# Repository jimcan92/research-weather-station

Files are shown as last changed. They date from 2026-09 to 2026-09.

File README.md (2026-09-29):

# Weather Station Sensor Network

ESP32 field sensors → LoRa 915 MHz → Raspberry Pi gateway → Ryzen 5 server (PostgreSQL + Grafana)

## Architecture

```
ESP32 Nodes (solar + battery)
  │  Sensors: BME280, DS18B20, rain gauge, anemometer, wind vane, soil moisture
  │  Radio:   E22-900T22D UART LoRa @ 915 MHz band
  │  Firmware: PlatformIO / Arduino framework
  │
  ▼ LoRa packets (JSON)
Raspberry Pi Gateway (near server)
  │  HAT:      LoRa concentrator or single-channel SX1276
  │  Software: Python MQTT bridge (lora_gateway.py)
  │
  ▼ MQTT (mosquitto)
Ryzen 5 Server (Ubuntu)
  │  Ingestor: Node.js/TypeScript → PostgreSQL
  │  Dashboard: Grafana (future: SvelteKit)
  └── PostgreSQL: raw readings + daily aggregates
```

## Repository Structure

```
weather-station/
├── firmware/weather-node/   # ESP32 PlatformIO project
│   └── src/
│       ├── main.cpp         # Entry point, deep sleep loop
│       ├── config.h         # Per-node config (pins, ID, calibration)
│       ├── sensors.cpp      # Sensor reading (BME280, DS18B20, etc.)
│       ├── lora.cpp         # E22 transparent-UART driver (M0/M1/AUX)
│       └── packet.cpp       # Packet serialization (JSON/binary)
├── gateway/                 # RPi LoRa → MQTT bridge
│   ├── lora_gateway.py      # Main gateway script
│   ├── config.yaml          # MQTT + LoRa config
│   └── requirements.txt
├── server/                  # MQTT → PostgreSQL ingestor
│   └── src/
│       ├── index.ts         # MQTT subscriber entry point
│       ├── db.ts            # PostgreSQL connection + auto-migrate
│       ├── ingest.ts        # Packet parsing + insert
│       └── config.ts        # Environment config
├── database/
│   ├── migrations/          # SQL migration files
│   └── seeds/               # Sample data
├── docker-compose.yml       # Local dev: Postgres + Mosquitto + Grafana
├── mosquitto.conf           # MQTT broker config
├── grafana/                 # Grafana provisioning
├── docs/                    # Architecture, wiring, deployment guides
└── weather-station.code-workspace  # VS Code multi-root workspace
```

## Quick Start (Development)

### 1. Start infrastructure

```bash
docker compose up -d
```

This starts: PostgreSQL (5432), Mosquitto MQTT (1883), Grafana (3000).

### 2. Install server dependencies

```bash
cd server
cp .env.example .env
npm install
npm run dev
```

### 3. Test the MQTT pipeline

```bash
# Publish a test packet
mosquitto_pub -t "weather/raw" -m '{"n":1,"t":29.4,"h":78,"p":1013,"b":3.8,"r":2,"ws":1.5,"wd":180,"sm":42}'

# Check PostgreSQL
psql -h localhost -U weather_ingestor -d weather_station \
  -c "SELECT * FROM sensor_readings ORDER BY received_at DESC LIMIT 5;"
```

### 4. Gateway setup (on Raspberry Pi)

```bash
cd gateway
sudo apt install python3-pip
pip3 install -r requirements.txt
# Edit config.yaml: set mqtt.broker to your server IP
sudo python3 lora_gateway.py
```

### 5. ESP32 node setup

```bash
# Install PlatformIO: https://platformio.org/install
cd firmware/weather-node
# Edit src/config.h: set NODE_ID, verify pin assignments
pio run -t upload -t monitor
```

## VS Code Remote Development

Open `weather-station.code-workspace` via VS Code Remote SSH.
The workspace groups all sub-projects into separate root folders.

## Production Notes

- Change PostgreSQL + Mosquitto passwords (use `.env`, never commit `.env`)
- Enable Mosquitto authentication: `mosquitto_passwd` + set `allow_anonymous false`
- Set `SLEEP_INTERVAL_S` to 120-300 for production nodes (5s for testing only)
- Use a LoRa concentrator HAT (SX1302) on the RPi for >10 nodes
- Set up systemd services for the ingestor and gateway for auto-start

## License

MIT — Jimboy Cantila, 2025

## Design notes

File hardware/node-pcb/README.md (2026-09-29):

# Weather node schematic

`weather-node-complete.kicad_sch` is the current complete schematic (v2.1, 2026-09-29).
`gen_node_complete.py` is its generator; `DIYMORE-RS485.kicad_sym` defines the new U4 module.

`rs485-module-wiring.svg` shows the revised RS485 wiring. **UART signal directions remain provisional**; see `../../docs/sensor-wiring.md` before wiring.

The existing `weather-node-complete.pdf`, `weather-node-complete.svg/`, and PNG previews are older MAX485 exports and must be regenerated with KiCad before use. The older `weather-node.kicad_sch` is not the canonical complete design.

KiCad ERC and generator execution were unavailable in this environment. Native syntax and affected pin/net connections were checked with a local S-expression reader.

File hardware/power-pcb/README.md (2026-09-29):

# Weather Station — Power Supply PCB v3.0

> **Archived LM2596 alternative:** This board is not the selected final weather-node power design. Use `hardware/node-pcb/weather-node-complete.kicad_sch` (Mini560 12V→5V + AMS1117-3.3).

## Architecture: LM2596-5.0 + AMS1117-3.3

```
12-24V DC → PTC 5A → SS34 → 100µF/35V → LM2596-5.0 → +5V rail
                                         │               └→ AMS1117-3.3 → +3.3V rail
                                         │
                                         └→ IRF9540N + 2N7000 MOSFET switch → 12V_SW (wind sensors)
                                         └→ 330k + 100k voltage divider → BAT_ADC
```

## Board Specs
- KiCad 9.0 format (`version 20250114`)
- A4 schematic — 24 components, net labels as wiring reference
- No wires in schematic — Jim routes connections in KiCad GUI on Windows

## BOM (24 components)

| Ref | Value | Qty | Package | Purpose |
|-----|---|-----|---|---|
| J1 | DC_IN_12-24V | 1 | Barrel Jack | DC power input |
| F1 | PTC_5A | 1 | THT | Overcurrent protection |
| D1 | SS34 | 1 | DO-214AB | Reverse polarity protection |
| C1 | 100µF/35V | 1 | THT electrolytic | Input bulk capacitor |
| C2 | 100nF | 1 | THT ceramic | Input decoupling |
| **U1** | **LM2596-5.0** | 1 | TO-220-5 | 12-24V→5V buck (3A) |
| D2 | SS34 | 1 | DO-214AB | Catch diode |
| L1 | 68µH | 1 | THT | Buck inductor |
| C3 | 220µF/16V | 1 | THT electrolytic | 5V output bulk |
| C4 | 10µF | 1 | THT ceramic | 5V decoupling |
| **U2** | **AMS1117-3.3** | 1 | SOT-223 | 5V→3.3V LDO (1A) |
| C5 | 100nF | 1 | THT ceramic | 3.3V input |
| C6 | 10µF | 1 | THT ceramic | 3.3V output |
| Q1 | IRF9540N | 1 | TO-220 | P-ch MOSFET (12V switch) |
| Q2 | 2N7000 | 1 | TO-92 | N-ch level shifter |
| R1 | 10k | 1 | THT | Gate pull-up |
| R2 | 1k | 1 | THT | GPIO15 gate resistor |
| R3 | 330k | 1 | THT | Battery divider top |
| R4 | 100k | 1 | THT | Battery divider bottom |
| J2 | 12V_SW_OUT | 1 | Screw terminal 2P | Switched 12V (wind sensors) |
| J3 | 5V_OUT | 1 | Screw terminal 2P | 5V output (MAX485) |
| J4 | 3.3V_OUT | 1 | Screw terminal 2P | 3.3V output (ESP32 + sensors) |
| J5 | GPIO15 | 1 | Pin header 2P | MOSFET gate control |
| J6 | BAT_ADC | 1 | Pin header 2P | Battery voltage monitor |

## Voltage Rails

| Rail | Voltage | Max Current | Loads |
|---|---|---|---|
| 12V_SW | 12V (direct from input) | 150mA | RS485 Anemometer + Wind Vane |
| +5V | 5.0V (LM2596) | 3A (module limit) | MAX485 transceiver (~20mA) |
| +3.3V | 3.3V (AMS1117) | 1A (LDO limit) | ESP32-S3, SX1262 LoRa, BME280, LTR390, DS18B20, Soil Moisture, RGB LED |
| BAT_ADC | 0-3.3V (divider 4.30:1) | — | ESP32 ADC pin |

## Total Current Budget @ 12V input (peak)

| Rail | Load Current | Equivalent @ 12V |
|---|---|---|
| 3.3V | ~430mA (ESP32 + LoRa TX + sensors) | ~139mA |
| 5V | ~20mA (MAX485 TX) | ~10mA |
| 12V_SW | ~150mA (wind sensors) | ~150mA |
| **Total** | | **~300mA** |

5A PTC fuse provides ~16× headroom for surge/short protection.

## Ordering

Schematic: `weather-power-v3.kicad_sch` — open in KiCad 9.0+
PCB: Jim routes manually in KiCad on Windows after SCP transfer:
```
scp jimcan@100.110.102.18:/home/jimcan/dev/projects/weather-station/hardware/power-pcb/weather-power-v3.kicad_sch ./
```

## Compare: v2.0 (Mini560) vs v3.0 (LM2596)

| Aspect | v2.0 (Mini560) | v3.0 (LM2596) |
|---|---|---|
| 5V buck | Mini560 module (17×11mm) | LM2596-5.0 (TO-220-5) |
| 3.3V | Mini560 module (separate) | AMS1117-3.3 cascaded from 5V |
| Availability | AliExpress | Shopee/Lazada (same as vending machine) |
| Assembly | SMD modules | THT (Jim solders) |
| Quiescent | ~200µA | ~10mA |
| Same as vending machine? | ❌ | ✅ |

---
Generated by Hermes Agent — June 29, 2026

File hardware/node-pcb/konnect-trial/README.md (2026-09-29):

# Konnect trial — 2026-09-29

Open `weather-node-complete.kicad_sch` in this folder to inspect the trial. The canonical schematic in the parent folder remains unchanged.

Konnect v0.12.1 (official Linux standalone release) reset 172 Reference/Value field positions to their embedded-library anchors. Three power symbols were moved out of component bodies, and their wire stubs were explicitly replaced using Konnect's wire tools.

Final Konnect checks: zero symbol-geometry overlaps, zero shorted nets, zero orphan items. All pin-to-net mappings across 38 non-power circuit components match the original schematic. Reports are included here. Overlap checks exclude free text, so these results do not prove complete visual cleanliness.

KiCad CLI is not installed in this environment: full visual rendering and ERC remain unverified. This is a limited layout cleanup trial, not the proposed multi-sheet redesign. RS485 UART direction remains provisional as noted on the schematic.

The release's `move_connected` is not implemented; `move_region` also leaves wires in place. Do not rely on either to preserve connections automatically. The binary was run from `/tmp/konnect-trial/konnect`; no persistent MCP registration or skill installation was made.

Source: https://github.com/mixelpixx/Konnect/releases/tag/v0.12.1

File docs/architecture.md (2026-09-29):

# Architecture Overview

## System Data Flow

```mermaid
graph LR
    A[ESP32 Node 1] -->|LoRa 915 MHz| G[RPi Gateway]
    B[ESP32 Node 2] -->|LoRa| G
    C[ESP32 Node N] -->|LoRa| G
    G -->|MQTT| S[Ryzen 5 Server]
    S -->|INSERT| P[(PostgreSQL)]
    P -->|Query| GF[Grafana Dashboard]
    P -->|API| SK[SvelteKit Web App]
```

## Component Details

### ESP32 Sensor Nodes

- **MCU:** ESP32-WROOM-32 or C3
- **Framework:** Arduino via PlatformIO
- **Power:** Solar panel + Li-Ion battery + charge controller
- **Sleep:** ESP32 deep sleep (10 µA), wakes on timer, reads sensors, transmits, sleeps
- **Radio:** E22-900T22D UART LoRa module, 915 MHz band, transparent mode at 9600 baud
- **Sensors:** BME280 (T/H/P), DS18B20 (T), rain gauge, anemometer, wind vane, soil moisture

### Raspberry Pi Gateway

- **Role:** Receives LoRa packets from all field nodes, forwards to MQTT
- **Hardware:** RPi 3B+/4/5 + LoRa HAT (single SX1276 or multi-channel SX1302 concentrator)
- **Software:** Python `lora_gateway.py` (polling-based RX → MQTT publish)
- **Location:** Near the Ryzen 5 server (no field deployment needed)

### Central Server (Ryzen 5 / Ubuntu)

- **MQTT Broker:** Mosquitto — receives raw sensor payloads
- **Ingestor:** Node.js/TypeScript service — subscribes to MQTT, inserts into PostgreSQL
- **Database:** PostgreSQL 16 — raw readings + daily aggregates + node registry
- **Visualization:** Grafana — dashboards from PostgreSQL queries
- **Future:** SvelteKit web dashboard with shadcn-svelte UI

## Radio Configuration

The E22 stores channel, air data rate and TX power in its own nonvolatile registers.
Configure both field-node and gateway radios identically before deployment. The ESP32
firmware transports payloads over UART and does not change these air settings at runtime.

| Parameter | Value | Notes |
|---|---|---|
| ESP32↔E22 UART | 9600 baud, 8N1 | Transparent serial transport |
| Normal mode | M0=LOW, M1=LOW | Send/receive weather payloads |
| Sleep mode | M0=HIGH, M1=HIGH | Entered before ESP32 deep sleep |
| AUX | HIGH = ready | Firmware waits up to 3 seconds |
| RF channel | Configure in E22 NVS | Must be in the 915 MHz band and match gateway |
| Air data rate / TX power | Configure in E22 NVS | Must match the receiving E22 module |

## Packet Format

JSON (default, for debugging):
```json
{"n":1,"t":29.4,"h":78.2,"p":1013.2,"b":3.72,"r":5,"ws":2.1,"wd":180,"sm":42}
```

Binary (compact, ~20 bytes): See `packet.h` for structure.

## Scaling

- **1-5 nodes:** Single-channel SX1276 gateway is fine
- **5-20 nodes:** Multi-channel SX1302 concentrator HAT recommended
- **20+ nodes:** ChirpStack Gateway OS + Network Server for LoRaWAN-class management

## Security

- MQTT: In production, add TLS + username/password auth
- PostgreSQL: Use strong passwords, restrict to localhost or VPN
- ESP32: No sensitive data — weather readings only, but consider LoRa encryption for integrity

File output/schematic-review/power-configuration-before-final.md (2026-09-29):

# Weather Node — Power Supply Configuration

**Board:** ESP32-S3 N16R8 (HW678 v0.0.0)  
**Project:** Weather Station Research  
**Date:** June 29, 2026  
**Revision:** v3.0 — LM2596 + AMS1117 architecture (same as vending machine)  
**Related:** `docs/pin-configuration-guide.md`, `hardware/power-pcb/weather-power-v3.kicad_sch`

---

## Architecture: LM2596-5.0 + AMS1117-3.3 (Same as vending machine)

Single LM2596-5.0 buck converter (12-24V→5V) + AMS1117-3.3 LDO (5V→3.3V) cascaded.
Proven design from vending machine v3.0/v4.0 — parts available on Shopee/Lazada.

```
                         ┌──────────────────────┐
                         │    12-24V DC INPUT      │
                         │  (barrel jack or        │
                         │   screw terminal)       │
                         └──────────┬───────────┘
                                    │
               Phase 1             │           Phase 2
          ┌────────────────────────┼──────────────────────┐
          │                        │                      │
          ▼                        ▼                      ▼
   ┌────────────┐          ┌──────────────┐       ┌──────────────┐
   │ 12V 2A     │          │ Solar 30-50W │       │ Solar + Batt │
   │ Adapter    │          │  + CN3791    │       │  (hybrid)    │
   │ (bench)    │          │  + 3S Li-Ion │       │              │
   └────────────┘          └──────────────┘       └──────────────┘
          │                        │                      │
          └────────────────────────┼──────────────────────┘
                                   │
                        ┌──────────┴──────────┐
                        │    INPUT PROTECTION   │
                        │  PTC 5A + SS34 +      │
                        │  100µF/35V + 100nF    │
                        └──────────┬──────────┘
                                   │
           ┌───────────────────────┼───────────────────────┐
           │                       │                       │
           ▼                       ▼                       ▼
   ┌───────────────┐     ┌───────────────┐      ┌──────────────────┐
   │ LM2596-5.0    │     │ AMS1117-3.3   │      │ MOSFET Switch    │
   │ 12V → 5V      │     │ 5V → 3.3V     │      │ (GPIO15 → Gate)  │
   │ + SS34 + 68µH │     │ + 100nF+10µF │      │ 12V → 12V_SW     │
   │ + 220µF+10µF│     │               │      │                  │
   └───────┬───────┘     └───────┬───────┘      └────────┬─────────┘
           │                     │                        │
           ▼                     ▼                        ▼
   ┌───────────────┐     ┌───────────────┐      ┌──────────────────┐
   │ 5V BUS         │     │ 3.3V BUS       │      │ 12V_SWITCHED     │
   │                │     │                │      │                  │
   │ MAX485         │     │ ESP32-S3       │      │ RS485 Anemometer │
   │                │     │ LoRa SX1262    │      │ RS485 Wind Vane  │
   └────────────────┘     │ BME280         │      └──────────────────┘
                          │ LTR390         │
                          │ DS18B20        │
                          │ Rain (passive) │
                          │ Soil Moisture  │
                          │ RGB LED(WS2812)│
                          └───────────────┘

           ┌───────────────┐
           │ BATTERY MON.   │
           │ 330k + 100k    │
           │ divider (4.30) │
           │ → BAT_ADC      │
           └───────────────┘
```

> **Why LM2596 + AMS1117 instead of dual Mini560?** Same parts as vending machine — Jim already knows the design, parts are on Shopee/Lazada, no tuning needed (fixed-voltage versions). LM2596 is TO-220 through-hole, easy to solder. Quiescent current (~10mA) is negligible with a 30W solar panel.

---

## Architecture: Two Parallel Mini560 Bucks from 12V Rail

Two independent Mini560 buck converters run in parallel from the 12V rail. No cascading — each buck converts 12V directly to its target voltage.

```
                         ┌──────────────────────┐
                         │    12V DC INPUT        │
                         │  (barrel jack or        │
                         │   screw terminal)       │
                         └──────────┬───────────┘
                                    │
               Phase 1             │           Phase 2
          ┌────────────────────────┼──────────────────────┐
          │                        │                      │
          ▼                        ▼                      ▼
   ┌────────────┐          ┌──────────────┐       ┌──────────────┐
   │ 12V 2A     │          │ Solar 30-50W │       │ Solar + Batt │
   │ Adapter    │          │  + CN3791    │       │  (hybrid)    │
   │ (bench)    │          │  + 3S Li-Ion │       │              │
   └────────────┘          └──────────────┘       └──────────────┘
          │                        │                      │
          └────────────────────────┼──────────────────────┘
                                   │
                        ┌──────────┴──────────┐
                        │    12V COMMON RAIL   │
                        │  (reverse-polarity   │
                        │   Schottky + 100µF)  │
                        └──────────┬──────────┘
                                   │
           ┌───────────────────────┼───────────────────────┐
           │                       │                       │
           ▼                       ▼                       ▼
   ┌───────────────┐     ┌───────────────┐      ┌──────────────────┐
   │ Buck #1       │     │ Buck #2       │      │ MOSFET Switch    │
   │ 12V → 5V      │     │ 12V → 3.3V    │      │ (GPIO15 → Gate)  │
   │ Mini560 (5V)  │     │ Mini560 (3.3V)│      │ 12V → 12V_SW     │
   └───────┬───────┘     └───────┬───────┘      └────────┬─────────┘
           │                     │                        │
           ▼                     ▼                        ▼
   ┌───────────────┐     ┌───────────────┐      ┌──────────────────┐
   │ 5V BUS         │     │ 3.3V BUS       │      │ 12V_SWITCHED     │
   │                │     │                │      │ (sensor bus)     │
   │ MAX485         │     │ ESP32-S3       │      │                  │
   │                │     │ LoRa SX1262    │      │ RS485 Anemometer │
   └────────────────┘     │ BME280         │      │ RS485 Wind Vane  │
                          │ LTR390         │      └──────────────────┘
                          │ DS18B20        │
                          │ Rain (passive) │
                          │ Soil Moisture  │
                          │ RGB LED(WS2812)│
                          └───────────────┘
```

> **Why parallel bucks instead of buck→LDO?** Two Mini560 modules are simpler to source (no separate LDO IC + caps to solder), each is jumper-set to a fixed voltage, and the quiescent current of ~200µA total (2 × 100µA) is trivial on a solar-charged 12V battery. The 12V→3.3V direct conversion also runs cooler at ESP32 loads (~30mA) than cascading through 5V first.

---

## Buck Converter #1: 12V → 5V (Mini560, fixed 5V output)

### Module Settings

| Parameter | Value |
|---|---|
| Module | Mini560 DC-DC Buck (MP1584-based) |
| Input | 7–28V DC |
| Output | **5.0V fixed** (solder jumper selected) |
| Max current | 3A continuous |
| Efficiency | ~88–92% at 50–200mA |
| Quiescent (Iq) | ~100µA |
| Size | ~17×11mm |

### Jumper Configuration

The Mini560 has solder pads on the back. Bridge the **5V** pads to set the output. No potentiometer — no tuning needed.

```
Mini560 back side:
┌──────────────┐
│ ○  ○  ○  ○  │  3.3V  5V  9V  12V  pads
│              │
│  ══          │  Bridge the 5V pads with solder blob
│              │
└──────────────┘
```

### Capacitors (Add for Stability)

```
12V IN ──┬── 100µF/25V electrolytic ── GND
         │
         └── Mini560 Vin+
               Mini560 Vin- ── GND
               Mini560 Vout+ ──┬── 100µF/16V electrolytic ── GND
                              │
                              └── 5V BUS → MAX485 VCC
```

---

## Buck Converter #2: 12V → 3.3V (Mini560, fixed 3.3V output)

### Module Settings

| Parameter | Value |
|---|---|
| Module | Mini560 DC-DC Buck (MP1584-based) |
| Input | 7–28V DC |
| Output | **3.3V fixed** (solder jumper selected) |
| Max current | 3A continuous |
| Efficiency | ~85–90% at 30–100mA |
| Quiescent (Iq) | ~100µA |
| Size | ~17×11mm |

### Jumper Configuration

Bridge the **3.3V** pads:

```
Mini560 back side:
┌──────────────┐
│ ○  ○  ○  ○  │  3.3V  5V  9V  12V  pads
│              │
│ ══           │  Bridge the 3.3V pads with solder blob
│              │
└──────────────┘
```

### Capacitors

```
12V IN ──┬── 100µF/25V electrolytic ── GND
         │
         └── Mini560 Vin+
               Mini560 Vin- ── GND
               Mini560 Vout+ ──┬── 100µF/16V electrolytic ── GND
                              │
                              └── 3.3V BUS → ESP32 + LoRa + BME280 + LTR390 + DS18B20 + Soil
```

> ⚠️ Double-check the 3.3V jumper before power-up. A misconfigured module set to 12V will kill the ESP32 instantly. Measure Vout with multimeter before connecting anything.

---

## MOSFET Switch: GPIO15 → 12V Sensor Bus

*(Unchanged from v1.0)*

The ESP32 GPIO15 outputs 3.3V, but we need to switch a 12V rail. A two-transistor level shifter does this:

```
12V ────────┬─────────────── IRF9540 Source (P-channel MOSFET)
            │
            └──[10kΩ]──┬── IRF9540 Gate
                       │
                       ├── 2N7000 Drain (N-channel MOSFET)
                       │
                       │   2N7000 Source ── GND
                       │
GPIO15 ────[1kΩ]───────┼── 2N7000 Gate
                       │
                      GND

IRF9540 Drain ──► 12V_SWITCHED (wind sensors)
```

### How It Works

| GPIO15 | 2N7000 | IRF9540 Gate | IRF9540 | 12V_SW |
|---|---|---|---|---|
| LOW (0V) | OFF | Pulled to 12V via 10kΩ | OFF | 0V |
| HIGH (3.3V) | ON | ~0V (pulled to GND) | ON | 12V |

### Parts

| Part | Package | Price |
|---|---|---|
| IRF9540 | TO-220 | ₱30 |
| 2N7000 | TO-92 | ₱10 |
| 10kΩ resistor | 1/4W | ₱1 |
| 1kΩ resistor | 1/4W | ₱1 |

---

## Perf Board Layout (7×9 cm)

```
┌──────────────────────────────────────────────────────────┐
│                  POWER PERF BOARD                         │
│                   (7×9 cm, top view)                      │
│                                                           │
│  ┌─────────────┐                                          │
│  │ 12V INPUT    │    ┌────────────────┐  ┌────────────┐  │
│  │ Barrel Jack  │    │ Mini560 #1     │  │ Mini560 #2 │  │
│  │              │    │ 12V → 5V       │  │ 12V→3.3V   │  │
│  │ (+) ────────┬────│─ Vin+          │  │            │  │
│  │ (-) ────┐   │    │  Vin- ───┐     │  │            │  │
│  └─────────│───│────│─ Vout+    │     │  │            │  │
│            │   │    │  Vout- ───│──┐  │  │            │  │
│            │   │    └───────────│──│──│──│─ Vin+      │  │
│            │   │               │  │  │  │  Vin- ───┐ │  │
│  12V BUS   ▼   ▼               │  │  │  │  Vout+   │ │  │
│  ───────────────────           │  │  │  │  Vout- ──│─│──│── 3.3V OUT
│  │  +  │  │  -  │              │  │  │  └──────────│─│──│── GND
│  │     │  │     │              │  │  │             │ │  │
│  │ 12V │  │ GND │              │  │  │             │ │  │
│  │ BUS │  │ BUS │              │  │  │             │ │  │
│  └──┬──┘  └──┬──┘              │  │  │             │ │  │
│     │        │                 │  │  │             │ │  │
│     │        └────── GND ──────┴──┴──┴─────────────┘ │  │
│     │                                                  │  │
│     ├──► Wind Sensors (12V) via MOSFET SW              │  │
│     ├──► Mini560 #1 Vin+                                │  │
│     └──► Mini560 #2 Vin+                                │  │
│                                                         │  │
│  ┌───────────────────────────────────────────────┐     │  │
│  │            OUTPUT TERMINALS                     │     │  │
│  │                                                │     │  │
│  │  [12V_SW] [GND]  [5V] [GND]  [3.3V] [GND]    │     │  │
│  │                           [GPIO15] [BAT_ADC]  │     │  │
│  └───────────────────────────────────────────────┘     │  │
│                                                         │  │
│  ┌────────────────────────┐                             │  │
│  │ MOSFET SW              │                             │  │
│  │ IRF9540 + 2N7000       │                             │  │
│  │ 10kΩ + 1kΩ             │                             │  │
│  └────────────────────────┘                             │  │
└──────────────────────────────────────────────────────────┘
```

### Perf Board Wiring Checklist

- [ ] Barrel jack soldered at edge (12V IN)
- [ ] Schottky diode (1N5819) in series with 12V+ for reverse-polarity protection
- [ ] 100µF/25V electrolytic across 12V input (polarity: stripe = negative)
- [ ] Thick power bus traces for 12V and GND (use solder bridges or solid wire)
- [ ] Mini560 #1 (5V) mounted — **verify jumper is on 5V pads**
- [ ] 100µF/16V electrolytic across Mini560 #1 output
- [ ] Mini560 #2 (3.3V) mounted — **verify jumper is on 3.3V pads**
- [ ] 100µF/16V electrolytic across Mini560 #2 output
- [ ] MOSFET level-shifter circuit in one corner
- [ ] Screw terminal block for each output: 12V_SW, 5V, 3.3V
- [ ] GPIO15 header pin for MOSFET gate signal
- [ ] BAT_ADC header pin for battery voltage divider tap
- [ ] All GNDs tied to common ground bus
- [ ] Heat shrink tubing on exposed 12V connections

### Wire Gauge Guide

| Connection | Recommended Wire |
|---|---|
| 12V input / bus | 22–20 AWG solid core |
| 3.3V / 5V signal | 24–26 AWG |
| Sensor power runs | 24 AWG |
| High-current paths (>500mA) | 20 AWG |

---

## Voltage Divider: 12V Battery Monitoring

The divider is sized for a 12V battery (3S Li-Ion: 9.0V–12.6V, or 12V SLA: 10.5V–13.8V).

```
Battery (+) 12.6V max
    │
  [330kΩ]     ← R1 (top resistor)
    │
    ├──── GPIO14 (ADC2)   ← Max = 12.6 × 100/(100+330) = 2.93V (safe)
    │
  [100kΩ]     ← R2 (bottom resistor)
    │
   GND
```

| Parameter | Value |
|---|---|
| R1 (top) | 330kΩ |
| R2 (bottom) | 100kΩ |
| Divider ratio | 0.2326 |
| Max ADC voltage | 2.93V (at 12.6V battery) |
| Min ADC voltage | 2.09V (at 9.0V battery) |

**Formula:** `V_battery = V_adc × (330 + 100) / 100 = V_adc × 4.30`

### Firmware Config

In `config.h`:

```c
#define BAT_R1  330.0   // kΩ (top resistor)
#define BAT_R2  100.0   // kΩ (bottom resistor)
```

---

## RS485 Wind Sensor Power

### Wind Sensor Supply (12V Direct)

The RS485 anemometer and wind vane need 12-24V DC. They connect to the **12V_SWITCHED** output (controlled by GPIO15 via MOSFET).

```
12V_SW ──┬── Anemometer V+ (red/brown)
         │
         └── Wind Vane V+ (red/brown)

GND ─────┬── Anemometer GND (black)
         │
         └── Wind Vane GND (black)
```

### MAX485 Transceiver Supply (5V)

The MAX485 chip runs on 5V (from Mini560 #1):

```
MAX485 Pin              Connect To
─────────               ──────────
VCC                    5V BUS
GND                    GND
RO (RX)                GPIO18 (UART1 RX)
DI (TX)                GPIO17 (UART1 TX)
RE + DE (tied)         GPIO16
A                      RS485 A line → both sensors
B                      RS485 B line → both sensors
```

> **Note:** The MAX485 IC requires 5V. Do NOT connect it to 3.3V — it won't work reliably on long RS485 runs.

---

## Sensor Power Table

| Sensor | Supply Voltage | Rail | Switched? | Notes |
|---|---|---|---|---|
| ESP32-S3 | 3.3V | 3.3V BUS | No | Always powered or deep sleep |
| E22-900T22D | 5V | 5V BUS | No | Mode 3 sleep via M0=HIGH, M1=HIGH |
| BME280 | 3.3V | 3.3V BUS | No | ~0.5mA active, 0.1µA sleep |
| LTR390 | 3.3V | 3.3V BUS | No | ~0.3mA active |
| DS18B20 | 3.3V | 3.3V BUS | No | ~1mA active |
| Rain Gauge | — | — | No | Passive reed switch |
| Soil Moisture | 3.3V | 3.3V BUS | No | Read via ADC |
| RGB LED (WS2812) | 3.3V | 3.3V BUS | No | Built into dev board |
| MAX485 | 5.0V | 5V BUS | No | Always powered (~1mA) |
| RS485 Anemometer | 12V | 12V_SW | **Yes (GPIO15)** | ~20-50mA active |
| RS485 Wind Vane | 12V | 12V_SW | **Yes (GPIO15)** | ~20-50mA active |

> Low-voltage sensors (3.3V bus) stay always-on and manage their own sleep states. The MOSFET switch controls only the 12V wind sensor rail.

---

## Current Budget (12V System)

### Sleep State

| Component | Current @ 12V | Notes |
|---|---|---|
| Mini560 #1 (5V) quiescent | ~100µA | Always-on |
| Mini560 #2 (3.3V) quiescent | ~100µA | Always-on |
| ESP32 deep sleep | ~10µA @ 3.3V ≈ 3µA @ 12V | After buck |
| E22 mode 3 | Verify with ammeter | Module/batch dependent; M0=M1=HIGH |
| BME280 sleep | ~0.1µA @ 3.3V | |
| MAX485 idle | ~1mA @ 5V ≈ 0.4mA @ 12V | After buck |
| Wind sensors | 0mA | MOSFET OFF (GPIO15 LOW) |
| **Total Sleep** | **~0.6mA @ 12V** | |

### Active State (~2 seconds per cycle)

| Component | Current @ 12V |
|---|---|
| ESP32 (80MHz, WiFi off) | ~27mA |
| LoRa TX burst (17dBm) | ~40mA |
| Sensors (BME280+LTR390+DS18B20+Soil) | ~5mA |
| MAX485 active | ~0.5mA |
| Wind sensors (12V direct) | 50mA |
| Buck conversion losses (~10%) | ~12mA |
| **Total Active** | **~135mA @ 12V** |

### Daily Energy (5-min sleep interval, 288 cycles/day)

| Phase | Calculation | Energy |
|---|---|---|
| Sleep: 0.6mA × 23.92h | | 14.4 mAh |
| Active: 135mA × (288 × 2s / 3600) | = 135mA × 0.16h | 21.6 mAh |
| **Daily Total** | | **36.0 mAh @ 12V** |
| **Daily Wh** | 36.0mAh × 12V | **0.43 Wh** |

### Battery Runtime

| Battery | Capacity @ 12V | Runtime (no solar) |
|---|---|---|
| 3S 18650 3000mAh | 3000mAh | ~83 days |
| 3S 18650 3500mAh | 3500mAh | ~97 days |
| 12V 7Ah SLA | 3500mAh usable (50% DoD) | ~97 days |
| 12V 9Ah SLA | 4500mAh usable | ~125 days |

> With a 30W solar panel in Philippines sun (~4.5 peak sun hours = 135Wh/day), the system is net-positive by a huge margin. The 0.43Wh/day draw is less than 0.5% of daily solar harvest.

---

## Complete Bill of Materials (BOM)

### Phase 1 — Bench Testing (paliton karon)

| # | Item | Spec | Qty | Unit Price | Total |
|---|---|---|-----|---|---|
| 1 | 12V DC Adapter | 12V 2A, 5.5×2.1mm barrel plug | 1 | ₱200 | ₱200 |
| 2 | DC Barrel Jack | 5.5×2.1mm female, panel mount, screw terminals | 1 | ₱40 | ₱40 |
| 3 | Schottky Diode | 1N5819, 1A 40V (reverse-polarity protection) | 1 | ₱5 | ₱5 |
| 4 | **Mini560 Buck Module** | 5V fixed output (jumper-selectable) | 1 | ₱85 | ₱85 |
| 5 | **Mini560 Buck Module** | 3.3V fixed output (jumper-selectable) | 1 | ₱85 | ₱85 |
| 6 | IRF9540 | P-channel MOSFET, TO-220 | 1 | ₱30 | ₱30 |
| 7 | 2N7000 | N-channel MOSFET, TO-92 | 1 | ₱12 | ₱12 |
| 8 | Resistor 10kΩ | 1/4W carbon film | 2 | ₱1 | ₱2 |
| 9 | Resistor 1kΩ | 1/4W carbon film | 1 | ₱1 | ₱1 |
| 10 | Resistor 330kΩ | 1/4W carbon film (battery divider R1) | 1 | ₱1 | ₱1 |
| 11 | Resistor 100kΩ | 1/4W carbon film (battery divider R2) | 1 | ₱1 | ₱1 |
| 12 | Resistor 4.7kΩ | 1/4W carbon film (DS18B20 pull-up) | 1 | ₱1 | ₱1 |
| 13 | Capacitor 100µF/25V | Electrolytic (input bulk) | 1 | ₱10 | ₱10 |
| 14 | Capacitor 100µF/16V | Electrolytic (output bulk, one per buck) | 2 | ₱8 | ₱16 |
| 15 | **Perf Board** | 7×9 cm, single-sided, 2.54mm pitch | 1 | ₱55 | ₱55 |
| 16 | Screw Terminal Block | 2-pin, 5mm pitch | 4 | ₱15 | ₱60 |
| 17 | Pin Headers | Male 1×40, 2.54mm | 1 strip | ₱20 | ₱20 |
| 18 | Jumper Wires | Male-to-male, 20cm, 40pcs | 1 set | ₱60 | ₱60 |
| 19 | Solid Core Wire | 22 AWG, red+black, 2m each | 1 set | ₱50 | ₱50 |
| 20 | Heat Shrink Tubing | Assorted, 2mm–6mm | 1 set | ₱40 | ₱40 |
| 21 | Dupont Connectors | Male + female crimp pins + housings | 1 set | ₱50 | ₱50 |
| | | | | **Phase 1 Total** | **₱825** |

### Phase 2 — Solar + Battery (paliton unya)

| # | Item | Spec | Qty | Unit Price | Total |
|---|---|---|-----|---|---|
| 22 | Solar Panel | 30–50W, 18Vmp, monocrystalline | 1 | ₱1,200 | ₱1,200 |
| 23 | Li-Ion Cells | 18650, 3500mAh, protected (Samsung/Panasonic) | 3 | ₱250 | ₱750 |
| 24 | 3S BMS Board | 12.6V, 25A, balance charging | 1 | ₱180 | ₱180 |
| 25 | CN3791 Module | Solar charge controller, 1S–4S configurable | 1 | ₱350 | ₱350 |
| 26 | IP65 Enclosure | ABS waterproof box, 200×150×100mm | 1 | ₱450 | ₱450 |
| 27 | Cable Glands | PG7 or PG9, waterproof | 4 | ₱25 | ₱100 |
| 28 | Mounting Bracket | L-bracket + U-bolts for solar panel | 1 set | ₱200 | ₱200 |
| 29 | XT60 Connectors | Male+female pair (battery disconnect) | 2 pairs | ₱40 | ₱80 |
| 30 | Fuse Holder + Fuse | 2A, inline blade type | 1 | ₱60 | ₱60 |
| | | | | **Phase 2 Total** | **₱3,370** |

### Grand Total

| Phase | Total |
|---|---|
| Phase 1 — Bench Testing | ₱825 |
| Phase 2 — Solar + Battery | ₱3,370 |
| **GRAND TOTAL (complete single-node power)** | **₱4,195** |

> **Note:** Prices are estimated from Shopee/Lazada Philippines as of June 2026. ±20% depending on seller and shipping. The BOM is ₱55 more than v1.0 (₱85 extra Mini560 replaces ₱15 HT7333 + 2×₱5 electrolytics — simpler, fewer parts to solder).

---

## Shopee/Lazada Search Terms

| Item | Search Term |
|---|---|
| Mini560 5V | "mini560 buck 5v module fixed" |
| Mini560 3.3V | "mini560 buck 3.3v module fixed" |
| 1N5819 | "1n5819 schottky diode" |
| IRF9540 | "irf9540 p channel mosfet" |
| 2N7000 | "2n7000 mosfet to-92" |
| Perf board | "perf board 7x9 single sided" |
| Barrel jack | "dc barrel jack panel mount 5.5 2.1 screw terminal" |
| Solar panel | "solar panel 30w 18v monocrystalline" |
| 18650 cells | "18650 3500mah protected samsung panasonic genuine" |
| 3S BMS | "3s bms 12.6v 25a balance" |
| CN3791 | "cn3791 solar charge controller module" |
| IP65 enclosure | "ip65 abs junction box waterproof 200x150x100" |
| Cable gland | "pg7 cable gland waterproof" |
| XT60 | "xt60 connector pair" |

---

## Assembly Order

1. **Solder barrel jack** to perf board edge (2 pins: + and -)
2. **Solder 1N5819 Schottky diode** in series with 12V+ (cathode/stripe toward the circuit). This protects against accidental reverse polarity.
3. **Solder 100µF/25V cap** across 12V input (mind polarity — stripe = negative)
4. **Configure Mini560 #1 for 5V** — bridge the 5V pads with solder
5. **Configure Mini560 #2 for 3.3V** — bridge the 3.3V pads with solder
6. **Mount both Mini560 modules** on perf board — DO NOT connect output to anything yet
7. **Power up with 12V adapter**
8. **Measure Mini560 #1 output** — should read 5.0V ±0.1V. If it's way off, the jumper pads may not be bridged properly.
9. **Measure Mini560 #2 output** — should read 3.3V ±0.05V. ⚠️ If it reads >5V, the jumper is wrong — do NOT connect ESP32.
10. **Solder 100µF/16V cap** across each output (one on 5V, one on 3.3V)
11. **Build MOSFET level-shifter** (IRF9540 + 2N7000 + resistors) in one corner
12. **Verify MOSFET switching**: connect GPIO15 to 3.3V → 12V_SW should read ~12V; connect to GND → 12V_SW should be 0V
13. **Solder output terminal blocks** for each voltage rail
14. **Wire sensors** one at a time, testing each before adding the next
15. **Last step**: connect ESP32-S3 to 3.3V and GND

> ⚠️ **Golden Rule:** Always verify Mini560 output voltages with a multimeter BEFORE connecting the ESP32 or any sensor. A misconfigured jumper (wrong voltage) will destroy downstream electronics instantly. Measure twice, connect once.

---

## Quick Reference: Power Pin Assignments

| Function | GPIO | Voltage | Notes |
|---|---|---|---|
| Sensor PWR MOSFET gate | GPIO15 | 3.3V signal | Switches 12V rail via IRF9540 |
| Battery ADC | GPIO14 | 0–2.93V | 330k/100k divider (12V system) |
| 12V_SW | — | 12V (switched) | Wind sensors V+ |
| 5V BUS | — | 5V | MAX485 VCC |
| 3.3V BUS | — | 3.3V | ESP32, LoRa, BME280, LTR390, DS18B20, Soil |

---

## One-Shot Verification

After assembly, run these checks:

```bash
# 1. Measure all rails (disconnected from ESP32 first)
#    12V in:  ~12.0V (adapter) or 9.0–12.6V (battery)
#    5V out:   5.00V ± 0.1V
#    3.3V out: 3.30V ± 0.05V

# 2. Test MOSFET with a 12V LED or multimeter
#    GPIO15 HIGH → 12V_SW = 12V
#    GPIO15 LOW  → 12V_SW = 0V

# 3. Connect ESP32, flash firmware, open serial monitor
cd ~/dev/projects/weather-station/firmware/weather-node
sg dialout -c "pio run -e s3 -t upload -t monitor"

# 4. In serial output, verify battery reading matches multimeter:
#    Battery: 12.XX V (raw=XXXX)   ← should match adapter/battery voltage
```

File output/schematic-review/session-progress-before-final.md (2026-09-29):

# Weather Station — Session Progress Log

## 2026-06-29 to 2026-07-08: Power Supply Design & Shopping

### ✅ Completed

1. **Power Supply Architecture v3.0 — LM2596 + AMS1117**
   - Same design as vending machine for parts availability
   - Schematic generated at `hardware/power-pcb/weather-power-v3.kicad_sch`
   - 24 components, KiCad 9.0 format, net labels as wiring reference
   - See `docs/power-configuration.md` for full architecture

2. **Prototype Decision**
   - Phase 1 (now): Mini560 ×2 on perf board for prototyping
   - Phase 2 (final): Custom PCB with LM2596-5.0 + AMS1117-3.3

3. **Solar + Battery Design**
   - 50W 18V Solar Panel with 10A PWM Controller
   - 4S LiFePO4 32650 cells (6500mAh ×8 for dual pack)
   - 2× 4S 15A BMS + 2× Active Balancer
   - See `docs/power-bom-solar-lifepo4.md` for complete BOM

4. **LiFePO4 Voltage Divider Updated**
   - R3 changed from 330k → **390k** (for 14.6V full charge)
   - Ratio: 4.90 (390k + 100k divider)
   - Firmware: `#define BAT_DIVIDER 4.90`

5. **MOSFET Switch — P-channel parts resolved**
   - IRF4905PBF (replacement for rare IRF9540N) — ₱150
   - 2N7000 N-ch MOSFET for level shifting — ₱120
   - Circuit: GPIO15 HIGH → 2N7000 ON → IRF4905 gate LOW → 12V flows to wind sensors

6. **Complete Shopping Cart — ₱9,860**
   - Battery: 8× 32650, 2× BMS, 2× balancer, hardware
   - Solar: 50W panel + 10A controller, PV cable
   - Power: Mini560 5V+3.3V, MOSFETs, 1N5822, PTC 5A, 1000µF/35V cap
   - Connectors: Terminal blocks, XT60, M12+M16 glands, waterproof 5P
   - Sensors: DS18B20 ×5, OLED 1.3", SD module
   - Enclosure: M3 inserts, screws, 5-core 20AWG cable

7. **Existing Parts (already owned)**
   - BME280, LTR390, ESP32-S3 HW678
   - LoRa module + antenna (SX1278/SX1262)
   - RS485 Wind Sensors (anemometer + wind vane)
   - MAX485 module, soil moisture, rain gauge
   - Resistors (all values)

### 📐 Architecture Decisions

- **2-Box Split Design**: Power box (battery, buck converters) separate from Stevenson screen (ESP32, sensors). Prevents Mini560/ESP32 heat from affecting BME280 temperature accuracy.
- **3D Printed Enclosure**: Jim + partner will design and print.
- **Inter-box cable**: 12V + 5V + GND (3 wires) via waterproof 5P connector.
- **LoRa antenna**: OK to stay inside PLA Stevenson screen (no metal blocking).

### ⚠️ Pending / Not Yet Purchased

- SMA bulkhead pigtail (₱50-100) — only needed if metal enclosure for ESP box
- Waterproof enclosure (3D print instead)
- Cable glands for ground sensors

### 📂 Key Files

| File | Description |
|---|---|
| `hardware/power-pcb/weather-power-v3.kicad_sch` | Power schematic v3.0 (LM2596) |
| `hardware/power-pcb/weather-power-pcb.kicad_sch` | Old power schematic v2.0 (Mini560) |
| `hardware/power-pcb/weather-power-pcb.kicad_pcb` | Old PCB layout v2.0 |
| `hardware/power-pcb/README.md` | Updated for v3.0 |
| `docs/power-configuration.md` | Updated to v3.0 LM2596 architecture |
| `docs/power-bom-solar-lifepo4.md` | Solar + LiFePO4 BOM |
| `docs/power-bom-shopee-complete.md` | Complete Shopee BOM with search keywords |

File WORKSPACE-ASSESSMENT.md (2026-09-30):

# Workspace Assessment — research-weather-station

**Date:** 2026-09-29
**Scope:** Full repository — firmware, gateway, server, database, dashboard, hardware, docs, infra
**Method:** Static read-only analysis + git/toolchain inspection. Nothing was modified.
**Verdict:** A well-organized **research prototype**, not an operating station and not fabrication-ready.
The architecture is sound and honestly documented, but the end-to-end chain has **never been run**,
and three defects break it outright.

---

## 1. Snapshot

| Metric | Value |
|---|---|
| Tracked files | 129 |
| Tracked size | 3.39 MB |
| On-disk size | 415 MB (`.pio` 333 MB, `webui/node_modules` 78 MB — both correctly gitignored) |
| Commits / branch | 3 on `main`, last 0.8 days ago |
| Remote | `github.com/jimcan92/research-weather-station` |
| Uncommitted | 752 insertions across 7 firmware files; untracked `webui/`, `data/`, `partitions_16mb.csv`, `.gitignore`, `.vscode/` |
| CI / tests / lint | **None** anywhere |
| Toolchain present | node, npm, pnpm, docker, git |
| Toolchain missing | `pio` (PlatformIO) — **firmware cannot be built here** |
| Deps installed | `webui/node_modules` only. `server/` and `dashboard/` have **no** `node_modules` → never installed |

**Hygiene — genuinely clean.** No secrets committed (`.env` absent and ignored per `.gitignore:13-15`),
zero BOMs, zero mixed line endings, dependency and build output correctly excluded, 20 of 21 doc path
references resolve. This is better hygiene than most projects at this stage.

**Two frontends exist**, which the README does not make obvious:
`dashboard/` (SvelteKit + Drizzle ops dashboard) and `firmware/weather-node/webui/`
(ESP32 config portal, built into `data/` as a LittleFS image).

---

## 2. Critical findings

### C1. The battery divider has FOUR mutually incompatible values — and the firmware disagrees with all its docs

| Value | Where |
|---|---|
| **5.70** (47k/10k) | `firmware/weather-node/src/config.h:79-84`, printed at `sensors.cpp:249` — **what the code actually does** |
| **4.90** (390k/100k) | `docs/session-progress.md:26-28`, `docs/power-bom-solar-lifepo4.md:85-96`, `hardware/node-pcb/weather-node-complete.kicad_sch:5350` |
| **4.30** (330k/100k) | `docs/pin-configuration-guide.md:218-227`, `docs/power-configuration.md:360`, `docs/sensor-wiring.md:161`, `hardware/power-pcb/README.md:56` |
| **1.45** (100k/220k) | `docs/pin-configuration-guide.md:309` — stale value inside the same file that says 4.30 at line 227 |

`docs/session-progress.md:28` asserts `Firmware: #define BAT_DIVIDER 4.90`. **That is false** —
`config.h` computes 5.70.

**Impact.** A 390k board under a 5.70 constant over-reports pack voltage by ~16%; a 330k board by ~33%.
A healthy 12.8 V LiFePO4 pack reads as ~14.9 V ⇒ the node always believes it is at full charge and
**can over-discharge the pack**, which permanently damages LiFePO4 cells. Separately, the 4.30 design
puts 14.6 V × 100/430 = **3.40 V on GPIO14, above the 3.3 V ADC maximum** — and the doc's own safety
check at `power-configuration.md:360` only computes it at 12.6 V, hiding the overvoltage.

**This is the single highest-priority item.** It cannot be resolved from the repo — the physical board
must be measured, then one value propagated to code, docs, and schematic.

### C2. `battery_v NUMERIC(3,2)` cannot store a pack voltage — silently discards every real reading

`NUMERIC(3,2)` has a maximum of **9.99**. The system reports 4S LiFePO4 pack voltage (12.8 V nominal,
14.6 V full — `docs/power-bom-solar-lifepo4.md:5`), computed in whole volts at `packet.cpp:18`.

The overflow raises an error that `server/src/ingest.ts:94-96` catches and reduces to a log line,
returning `null`. **Every packet from real hardware is dropped.**

Present identically in **both** schema definitions:
- `database/migrations/001_initial_schema.sql:30`
- `server/src/db.ts:46`

It has never been caught because the only test packet in the repo uses `"b":3.8` (`README.md:79`) —
which fits. The bug appears only with real hardware.

Same class of over-precision bug: `humidity` and `soil_moisture` are `NUMERIC(4,1)`, so a legitimate
reading of exactly `100.0` is 5 digits and also overflows.

### C3. Grafana datasource reference mismatch — all ~24 panels are dead

`grafana/datasources/postgres.yml:7-8` provisions `name: WeatherStation` with `type: postgres` and
**no `uid`**. Grafana generates a random UID when `uid` is omitted.

Every panel target references `"uid": "WeatherStation"` with
`"type": "grafana-postgresql-datasource"` (e.g. `weather-station.json:48-49,101-102,159-160` — 88 matches).

Combined with the unpinned `grafana/grafana:latest` image (`docker-compose.yml:44`) against a
`schemaVersion: 39` dashboard, the datasource reference and plugin type must be verified against
whatever version actually pulls. Fix: add `uid: WeatherStation` to `postgres.yml` and align `type`.

---

## 2b. CONFIRMED ON HARDWARE (2026-09-29): GPIO14 over-voltage from a wrong resistor

This section supersedes the theory in C1 and is the highest-priority item in the report. It is a
confirmed physical defect, not a code review finding.

### What was measured

Bench test with the tester board connected to a 12 V battery, divider intended as 47k/10k:

| Measurement | Value |
|---|---|
| GPIO14 → GND | **4.26 V** |
| ESP32-S3 ADC maximum | 3.3 V |
| Absolute maximum (GPIO) | ~3.6 V |
| Battery-side report on `weather.local` | **28.48 V** |

### Root cause

The **top resistor is 4.7 kΩ, not 47 kΩ** — a 10× error. Colour bands differ by one stripe:
`4.7k = yellow·violet·RED` vs `47k = yellow·violet·ORANGE`.

```
Intended ratio:  (47 + 10) / 10 = 5.70
Actual ratio:    (4.7 + 10) / 10 = 1.47
```

| Input | Pin voltage at 1.47 ratio | Correct at 5.70 |
|---|---|---|
| 12.0 V | **8.16 V** | 2.11 V |
| 14.6 V (4S full) | **9.93 V** | 2.56 V |

### Why 4.26 V was measured instead of 8.16 V

The ESP32's input protection diode **clamped** the pin — 4.26 V is the clamp voltage, not the divider
output. This proves current has been **injected into the GPIO**:

```
I_R1 = (12.0 − 4.26) / 4.7k  = 1.65 mA
I_R2 = 4.26 / 10k            = 0.43 mA
I_diode into the 3.3 V rail  = 1.22 mA     (≈1.8 mA at 14.6 V)
```

That is outside the datasheet specification. The clamp is the only reason the pin did not see 8–10 V —
the ESD diode absorbed the fault. The clamped, over-range pin also explains the impossible 28.48 V
report: the ADC saturated above its ~3.1 V range and the calibration curve extrapolated.

### Impact on finding C1

**The firmware is correct and the docs are wrong.** `config.h:84` computes
`(BAT_R1 + BAT_R2) / BAT_R2 = (47 + 10) / 10 = 5.70`, which is the right and safe ratio for a 4S
LiFePO4 pack. The 4.30 (330k/100k) value still present in `pin-configuration-guide.md:227`,
`power-configuration.md:360` and `sensor-wiring.md:161` would put **3.40 V** on GPIO14 at 14.6 V —
also an over-voltage. The 4.90 (390k/100k) in `session-progress.md:26-28` and the canonical schematic
is safe but does not match the code. **Only 5.70 (47k/10k) is both safe and consistent with the
firmware.**

### Fix

1. **Replace the top resistor 4.7 kΩ → 47 kΩ.** No code change required — `BAT_DIVIDER` already
   evaluates to 5.70.
2. Verify the bottom resistor is genuinely 10 kΩ (if the top was misread, the bottom may be too).
3. Confirm GPIO14 ≈ **2.11 V** at 12 V in, and ≈ 2.56 V at 14.6 V.
4. **Verify the pin survived.** Sweep a known input (6/9/12/14 V) and confirm the serial readings are
   linear. Non-linear, offset, or stuck readings mean the pin is damaged and battery sensing must move
   to an **ADC1** pin (GPIO1–GPIO10; GPIO9 appears free). Moving to ADC1 also removes the ADC2/WiFi
   conflict described in H-notes below.
5. **Add protection, now clearly warranted:** a 1 kΩ series resistor between the divider midpoint and
   GPIO14 to bound future diode current, plus a 100 nF cap from GPIO14 to GND for ADC sampling
   (schematic `C6`).

### Follow-up: sense tap moved, and the reading now needs filtering (all applied and verified)

Two further problems showed up once the divider was correct, and both are fixed and flashed.

**1. The tap sat after the Schottky, so the pack read ~0.33 V low.**

`gen_node_complete.py:156-158` puts the sense tap on the **cathode** of D1 (`12V_BUS`) — i.e. after
the PTC fuse *and* after the 1N5822. Measured on the bench: **12.94 V at the battery, 12.61 V at the
tap.** On LiFePO4's flat curve that 0.33 V is worth roughly **20 percentage points** of state of charge
(12.61 V ⇒ 15 %, 12.94 V ⇒ 35 %).

The tap was moved to the anode side — **after the fuse, before the diode** — keeping the sense line
fused while dropping the error from 330 mV to **~13 mV** (the residual is the PTC fuse drop at
~150 mA), plus the recommended 1 kΩ series resistor.

**2. A single ADC sample made the gauge flicker.**

`readBatteryVoltage()` took **one** `analogReadMilliVolts()` reading, and `main.cpp` converted the ADC
**three times** per cycle, so `battery_v` and `battery_raw_mv` came from unrelated samples. Measured
spread was **28 mV** at the pack — and because 12 mV is already 1 % of SoC on this chemistry, the gauge
visibly flickered.

Implemented in `sensors.cpp` / `config.h`:

- **Oversample** `BAT_ADC_SAMPLES` (32) times, discard the extreme samples, average.
- **Cache** the averaged sample for `BAT_ADC_CACHE_MS` (500 ms) so every caller in one cycle — the
  LoRa payload, the telemetry cache, and the raw-mV readout — reports the *same* conversion.
- **EMA** across cycles (`BAT_ADC_EMA_ALPHA` 0.25) for the residual variation, which is real load sag
  from WiFi bursts rather than ADC noise. A step larger than `BAT_ADC_EMA_SNAP_V` (0.5 V) snaps
  instead of slewing, so reconnecting a battery is not lagged.
- `battery_raw_mv` deliberately stays **unsmoothed** for debugging.

Measured after flashing, 14 cycles:

| Metric | Before | After |
|---|---|---|
| Pack voltage spread | 28 mV | **10 mV** |
| Raw ADC spread | 5 mV | **2 mV** |
| Sequence | 12.92 ↔ 12.93 flicker | **monotonic drift** 12.920 → 12.930 |
| Accuracy vs 12.94 V battery | −330 mV | **−13 mV** |

### NEW: the MOSFET switch never turns on if R2 is missing — and the UI cannot tell

The node reports `12V_SW MOSFET: ON` while the multimeter reads **0 V** at J2. The UI flag is not a
measurement: `getMosfetState()` returns the `mosfetActive` software flag set by `digitalWrite()`
(`sensors.cpp:62-64`), so it reads ON regardless of what the hardware is doing. There is no feedback path.

The reported cause was the **1 kΩ gate resistor (R2) not yet connected** between GPIO15 and the 2N7000
gate (`gen_node_complete.py:182-184`). With the gate floating, Q2 never conducts, R1 (10 kΩ) holds the
IRF4905 gate at 12 V, Vgs = 0, and the P-FET stays off.

Also found: **`gen_node_complete.py:118` documents the wrong IRF4905 pin map** — it says
`1=D 2=G 3=S`, but the real TO-220 IRF4905 is **1=Gate, 2=Drain, 3=Source**. The wiring code on lines
179-186 correctly assumes the real pinout, so the comment is what is wrong — but hand-wiring to it
would swap Gate and Drain and the switch would never work.

**Two additions recommended:**

1. Connect **R2 (1 kΩ): GPIO15 → 2N7000 gate (pin 2)**.
2. Add a **10 kΩ pulldown from the 2N7000 gate to GND**. In deep sleep GPIO15 goes high-impedance, so
   without it the Q2 gate floats and the sensor rail state is undefined — it can partially turn on Q1
   (heat, wasted current) or fail to release the rail, draining the battery. A pulldown guarantees the
   rail is off during boot, reset, and sleep.

Verification order: GPIO15 3.3 V → 2N7000 gate 3.3 V → **IRF4905 gate 12 V falling to ~0 V** → 12 V at J2.

---

## 2c. CONFIRMED ON HARDWARE (2026-09-29): I2C never detected — RESOLVED

**Status: RESOLVED and verified on hardware.** After tying `CS` → 3.3 V, `SDO` → GND, and applying
the firmware fix below, the node reports live values: **29.3 °C / 37.5 % RH / 1009.3 hPa**, drifting
normally between samples. Battery simultaneously reads **12.62 V from 2219 mV ADC** — i.e.
`2219 × 5.70 / 1000 = 12.65 V`, a 0.2 % error, confirming the 2b divider fix as well.

Attribution is shared and cannot be separated: the `CS` → 3.3 V change (which takes the chip out of
SPI mode) is almost certainly what made the device ACK, while the firmware fix removed a latent defect
that would have re-broken the bus on every web-triggered scan and every 3 s retry.

Bench symptom (before the fix): **BME280 never appears on the I2C bus**; reversing SDA and SCL did not help.

### Root cause: the wiring doc is wrong, and it is wrong in the one way that matters

| Source | Assignment |
|---|---|
| **`config.h:44-45` — what the firmware compiles with** | `PIN_I2C_SDA = 1`, `PIN_I2C_SCL = 2` |
| `docs/sensor-wiring.md:37-38` | `SCL → GPIO1`, `SDA → GPIO2` — **swapped** |
| `docs/pin-configuration-guide.md:17-18,298-299` | `SDA = GPIO1`, `SCL = GPIO2` — agrees with the code |

Wiring to the documentation therefore **inverts the bus**, and no device will ACK. The firmware is
correct; `sensor-wiring.md:37-38` must be fixed.

**Correct wiring: SDA → GPIO1, SCL → GPIO2.**

### Second suspect: the switched 3.3 V sensor rail

The BME280 is not on permanent 3.3 V — `VIN` sits on the MOSFET-switched rail (`config.h:69`,
`sensors.cpp:4-5`). `sensorsInit()` does power it on (`sensors.cpp:188`), but:

- pressing **`m`** in the serial console toggles the rail **off** (`main.cpp:149-157`), killing the sensor;
- if the MOSFET stage is not yet built (this was an incremental bench build), the sensor may have no
  supply at all.

### Built-in diagnostics the firmware already provides

| Message | Location | Meaning |
|---|---|---|
| `[I2C] Bus lines are held LOW! (Check 3.3V power). Skipping BME280.` | `sensors.cpp:195` | SDA/SCL held LOW — rail dead or line shorted to GND |
| `-> No I2C devices found!` | `sensors.cpp:116` | Bus idles HIGH but nothing ACKs — swapped lines, wrong address, or dead sensor |
| `-> Found I2C device at 0x76 (BME280 / BMP280)` | `sensors.cpp:92-94` | Device detected |

### SPI-labelled module used in I2C mode (added 2026-09-29)

The bench module exposes **SPI labels** — `3Vo, SCK, SDO, SDI, CS`. The BME280 supports I2C, but
**only when `CSB` is tied HIGH**; otherwise the chip stays in SPI mode and never ACKs an I2C scan.

Correct I2C mapping for this module:

| Module pin | I2C role | Connect to |
|---|---|---|
| `3Vo` | supply | 3.3 V |
| `GND` | ground | GND |
| `SCK` | **SCL** | GPIO2 (`PIN_I2C_SCL`) |
| `SDI` | **SDA** | GPIO1 (`PIN_I2C_SDA`) |
| `CS` | interface select | **3.3 V — required for I2C** |
| `SDO` | address select | GND → `0x76`, 3Vo → `0x77` |

Two common mistakes with this exact board:

1. **`CS` left floating or grounded** → chip remains in SPI mode → no I2C device ever appears.
2. **`SDO` wired to SDA instead of `SDI`** — the "Data Out" label is misleading; in I2C mode the data
   line is `SDI` and `SDO` only selects the address.

Also expect: these SPI-style boards are frequently **BMP280, not BME280** (no humidity). The firmware
handles this and prints `[BMP280] Connected at 0x76 (No Humidity)` (`sensors.cpp:212-219`). Many of
these boards also have **no onboard I2C pull-ups** — add 4.7 kΩ from SDA→3.3 V and SCL→3.3 V if
SDA→3Vo / SCL→3Vo measures open.

### Fix / verification steps

1. Rewire **SDA → GPIO1, SCL → GPIO2** (trust the code, not `sensor-wiring.md`).
2. **Tie `CS` → 3.3 V** and wire the module's **`SDI` → GPIO1, `SCK` → GPIO2, `SDO` → GND**.
3. Power the BME280 **directly from 3.3 V** while bench-testing, bypassing the MOSFET rail.
4. Measure VCC at the module (expect 3.3 V) and the pull-ups SDA→VCC and SCL→VCC (expect 4.7–10 kΩ).
5. Press **`s`** for a manual rescan (`main.cpp:142-145`) and read which of the three messages appears.
6. Fix `docs/sensor-wiring.md:37-38` and add this module's SPI→I2C mapping so the next person does not
   repeat this.

### Code defect found in the I2C path: `sensorsScanI2C()` clobbers its own bus

This is a genuine firmware bug and it can plausibly explain *persistent* detection failure.

```cpp
sensorsInit():
  197:  Wire.begin(PIN_I2C_SDA, PIN_I2C_SCL);   // peripheral now owns GPIO1/GPIO2
  199:  sensorsScanI2C();                        // ...which then does:

sensorsScanI2C():
   75:  pinMode(PIN_I2C_SDA, INPUT_PULLUP);      // demotes the pins to plain GPIO
   76:  pinMode(PIN_I2C_SCL, INPUT_PULLUP);
   84:  Wire.begin(PIN_I2C_SDA, PIN_I2C_SCL);    // re-begin on an already-begun bus
```

`sensorsScanI2C()` reconfigures the I2C pins as plain GPIO **after** the caller has already attached
them to the I2C peripheral, then calls `Wire.begin()` a second time. On Arduino-ESP32 a `begin()` on an
already-initialised `Wire` does not reliably re-establish the pin routing, so the peripheral can be left
talking to pins it no longer drives — nothing ACKs.

Worse, this function is re-entered **every 3 s** from the retry loop (`main.cpp:168-174`) and on **every
"Scan I2C Bus" click** (`config_server.cpp:143`), so a bus that gets clobbered this way never recovers
on its own.

**Recommended fix:** let one place own the I2C pins.

```cpp
static bool i2cStarted = false;

void sensorsScanI2C() {
  Serial.println("[I2C] Scanning bus (SDA=GPIO1, SCL=GPIO2)...");

  if (!i2cStarted) {                       // probe the lines only BEFORE the peripheral owns them
    pinMode(PIN_I2C_SDA, INPUT_PULLUP);
    pinMode(PIN_I2C_SCL, INPUT_PULLUP);
    delay(10);
    if (digitalRead(PIN_I2C_SDA) == LOW || digitalRead(PIN_I2C_SCL) == LOW) {
      Serial.println("  -> WARNING: I2C bus is stuck LOW!");
      return;
    }
    Wire.begin(PIN_I2C_SDA, PIN_I2C_SCL);
    Wire.setTimeOut(50);
    i2cStarted = true;
  }
  /* ...scan loop unchanged... */
}
```

Then delete the duplicate `pinMode` (lines 191-192) and `Wire.begin`/`setTimeOut` (lines 197-198) from
`sensorsInit()`. Never call `pinMode()` on an I2C pin after `Wire.begin()`.

### Related: no I2C mutex between the two cores

The web server task runs on Core 0 (`config_server.cpp:310-318`) and the read loop on Core 1
(`main.cpp:180`); both use `Wire` with no shared lock. A "Scan I2C" click during a BME read corrupts
both transactions. Guard every `Wire` operation with a shared `SemaphoreHandle_t`.

### New observations after the fix (not blockers)

- **Soil moisture saturates at 100 %** and its ADC wanders: raw readings of 943 / 749 / 965 / 720 mV
  across consecutive samples. `sensors.cpp:134` maps anything `<= 1200 mV` to 100 %, so a disconnected
  or floating probe reads a permanent 100 %.
- **The ADC2-under-WiFi hypothesis was NOT confirmed.** The battery on GPIO14 (also ADC2, with WiFi
  active in TEST_MODE) is rock-steady at 2218–2221 mV. The soil swing is therefore more likely a probe
  or input-impedance issue than an ADC2 artefact. The earlier "both analog inputs are on ADC2" concern
  stands as a design smell, not a proven defect.
- **Wind sensors return 0.0 m/s and 0° but report success** (not timeout), so the Modbus slaves answer;
  the zero values need verifying against a known input.

### FIXED: battery state-of-charge was computed for the wrong chemistry

The node UI showed **100 %** on a **4S LiFePO4** pack reading 12.64 V. The gauge was hard-coded for
3S Li-Ion (`webui/src/routes/+page.svelte`: `if (v >= 12.6) return 100`), so a pack at ~3.16 V/cell —
roughly 15 % full — displayed as fully charged. LiFePO4 has a very flat discharge curve, so no linear
map is correct.

Replaced with a per-cell rest-voltage lookup table interpolated across 13 points
(`10.00 V → 0 %` … `13.80 V → 100 %`). 12.64 V now yields **15 %**. The card also shows **V/cell**,
which makes cell imbalance visible. Rebuilt with `pnpm build` and flashed via `pio run -t uploadfs`.

### NEW: `ds18b20_temp` is a duplicate of `bme_temp`, not a second sensor

Confirmed from live telemetry — both fields return the identical value:

```json
{"bme_temp":29.37, ..., "ds18b20_temp":29.37, ...}
```

They are the same number by construction, not by coincidence:

1. `sensorsRead()` overwrites the BME280 temperature with the DS18B20 reading when one is present
   (`sensors.cpp:289`: `data.temperature = dsTemp;`).
2. `updateTelemetryCache()` then assigns `cachedTelem.ds18b20_temp = data.temperature;`
   (`config_server.cpp:47`) — the **already-overwritten** field.
3. The JSON emits both `bme_temp` and `ds18b20_temp` from that one value
   (`config_server.cpp:111,114`).

So the UI's "DS18B20 Probe" readout is meaningless, and the "BME280 / BMP280" label under the main
temperature card is wrong whenever a DS18B20 is connected. The separate accessors
`readBmeTemp()` / `readDS18B20Temp()` (`sensors.cpp:327-359`) exist but are never used by the telemetry
cache. Fix: read both sensors into distinct `SensorData` fields.

---

## 3. High-severity findings

| # | Finding | Evidence | Impact |
|---|---|---|---|
| H1 | **Shipped state is test mode.** `TEST_MODE true`, `SLEEP_INTERVAL_S 5` | `config.h:24,26` | Node never deep-sleeps, never calls `loraInit()`/`loraSend()`. Production path is unreachable and untested by this build. |
| H2 | **The manual rain reset silently does nothing** | `getRainTips()` (`sensors.cpp:319-325`) is a pure getter, yet `sensors.h:45-46` documents it as "(resets counter)"; `main.cpp:147` prints "reset to 0" and the web handler returns `{"success":true}` | The **automatic** reset in `sensorsRead()` (`sensors.cpp:298-299`) does work, so normal cycles are fine — but the `r` serial command and the UI "Reset Rain" button report success while changing nothing. |
| H2b | **`sensorsScanI2C()` clobbers its own I2C bus** | `sensors.cpp:75-76,84` re-run `pinMode(INPUT_PULLUP)` and `Wire.begin()` *after* the caller already attached the peripheral (`:197`) | Pins can be left demoted to plain GPIO with the peripheral still driving nothing ⇒ `No I2C devices found` that **never recovers**, because the same clobber re-runs every 3 s (`main.cpp:168-174`) and on every web scan (`config_server.cpp:143`). Fix in 2c. |
| H3 | **Dashboard weather data is mock by default** | `dashboard/src/lib/server/db.ts:16` defaults to password literally `***`, while compose uses `changeme` (`docker-compose.yml:19`) | Auth fails, `markDBFailed()` latches permanently (`db.ts:29-36`), every page renders `Math.random()` sinusoids (`mock-data.ts:12-30`) **with no "demo data" badge**. A stakeholder demo can present invented data as live. |
| H4 | **Unauthenticated host recon + shell-out** | `api/system/+server.ts:22-54`, `api/docker/+server.ts:16-19` | Any client reaching the dashboard gets hostname, distro, CPU, RAM, disk, and container inventory. `execSync` is a command-execution sink, blocks the event loop up to 5 s, spawns a process per request, and is Linux-only. No injection exists today (no user input interpolated) but it is one string-concat away. |
| H5 | **Unauthenticated MQTT on all interfaces** | `mosquitto.conf:5` `allow_anonymous true`; ports 5432/1883/3000/8081 published on 0.0.0.0 (`docker-compose.yml:21,37,48,63`) | Any LAN host can read/write all telemetry or forge packets. Postgres password `changeme`, Grafana `admin` — shipped defaults. |
| H6 | **Two competing schema definitions** | `server/src/db.ts:21-68` vs `database/migrations/001_initial_schema.sql` | `node_id` is `NOT NULL` only in the SQL; `sensor_daily` exists **only** in the SQL. Whichever runs first wins via `IF NOT EXISTS`. Guaranteed drift. |
| H7 | **`server/src/migrate.ts` does not exist** but `package.json:10` advertises `npm run db:migrate` | — | Documented command fails immediately. README `:43` points at the wrong entry point. |
| H8 | **`sensor_daily` is never populated** | Defined at `001_initial_schema.sql:49-66`; no writer exists anywhere | The "fast Grafana dashboards" table is dead weight. |
| H9 | **RSSI/SNR are computed then discarded** | `lora_gateway.py:133` computes `rssi`; `:136` publishes only the payload | `ingest.ts:44` accepts them but `index.ts:36` never passes them ⇒ columns always NULL, LoRa signal panels permanently empty. |
| H10 | **OTA partitions provisioned, no OTA code** | `partitions_16mb.csv:3-5` (otadata + app0/app1, 3 MB each) | 3 MB reserved and unused; updates require USB. |
| H11 | **Sensor faults are indistinguishable from real zeros** | `sensors.cpp:267` zero-init, no validity flags; `:304,:309` collapse errors to 0 | NaN serializes to JSON `null`, and the UI calls `.toFixed()` unconditionally (`+page.svelte:247,265,280,317,343`) ⇒ render-time TypeError when a sensor drops out. Error branches at `main.cpp:198-206` are dead code. |
| H12 | **No I2C or MOSFET-rail locking** | Core-0 web task `config_server.cpp:310-318` → `sensorsScanI2C` → `Wire.begin()`; Core-1 reads BME280 at `main.cpp:180` | Concurrent bus access; GPIO15 written from two cores with no mutex. |
| H13 | **Default PlatformIO env cannot compile** | `platformio.ini:6-16` `[env:wroom32]` omits ArduinoJson, FastLED, NeoPixel, ModbusMaster — all `#include`d by `src/` | Only `[env:s3]` is viable. |
| H14 | **`pin-configuration-guide.md` contradicts itself** | E22 UART on GPIO4-8 (`:48-57`) vs SX1276 SPI NSS/SCK/MOSI/MISO/RST/DIO0 on GPIO4-9 (`:301-306`) | Stale SPI section never removed. |
| H15 | **Mixed radio families, unverified interop** | Gateway: SX1276/SX1278 SPI via `SX127x` lib (`lora_gateway.py:25`). Firmware: Ebyte E22-900T22D UART transparent mode. | Air parameters (frequency, SF9, BW125, sync word, preamble) exist **only in the E22 module's flash** and are absent from the repo. A replaced module or new node silently fails to link. |
| H16 | **Canonical schematic has never passed ERC** | `konnect-trial/verification.json:4` → `"kicad_erc": "unavailable"` | The only full-board ERC on record is the **archived v2** board, and it **fails: 62 errors, 139 warnings** (`weather-power-pcb-erc.rpt:618`). The 0/0 reports (`minimal_sch-erc.rpt`, `test_direct-erc.rpt`) are for throwaway test schematics whose inputs are not in the repo — they prove nothing about any real board. |
| H17 | **"Zero overlaps" claim is contradicted by its own committed report** | `konnect-trial/README.md:7` vs `overlaps-after.json` → `overlap_count: 3` (U1/#PWR33, U1/#PWR44, U3/#PWR40) | The verification narrative overstates what was proven. |
| H18 | **Canonical node sheet has no battery front end** | `gen_node_complete.py:55-58` — input is barrel jack + PTC + 1N5822 + 100 µF | No BMS, charge controller, UVLO, or low-temperature cutoff on the schematic. BMS/UVLO exist only in prose. |
| H19 | **Hardware is unreproducible here** | `gen_node_complete.py:12,17` require `kicad-sch-api` + Linux paths; absent (`installation.json:33-36`) | Generated artifacts are committed beside their generators, so drift is *visible* in git but not *detectable*. No node `.kicad_pcb` exists at all; only 4 of 22 components have footprints. |

---

## 4. Medium and low findings

- **`wroom32`↔schema drift in the node detail page:** `api/nodes/[id]/+server.ts:23-26` returns Drizzle camelCase keys while the UI reads snake_case (`nodes/[id]/+page.svelte:22-24`) ⇒ "SF" and "Sleep" render blank in real mode.
- **Any malformed id permanently disables the DB:** only `NaN` is rejected (`nodes/[id]/+server.ts:9-12`), so `/api/nodes/1.5` throws → `markDBFailed()` latches mock forever.
- **Mock pagination is broken:** `readings/+server.ts:15-17` hardcodes `limit: 5, total: 500`, so `/readings` shows 5 rows while claiming "1–20 of 500".
- **`idx_daily_node_date` collision:** Drizzle declares it `uniqueIndex` (`dashboard/.../schema.ts:53`) but the SQL creates it **non-unique** with the same name (`001:65-66`); real uniqueness is an unnamed `UNIQUE(node_id, date)`.
- **No graceful shutdown:** `index.ts:45-49` never awaits `client.end()`, never closes the pool, `process.exit(0)` kills in-flight inserts; the async MQTT handler (`:32-38`) has no `.catch`.
- **No retry if Postgres is down at start** (`index.ts:12,54-57`). FK on `node_id` silently drops unseeded nodes; seeds create ids 1–2 (`sample_nodes.sql:3-5`) while dashboards query node 3.
- **`drizzle-orm`/`drizzle-kit` declared in `server/package.json:16-17` but never imported** — contradicting the commit message "SvelteKit dashboard with sidebar layout + Drizzle ORM".
- **No `drizzle.config.ts`** anywhere, so `drizzle-kit` cannot run and the Drizzle schema is decorative.
- **`config.ts:6` fallback DSN omits the password**; `LOG_LEVEL` is read (`:12`) and never used.
- **`adapter-auto` with no adapter-node** (`dashboard/svelte.config.js`) leaves the production build target undefined; `pg`/`drizzle-orm` are runtime imports in `devDependencies` (`package.json:20-24`), breaking `npm ci --omit=dev`.
- **Schema design:** `wind_dir_avg NUMERIC(4,1)` (`001:60`) is a linear mean of a **circular** quantity (350° and 10° average to 180°); no CHECK constraints; no `ON DELETE` on the FK; no TimescaleDB, partitioning, or **retention policy**; `measured_at` exists but is never written; `sample_nodes.sql:6` `ON CONFLICT DO NOTHING` has no conflict target so reruns duplicate rows.
- **Lockfile/tooling split:** `dashboard/` uses npm (`package-lock.json`), `webui/` uses pnpm.
- **Dead links:** `/settings` (`Sidebar.svelte:42`) and four `/charts/*` pages (`charts/+page.svelte:36-55`) 404; `/charts` is not in the sidebar; `favicon.png` referenced (`app.html:6`) but `static/` holds only `robots.txt`.
- **`dashboard/README.md` is untouched `sv create` boilerplate.**
- **`docs/troubleshooting.md` referenced from `docs/deployment.md:214` but does not exist** (the only dead doc reference in the repo).
- **BOM totals do not reconcile:** ₱9,860 (`session-progress.md:35`, no line items) vs ₱4,195 (`power-configuration.md:533`) vs ₱3,380–6,200 (`power-bom-solar-lifepo4.md:150`) vs ₱2,312–3,581 (`power-bom-shopee-complete.md:90`). Arithmetic errors: Phase 1 sums to ₱824 but states ₱825 (`:487-510`); shopee section sums to ₱2,020/₱3,030 but states ₱1,480/₱2,280 (`:85-86`). No BOM exists for the canonical Mini560 + AMS1117 design.
- **`sensor-wiring.md` has SDA/SCL swapped relative to the firmware** — promoted from Low to **High** after it was confirmed as a bench blocker (see 2c). The docs disagree with each other as well as with the code.
- **Doc/banner incoherence:** the 2026-09-29 pass added "canonical" banners without deleting contradicting bodies, so `power-configuration.md` and `sensor-wiring.md` now contradict themselves (banner says Mini560/AMS1117, body still bills 2× Mini560 and headlines LM2596).

- **Repo clutter:** `output/schematic-review/` holds committed "before-final" snapshots (1.4 MB); `hardware/node-pcb/weather-node-complete.svg/` is a directory whose name ends in `.svg`; `hardware/power-supply/power-supply.kicad_sch` is a third, unreferenced variant; `weather-power-v3.kicad_sch` has 24 placements, **0 wires**, and 23 labels — it is a parts list, not a circuit.
- **`firmware/weather-node/data/`** ships 47 `.gz`/`.br` precompressed files that the ESP32 `WebServer` never negotiates — wasted LittleFS space.

---

## 5. What is genuinely good

- **Excellent git hygiene:** 129 files / 3.39 MB tracked, dependencies and build output ignored, no secrets, no BOMs, no mixed line endings.
- **The happy path is genuinely wired:** firmware JSON keys (`packet.cpp:14-22`) → gateway publishes verbatim → ingestor expects the identical key set (`ingest.ts:21-33`) → parameterized INSERT. **No field-name mismatch anywhere**, and the README example matches.
- **No SQL injection:** `ingest.ts:64-86` uses `$1..$13` placeholders; the only concatenated SQL is a hardcoded constant array (`db.ts:59-62`).
- **Correct timezone types:** `TIMESTAMPTZ` for both timestamps (`001:25-26`); `secureJsonData` used for the Grafana password.
- **TypeScript config is sound:** `strict` on, correct NodeNext `.js` import specifiers.
- **Firmware source is complete and honestly commented:** no TODO/FIXME/stub markers in `src/`, every declared function implemented, and `lora.h:27` openly acknowledges transparent mode has no ACK.
- **The konnect trial left real evidence** rather than prose: 0 shorts before and after, 0 orphans, 96/96 bounds resolved.
- **Doc links are 20/21 valid** — unusually disciplined.

---

## 6. Recommended remediation order

**Bench blockers — confirmed on hardware, do these first (2b, 2c):**

0a. **Replace the battery divider's top resistor 4.7 kΩ → 47 kΩ (2b).** GPIO14 has been running at 4.26 V against a 3.3 V limit, with ~1.2 mA injected through the ESD diode. Verify the pin still reads linearly before trusting it.
0b. **Rewire I2C as SDA → GPIO1, SCL → GPIO2 (2c)** — trust the firmware, not `sensor-wiring.md:37-38` — and power the BME280 from a permanent 3.3 V rail while bench-testing. Then fix the doc.

Nothing else can be validated until the sensor bus and the battery sense both work.

1. **Resolve the divider across the repo (C1).** After the hardware fix, set `config.h`, every doc, and the schematic to the single value 5.70 (47k/10k). Nothing about battery health is trustworthy until this is done.
2. **Widen `battery_v` to `NUMERIC(4,2)` (C2)** in `001_initial_schema.sql` and `db.ts`, then make the SQL migration the single source of truth and delete the duplicated DDL. Add 0–100 CHECKs on humidity/soil.
3. **Fix the Grafana datasource (C3):** add `uid: WeatherStation`, pin the Grafana image, align `type`. Confirm by loading the dashboard once.
4. **Turn off test mode and fix the rain reset (H1, H2)** — one-line changes with immediate correctness impact.
5. **Set a real `DATABASE_URL` for the dashboard (H3)** and badge the UI when serving mock data, so a demo can never silently show fabricated readings again.
6. **Add auth (H4, H5)** or at minimum bind the dashboard, MQTT, and Postgres to localhost and remove the shell-out endpoint.
7. **Then** the verification work: build the firmware (`pio` is not installed here), get the canonical schematic through a real ERC, and add a single end-to-end smoke test.

---

## 7. Honest summary

The design thinking is good and the intent is legible: a documented, well-commented, cleanly-versioned
solar weather station. The battery-monitoring path is nonetheless wrong in three independent ways at once
(wrong constant, wrong column type, contradicted by its own docs), the dashboard can present invented
data as real, and the canonical schematic has never been electrically checked while the one ERC report
that does exist fails with 62 errors.

The best single sentence: **this is a prototype whose documentation is better than its verification.**
Fix the divider and the numeric types first — those two changes alone turn a pipeline that discards
every real reading into one that stores them.

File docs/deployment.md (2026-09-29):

# Deployment Guide

## Hardware Checklist

### Per ESP32 Node
- [ ] ESP32-S3 N16R8 dev board
- [ ] E22-900T22D UART LoRa module + 900/915 MHz antenna (SMA)
- [ ] 470µF/10V + 100nF capacitors at E22 VCC/GND
- [ ] BME280 sensor module
- [ ] DS18B20 waterproof probe (optional, secondary temp)
- [ ] Rain gauge (tipping bucket)
- [ ] Anemometer (cup type)
- [ ] Wind vane (potentiometer type)
- [ ] Capacitive soil moisture sensor v1.2
- [ ] Solar panel (5-10W, 18V)
- [ ] 18650 Li-Ion battery (3.7V, 2500-3500mAh)
- [ ] CN3791 solar charge controller
- [ ] HT7333-A 3.3V LDO regulator
- [ ] P-channel MOSFET (for sensor power bus)
- [ ] Resistors: 100kΩ, 220kΩ, 4.7kΩ
- [ ] IP65 weatherproof enclosure
- [ ] Mounting hardware (pole, brackets, cable glands)

### Raspberry Pi Gateway
- [ ] Raspberry Pi (3B+, 4, or 5)
- [ ] MicroSD card (32GB+)
- [ ] LoRa HAT (single SX1276 or SX1302 concentrator)
- [ ] 915 MHz antenna (outdoor, high-gain)
- [ ] Power supply (5V 3A)
- [ ] Ethernet cable (connect to same network as server)

### Server
- [ ] Ryzen 5 + Ubuntu Server
- [ ] Static IP on local network
- [ ] Docker + Docker Compose installed

## Server Setup

### 1. Install Docker

```bash
sudo apt update
sudo apt install -y docker.io docker-compose-v2
sudo usermod -aG docker $USER
# Log out and back in
```

### 2. Clone and Start Services

```bash
cd /home/jimcan/dev/projects
git clone <repo-url> weather-station
cd weather-station

# Start PostgreSQL + Mosquitto + Grafana
docker compose up -d

# Verify
docker compose ps
```

### 3. Install Server Ingestor

```bash
cd server
cp .env.example .env
# Edit .env with real passwords
npm install
npm run build
npm start
```

### 4. Systemd Service (for auto-start)

Create `/etc/systemd/system/weather-ingestor.service`:

```ini
[Unit]
Description=Weather Station Ingestor
After=network.target docker.service
Requires=docker.service

[Service]
Type=simple
User=jimcan
WorkingDirectory=/home/jimcan/dev/projects/weather-station/server
ExecStart=/usr/bin/npm start
Restart=always
RestartSec=10

[Install]
WantedBy=multi-user.target
```

```bash
sudo systemctl daemon-reload
sudo systemctl enable --now weather-ingestor
```

## Raspberry Pi Gateway Setup

### 1. Flash OS

Use Raspberry Pi Imager: Raspberry Pi OS Lite (64-bit).

### 2. Enable SPI

```bash
sudo raspi-config
# Interface Options → SPI → Enable
# Reboot
```

### 3. Deploy Gateway Code

```bash
# From your workstation
rsync -avz gateway/ pi@<rpi-ip>:/home/pi/weather-gateway/

# On RPi
cd /home/pi/weather-gateway
sudo apt install -y python3-pip python3-venv
python3 -m venv venv
source venv/bin/activate
pip install -r requirements.txt
# Edit config.yaml: mqtt.broker to server IP
sudo venv/bin/python lora_gateway.py
```

### 4. Auto-start Gateway

Create `/etc/systemd/system/lora-gateway.service`:

```ini
[Unit]
Description=LoRa MQTT Gateway
After=network.target

[Service]
Type=simple
User=pi
WorkingDirectory=/home/pi/weather-gateway
ExecStart=/home/pi/weather-gateway/venv/bin/python lora_gateway.py
Restart=always
RestartSec=10

[Install]
WantedBy=multi-user.target
```

## ESP32 Node Deployment

### 1. Flash Firmware

```bash
cd firmware/weather-node

# Edit src/config.h:
#   - Set NODE_ID unique per node
#   - Configure sleep interval
#   - Adjust pin assignments if different

# Flash (USB connection)
pio run -t upload

# Monitor serial output
pio run -t monitor
```

### 2. Field Deployment

1. Mount enclosure on pole (2m+ height for wind sensors)
2. Connect antenna, ensure vertical orientation
3. Place solar panel facing south (northern hemisphere)
4. Connect battery last (prevents spark)
5. Verify: check serial monitor for sensor readings + TX confirmations
6. Verify: check PostgreSQL for incoming data

### 3. Add Node to Database

```sql
INSERT INTO sensor_nodes (name, location, latitude, longitude, node_type)
VALUES ('Node 2 — Garden', 'Back garden weather hut', 14.6001, 120.9835, 'C3');
```

## Testing the Pipeline End-to-End

### 1. MQTT Test

```bash
# On server, subscribe to topic
mosquitto_sub -t "weather/raw" -v

# Publish a test packet
mosquitto_pub -t "weather/raw" -m '{"n":1,"t":29.4,"h":78,"p":1013,"b":3.8,"r":2,"ws":1.5,"wd":180,"sm":42}'
```

### 2. Database Check

```bash
psql -h localhost -U weather_ingestor -d weather_station \
  -c "SELECT node_id, temperature, humidity, received_at FROM sensor_readings ORDER BY received_at DESC LIMIT 5;"
```

### 3. Grafana

- Open http://<server-ip>:3000
- Login: admin / admin
- Data source "WeatherStation" should already be configured
- Create a new dashboard → Add panel → Query sensor_readings

## Troubleshooting

See `docs/troubleshooting.md` for common issues.

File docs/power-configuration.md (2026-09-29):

# Weather Node — Power Supply Configuration

> **Archived alternative:** This document records earlier LM2596 and dual-Mini560 studies. The canonical final design is `hardware/node-pcb/weather-node-complete.kicad_sch`: Mini560 12V→5V followed by AMS1117-3.3.

**Board:** ESP32-S3 N16R8 (HW678 v0.0.0)  
**Project:** Weather Station Research  
**Date:** June 29, 2026  
**Revision:** v3.0 — LM2596 + AMS1117 architecture (same as vending machine)  
**Related:** `docs/pin-configuration-guide.md`, `hardware/power-pcb/weather-power-v3.kicad_sch`

---

## Architecture: LM2596-5.0 + AMS1117-3.3 (Same as vending machine)

Single LM2596-5.0 buck converter (12-24V→5V) + AMS1117-3.3 LDO (5V→3.3V) cascaded.
Proven design from vending machine v3.0/v4.0 — parts available on Shopee/Lazada.

```
                         ┌──────────────────────┐
                         │    12-24V DC INPUT      │
                         │  (barrel jack or        │
                         │   screw terminal)       │
                         └──────────┬───────────┘
                                    │
               Phase 1             │           Phase 2
          ┌────────────────────────┼──────────────────────┐
          │                        │                      │
          ▼                        ▼                      ▼
   ┌────────────┐          ┌──────────────┐       ┌──────────────┐
   │ 12V 2A     │          │ Solar 30-50W │       │ Solar + Batt │
   │ Adapter    │          │  + CN3791    │       │  (hybrid)    │
   │ (bench)    │          │  + 3S Li-Ion │       │              │
   └────────────┘          └──────────────┘       └──────────────┘
          │                        │                      │
          └────────────────────────┼──────────────────────┘
                                   │
                        ┌──────────┴──────────┐
                        │    INPUT PROTECTION   │
                        │  PTC 5A + SS34 +      │
                        │  100µF/35V + 100nF    │
                        └──────────┬──────────┘
                                   │
           ┌───────────────────────┼───────────────────────┐
           │                       │                       │
           ▼                       ▼                       ▼
   ┌───────────────┐     ┌───────────────┐      ┌──────────────────┐
   │ LM2596-5.0    │     │ AMS1117-3.3   │      │ MOSFET Switch    │
   │ 12V → 5V      │     │ 5V → 3.3V     │      │ (GPIO15 → Gate)  │
   │ + SS34 + 68µH │     │ + 100nF+10µF │      │ 12V → 12V_SW     │
   │ + 220µF+10µF│     │               │      │                  │
   └───────┬───────┘     └───────┬───────┘      └────────┬─────────┘
           │                     │                        │
           ▼                     ▼                        ▼
   ┌───────────────┐     ┌───────────────┐      ┌──────────────────┐
   │ 5V BUS         │     │ 3.3V BUS       │      │ 12V_SWITCHED     │
   │                │     │                │      │                  │
   │ MAX485         │     │ ESP32-S3       │      │ RS485 Anemometer │
   │                │     │ LoRa SX1262    │      │ RS485 Wind Vane  │
   └────────────────┘     │ BME280         │      └──────────────────┘
                          │ LTR390         │
                          │ DS18B20        │
                          │ Rain (passive) │
                          │ Soil Moisture  │
                          │ RGB LED(WS2812)│
                          └───────────────┘

           ┌───────────────┐
           │ BATTERY MON.   │
           │ 330k + 100k    │
           │ divider (4.30) │
           │ → BAT_ADC      │
           └───────────────┘
```

> **Why LM2596 + AMS1117 instead of dual Mini560?** Same parts as vending machine — Jim already knows the design, parts are on Shopee/Lazada, no tuning needed (fixed-voltage versions). LM2596 is TO-220 through-hole, easy to solder. Quiescent current (~10mA) is negligible with a 30W solar panel.

---

## Architecture: Two Parallel Mini560 Bucks from 12V Rail

Two independent Mini560 buck converters run in parallel from the 12V rail. No cascading — each buck converts 12V directly to its target voltage.

```
                         ┌──────────────────────┐
                         │    12V DC INPUT        │
                         │  (barrel jack or        │
                         │   screw terminal)       │
                         └──────────┬───────────┘
                                    │
               Phase 1             │           Phase 2
          ┌────────────────────────┼──────────────────────┐
          │                        │                      │
          ▼                        ▼                      ▼
   ┌────────────┐          ┌──────────────┐       ┌──────────────┐
   │ 12V 2A     │          │ Solar 30-50W │       │ Solar + Batt │
   │ Adapter    │          │  + CN3791    │       │  (hybrid)    │
   │ (bench)    │          │  + 3S Li-Ion │       │              │
   └────────────┘          └──────────────┘       └──────────────┘
          │                        │                      │
          └────────────────────────┼──────────────────────┘
                                   │
                        ┌──────────┴──────────┐
                        │    12V COMMON RAIL   │
                        │  (reverse-polarity   │
                        │   Schottky + 100µF)  │
                        └──────────┬──────────┘
                                   │
           ┌───────────────────────┼───────────────────────┐
           │                       │                       │
           ▼                       ▼                       ▼
   ┌───────────────┐     ┌───────────────┐      ┌──────────────────┐
   │ Buck #1       │     │ Buck #2       │      │ MOSFET Switch    │
   │ 12V → 5V      │     │ 12V → 3.3V    │      │ (GPIO15 → Gate)  │
   │ Mini560 (5V)  │     │ Mini560 (3.3V)│      │ 12V → 12V_SW     │
   └───────┬───────┘     └───────┬───────┘      └────────┬─────────┘
           │                     │                        │
           ▼                     ▼                        ▼
   ┌───────────────┐     ┌───────────────┐      ┌──────────────────┐
   │ 5V BUS         │     │ 3.3V BUS       │      │ 12V_SWITCHED     │
   │                │     │                │      │ (sensor bus)     │
   │ MAX485         │     │ ESP32-S3       │      │                  │
   │                │     │ LoRa SX1262    │      │ RS485 Anemometer │
   └────────────────┘     │ BME280         │      │ RS485 Wind Vane  │
                          │ LTR390         │      └──────────────────┘
                          │ DS18B20        │
                          │ Rain (passive) │
                          │ Soil Moisture  │
                          │ RGB LED(WS2812)│
                          └───────────────┘
```

> **Why parallel bucks instead of buck→LDO?** Two Mini560 modules are simpler to source (no separate LDO IC + caps to solder), each is jumper-set to a fixed voltage, and the quiescent current of ~200µA total (2 × 100µA) is trivial on a solar-charged 12V battery. The 12V→3.3V direct conversion also runs cooler at ESP32 loads (~30mA) than cascading through 5V first.

---

## Buck Converter #1: 12V → 5V (Mini560, fixed 5V output)

### Module Settings

| Parameter | Value |
|---|---|
| Module | Mini560 DC-DC Buck (MP1584-based) |
| Input | 7–28V DC |
| Output | **5.0V fixed** (solder jumper selected) |
| Max current | 3A continuous |
| Efficiency | ~88–92% at 50–200mA |
| Quiescent (Iq) | ~100µA |
| Size | ~17×11mm |

### Jumper Configuration

The Mini560 has solder pads on the back. Bridge the **5V** pads to set the output. No potentiometer — no tuning needed.

```
Mini560 back side:
┌──────────────┐
│ ○  ○  ○  ○  │  3.3V  5V  9V  12V  pads
│              │
│  ══          │  Bridge the 5V pads with solder blob
│              │
└──────────────┘
```

### Capacitors (Add for Stability)

```
12V IN ──┬── 100µF/25V electrolytic ── GND
         │
         └── Mini560 Vin+
               Mini560 Vin- ── GND
               Mini560 Vout+ ──┬── 100µF/16V electrolytic ── GND
                              │
                              └── 3.3V BUS → DIYMORE RS485 VCC
```

---

## Buck Converter #2: 12V → 3.3V (Mini560, fixed 3.3V output)

### Module Settings

| Parameter | Value |
|---|---|
| Module | Mini560 DC-DC Buck (MP1584-based) |
| Input | 7–28V DC |
| Output | **3.3V fixed** (solder jumper selected) |
| Max current | 3A continuous |
| Efficiency | ~85–90% at 30–100mA |
| Quiescent (Iq) | ~100µA |
| Size | ~17×11mm |

### Jumper Configuration

Bridge the **3.3V** pads:

```
Mini560 back side:
┌──────────────┐
│ ○  ○  ○  ○  │  3.3V  5V  9V  12V  pads
│              │
│ ══           │  Bridge the 3.3V pads with solder blob
│              │
└──────────────┘
```

### Capacitors

```
12V IN ──┬── 100µF/25V electrolytic ── GND
         │
         └── Mini560 Vin+
               Mini560 Vin- ── GND
               Mini560 Vout+ ──┬── 100µF/16V electrolytic ── GND
                              │
                              └── 3.3V BUS → ESP32 + LoRa + BME280 + LTR390 + DS18B20 + Soil
```

> ⚠️ Double-check the 3.3V jumper before power-up. A misconfigured module set to 12V will kill the ESP32 instantly. Measure Vout with multimeter before connecting anything.

---

## MOSFET Switch: GPIO15 → 12V Sensor Bus

*(Unchanged from v1.0)*

The ESP32 GPIO15 outputs 3.3V, but we need to switch a 12V rail. A two-transistor level shifter does this:

```
12V ────────┬─────────────── IRF9540 Source (P-channel MOSFET)
            │
            └──[10kΩ]──┬── IRF9540 Gate
                       │
                       ├── 2N7000 Drain (N-channel MOSFET)
                       │
                       │   2N7000 Source ── GND
                       │
GPIO15 ────[1kΩ]───────┼── 2N7000 Gate
                       │
                      GND

IRF9540 Drain ──► 12V_SWITCHED (wind sensors)
```

### How It Works

| GPIO15 | 2N7000 | IRF9540 Gate | IRF9540 | 12V_SW |
|---|---|---|---|---|
| LOW (0V) | OFF | Pulled to 12V via 10kΩ | OFF | 0V |
| HIGH (3.3V) | ON | ~0V (pulled to GND) | ON | 12V |

### Parts

| Part | Package | Price |
|---|---|---|
| IRF9540 | TO-220 | ₱30 |
| 2N7000 | TO-92 | ₱10 |
| 10kΩ resistor | 1/4W | ₱1 |
| 1kΩ resistor | 1/4W | ₱1 |

---

## Perf Board Layout (7×9 cm)

```
┌──────────────────────────────────────────────────────────┐
│                  POWER PERF BOARD                         │
│                   (7×9 cm, top view)                      │
│                                                           │
│  ┌─────────────┐                                          │
│  │ 12V INPUT    │    ┌────────────────┐  ┌────────────┐  │
│  │ Barrel Jack  │    │ Mini560 #1     │  │ Mini560 #2 │  │
│  │              │    │ 12V → 5V       │  │ 12V→3.3V   │  │
│  │ (+) ────────┬────│─ Vin+          │  │            │  │
│  │ (-) ────┐   │    │  Vin- ───┐     │  │            │  │
│  └─────────│───│────│─ Vout+    │     │  │            │  │
│            │   │    │  Vout- ───│──┐  │  │            │  │
│            │   │    └───────────│──│──│──│─ Vin+      │  │
│            │   │               │  │  │  │  Vin- ───┐ │  │
│  12V BUS   ▼   ▼               │  │  │  │  Vout+   │ │  │
│  ───────────────────           │  │  │  │  Vout- ──│─│──│── 3.3V OUT
│  │  +  │  │  -  │              │  │  │  └──────────│─│──│── GND
│  │     │  │     │              │  │  │             │ │  │
│  │ 12V │  │ GND │              │  │  │             │ │  │
│  │ BUS │  │ BUS │              │  │  │             │ │  │
│  └──┬──┘  └──┬──┘              │  │  │             │ │  │
│     │        │                 │  │  │             │ │  │
│     │        └────── GND ──────┴──┴──┴─────────────┘ │  │
│     │                                                  │  │
│     ├──► Wind Sensors (12V) via MOSFET SW              │  │
│     ├──► Mini560 #1 Vin+                                │  │
│     └──► Mini560 #2 Vin+                                │  │
│                                                         │  │
│  ┌───────────────────────────────────────────────┐     │  │
│  │            OUTPUT TERMINALS                     │     │  │
│  │                                                │     │  │
│  │  [12V_SW] [GND]  [5V] [GND]  [3.3V] [GND]    │     │  │
│  │                           [GPIO15] [BAT_ADC]  │     │  │
│  └───────────────────────────────────────────────┘     │  │
│                                                         │  │
│  ┌────────────────────────┐                             │  │
│  │ MOSFET SW              │                             │  │
│  │ IRF9540 + 2N7000       │                             │  │
│  │ 10kΩ + 1kΩ             │                             │  │
│  └────────────────────────┘                             │  │
└──────────────────────────────────────────────────────────┘
```

### Perf Board Wiring Checklist

- [ ] Barrel jack soldered at edge (12V IN)
- [ ] Schottky diode (1N5819) in series with 12V+ for reverse-polarity protection
- [ ] 100µF/25V electrolytic across 12V input (polarity: stripe = negative)
- [ ] Thick power bus traces for 12V and GND (use solder bridges or solid wire)
- [ ] Mini560 #1 (5V) mounted — **verify jumper is on 5V pads**
- [ ] 100µF/16V electrolytic across Mini560 #1 output
- [ ] Mini560 #2 (3.3V) mounted — **verify jumper is on 3.3V pads**
- [ ] 100µF/16V electrolytic across Mini560 #2 output
- [ ] MOSFET level-shifter circuit in one corner
- [ ] Screw terminal block for each output: 12V_SW, 5V, 3.3V
- [ ] GPIO15 header pin for MOSFET gate signal
- [ ] BAT_ADC header pin for battery voltage divider tap
- [ ] All GNDs tied to common ground bus
- [ ] Heat shrink tubing on exposed 12V connections

### Wire Gauge Guide

| Connection | Recommended Wire |
|---|---|
| 12V input / bus | 22–20 AWG solid core |
| 3.3V / 5V signal | 24–26 AWG |
| Sensor power runs | 24 AWG |
| High-current paths (>500mA) | 20 AWG |

---

## Voltage Divider: 12V Battery Monitoring

The divider is sized for a 12V battery (3S Li-Ion: 9.0V–12.6V, or 12V SLA: 10.5V–13.8V).

```
Battery (+) 12.6V max
    │
  [330kΩ]     ← R1 (top resistor)
    │
    ├──── GPIO14 (ADC2)   ← Max = 12.6 × 100/(100+330) = 2.93V (safe)
    │
  [100kΩ]     ← R2 (bottom resistor)
    │
   GND
```

| Parameter | Value |
|---|---|
| R1 (top) | 330kΩ |
| R2 (bottom) | 100kΩ |
| Divider ratio | 0.2326 |
| Max ADC voltage | 2.93V (at 12.6V battery) |
| Min ADC voltage | 2.09V (at 9.0V battery) |

**Formula:** `V_battery = V_adc × (330 + 100) / 100 = V_adc × 4.30`

### Firmware Config

In `config.h`:

```c
#define BAT_R1  330.0   // kΩ (top resistor)
#define BAT_R2  100.0   // kΩ (bottom resistor)
```

---

> **2026-09-29 update:** The older MAX485 drawings/current estimates above are historical. The current U4 module uses 3.3V; see the wiring below. Module current and rail budget require its datasheet.

## RS485 Wind Sensor Power

### Wind Sensor Supply (12V Direct)

The RS485 anemometer and wind vane need 12-24V DC. They connect to the **12V_SWITCHED** output (controlled by GPIO15 via MOSFET).

```
12V_SW ──┬── Anemometer V+ (red/brown)
         │
         └── Wind Vane V+ (red/brown)

GND ─────┬── Anemometer GND (black)
         │
         └── Wind Vane GND (black)
```

### DIYMORE isolated automatic-direction RS485 module

The selected module has TTL pins **VCC, TXD, RXD, GND** (top to bottom in the supplied image), and **A+, B−, earth** screw terminals. U4 uses logical terminal numbers, not a verified PCB footprint.

| Module terminal | Connection |
|---|---|
| VCC | 3.3V BUS from AMS1117-3.3 |
| TXD | GPIO18 / UART1 RX — provisional: assumes module output |
| RXD | GPIO17 / UART1 TX — provisional: assumes module input |
| GND | ESP32/common GND (TTL side) |
| A+ | Both wind sensors' A bus |
| B− | Both wind sensors' B bus |
| Earth | Reserved/unconnected in this design; separate from TTL GND |

**Verify UART directions before wiring:** the product image labels TXD/RXD but does not specify input/output. The schematic provisionally uses crossed UART wiring. If the board labels refer to the host UART instead, connect GPIO17 TX to module TXD input and GPIO18 RX to module RXD output. Confirm with the seller's pin-direction diagram or datasheet; do not infer direction solely from the names.

- Supply the TTL side at **3.3V**, consistent with the pictured 3.3V/5V marking. Confirm its output signal is 3.3V-compatible before connecting ESP32 RX.
- Automatic direction control: **no DE/RE wire; GPIO16 is unused**. R8/R9 from the old 5V receive divider are removed. C7 remains 100nF across TTL VCC/GND.
- R10 is **120Ω, DNP by default**. Fit only when this is a bus endpoint and the module does not already provide enabled termination; avoid duplicate parallel termination.
- Do not bridge the pictured earth/protection terminal to TTL GND. Its grounding arrangement needs the module documentation. Sensor supply return remains the existing common GND; this design does not claim complete system galvanic isolation.
- Wind sensors retain **12V_SW** power via GPIO15/MOSFET. Never feed their 12V into module VCC.
---

## Sensor Power Table

| Sensor | Supply Voltage | Rail | Switched? | Notes |
|---|---|---|---|---|
| ESP32-S3 | 3.3V | 3.3V BUS | No | Always powered or deep sleep |
| E22-900T22D | 5V | 5V BUS | No | Mode 3 sleep via M0=HIGH, M1=HIGH |
| BME280 | 3.3V | 3.3V BUS | No | ~0.5mA active, 0.1µA sleep |
| LTR390 | 3.3V | 3.3V BUS | No | ~0.3mA active |
| DS18B20 | 3.3V | 3.3V BUS | No | ~1mA active |
| Rain Gauge | — | — | No | Passive reed switch |
| Soil Moisture | 3.3V | 3.3V BUS | No | Read via ADC |
| RGB LED (WS2812) | 3.3V | 3.3V BUS | No | Built into dev board |
| DIYMORE auto RS485 | 3.3V | 3.3V BUS | No | Confirm module current from datasheet |
| RS485 Anemometer | 12V | 12V_SW | **Yes (GPIO15)** | ~20-50mA active |
| RS485 Wind Vane | 12V | 12V_SW | **Yes (GPIO15)** | ~20-50mA active |

> Low-voltage sensors (3.3V bus) stay always-on and manage their own sleep states. The MOSFET switch controls only the 12V wind sensor rail.

---

## Current Budget (12V System)

### Sleep State

| Component | Current @ 12V | Notes |
|---|---|---|
| Mini560 #1 (5V) quiescent | ~100µA | Always-on |
| Mini560 #2 (3.3V) quiescent | ~100µA | Always-on |
| ESP32 deep sleep | ~10µA @ 3.3V ≈ 3µA @ 12V | After buck |
| E22 mode 3 | Verify with ammeter | Module/batch dependent; M0=M1=HIGH |
| BME280 sleep | ~0.1µA @ 3.3V | |
| MAX485 idle | ~1mA @ 5V ≈ 0.4mA @ 12V | After buck |
| Wind sensors | 0mA | MOSFET OFF (GPIO15 LOW) |
| **Total Sleep** | **~0.6mA @ 12V** | |

### Active State (~2 seconds per cycle)

| Component | Current @ 12V |
|---|---|
| ESP32 (80MHz, WiFi off) | ~27mA |
| LoRa TX burst (17dBm) | ~40mA |
| Sensors (BME280+LTR390+DS18B20+Soil) | ~5mA |
| MAX485 active | ~0.5mA |
| Wind sensors (12V direct) | 50mA |
| Buck conversion losses (~10%) | ~12mA |
| **Total Active** | **~135mA @ 12V** |

### Daily Energy (5-min sleep interval, 288 cycles/day)

| Phase | Calculation | Energy |
|---|---|---|
| Sleep: 0.6mA × 23.92h | | 14.4 mAh |
| Active: 135mA × (288 × 2s / 3600) | = 135mA × 0.16h | 21.6 mAh |
| **Daily Total** | | **36.0 mAh @ 12V** |
| **Daily Wh** | 36.0mAh × 12V | **0.43 Wh** |

### Battery Runtime

| Battery | Capacity @ 12V | Runtime (no solar) |
|---|---|---|
| 3S 18650 3000mAh | 3000mAh | ~83 days |
| 3S 18650 3500mAh | 3500mAh | ~97 days |
| 12V 7Ah SLA | 3500mAh usable (50% DoD) | ~97 days |
| 12V 9Ah SLA | 4500mAh usable | ~125 days |

> With a 30W solar panel in Philippines sun (~4.5 peak sun hours = 135Wh/day), the system is net-positive by a huge margin. The 0.43Wh/day draw is less than 0.5% of daily solar harvest.

---

## Complete Bill of Materials (BOM)

### Phase 1 — Bench Testing (paliton karon)

| # | Item | Spec | Qty | Unit Price | Total |
|---|---|---|-----|---|---|
| 1 | 12V DC Adapter | 12V 2A, 5.5×2.1mm barrel plug | 1 | ₱200 | ₱200 |
| 2 | DC Barrel Jack | 5.5×2.1mm female, panel mount, screw terminals | 1 | ₱40 | ₱40 |
| 3 | Schottky Diode | 1N5819, 1A 40V (reverse-polarity protection) | 1 | ₱5 | ₱5 |
| 4 | **Mini560 Buck Module** | 5V fixed output (jumper-selectable) | 1 | ₱85 | ₱85 |
| 5 | **Mini560 Buck Module** | 3.3V fixed output (jumper-selectable) | 1 | ₱85 | ₱85 |
| 6 | IRF9540 | P-channel MOSFET, TO-220 | 1 | ₱30 | ₱30 |
| 7 | 2N7000 | N-channel MOSFET, TO-92 | 1 | ₱12 | ₱12 |
| 8 | Resistor 10kΩ | 1/4W carbon film | 2 | ₱1 | ₱2 |
| 9 | Resistor 1kΩ | 1/4W carbon film | 1 | ₱1 | ₱1 |
| 10 | Resistor 330kΩ | 1/4W carbon film (battery divider R1) | 1 | ₱1 | ₱1 |
| 11 | Resistor 100kΩ | 1/4W carbon film (battery divider R2) | 1 | ₱1 | ₱1 |
| 12 | Resistor 4.7kΩ | 1/4W carbon film (DS18B20 pull-up) | 1 | ₱1 | ₱1 |
| 13 | Capacitor 100µF/25V | Electrolytic (input bulk) | 1 | ₱10 | ₱10 |
| 14 | Capacitor 100µF/16V | Electrolytic (output bulk, one per buck) | 2 | ₱8 | ₱16 |
| 15 | **Perf Board** | 7×9 cm, single-sided, 2.54mm pitch | 1 | ₱55 | ₱55 |
| 16 | Screw Terminal Block | 2-pin, 5mm pitch | 4 | ₱15 | ₱60 |
| 17 | Pin Headers | Male 1×40, 2.54mm | 1 strip | ₱20 | ₱20 |
| 18 | Jumper Wires | Male-to-male, 20cm, 40pcs | 1 set | ₱60 | ₱60 |
| 19 | Solid Core Wire | 22 AWG, red+black, 2m each | 1 set | ₱50 | ₱50 |
| 20 | Heat Shrink Tubing | Assorted, 2mm–6mm | 1 set | ₱40 | ₱40 |
| 21 | Dupont Connectors | Male + female crimp pins + housings | 1 set | ₱50 | ₱50 |
| | | | | **Phase 1 Total** | **₱825** |

### Phase 2 — Solar + Battery (paliton unya)

| # | Item | Spec | Qty | Unit Price | Total |
|---|---|---|-----|---|---|
| 22 | Solar Panel | 30–50W, 18Vmp, monocrystalline | 1 | ₱1,200 | ₱1,200 |
| 23 | Li-Ion Cells | 18650, 3500mAh, protected (Samsung/Panasonic) | 3 | ₱250 | ₱750 |
| 24 | 3S BMS Board | 12.6V, 25A, balance charging | 1 | ₱180 | ₱180 |
| 25 | CN3791 Module | Solar charge controller, 1S–4S configurable | 1 | ₱350 | ₱350 |
| 26 | IP65 Enclosure | ABS waterproof box, 200×150×100mm | 1 | ₱450 | ₱450 |
| 27 | Cable Glands | PG7 or PG9, waterproof | 4 | ₱25 | ₱100 |
| 28 | Mounting Bracket | L-bracket + U-bolts for solar panel | 1 set | ₱200 | ₱200 |
| 29 | XT60 Connectors | Male+female pair (battery disconnect) | 2 pairs | ₱40 | ₱80 |
| 30 | Fuse Holder + Fuse | 2A, inline blade type | 1 | ₱60 | ₱60 |
| | | | | **Phase 2 Total** | **₱3,370** |

### Grand Total

| Phase | Total |
|---|---|
| Phase 1 — Bench Testing | ₱825 |
| Phase 2 — Solar + Battery | ₱3,370 |
| **GRAND TOTAL (complete single-node power)** | **₱4,195** |

> **Note:** Prices are estimated from Shopee/Lazada Philippines as of June 2026. ±20% depending on seller and shipping. The BOM is ₱55 more than v1.0 (₱85 extra Mini560 replaces ₱15 HT7333 + 2×₱5 electrolytics — simpler, fewer parts to solder).

---

## Shopee/Lazada Search Terms

| Item | Search Term |
|---|---|
| Mini560 5V | "mini560 buck 5v module fixed" |
| Mini560 3.3V | "mini560 buck 3.3v module fixed" |
| 1N5819 | "1n5819 schottky diode" |
| IRF9540 | "irf9540 p channel mosfet" |
| 2N7000 | "2n7000 mosfet to-92" |
| Perf board | "perf board 7x9 single sided" |
| Barrel jack | "dc barrel jack panel mount 5.5 2.1 screw terminal" |
| Solar panel | "solar panel 30w 18v monocrystalline" |
| 18650 cells | "18650 3500mah protected samsung panasonic genuine" |
| 3S BMS | "3s bms 12.6v 25a balance" |
| CN3791 | "cn3791 solar charge controller module" |
| IP65 enclosure | "ip65 abs junction box waterproof 200x150x100" |
| Cable gland | "pg7 cable gland waterproof" |
| XT60 | "xt60 connector pair" |

---
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

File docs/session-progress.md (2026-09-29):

# Weather Station — Session Progress Log

> **Canonical hardware decision (2026-09-03):** The final weather-node design is `hardware/node-pcb/weather-node-complete.kicad_sch`, using one Mini560 for 12V→5V and an AMS1117-3.3 for 5V→3.3V. LM2596 and dual-Mini560 entries below are retained as historical alternatives.

## 2026-06-29 to 2026-07-08: Power Supply Design & Shopping

### ✅ Completed

1. **Power Supply Architecture v3.0 — LM2596 + AMS1117**
   - Same design as vending machine for parts availability
   - Schematic generated at `hardware/power-pcb/weather-power-v3.kicad_sch`
   - 24 components, KiCad 9.0 format, net labels as wiring reference
   - See `docs/power-configuration.md` for full architecture
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

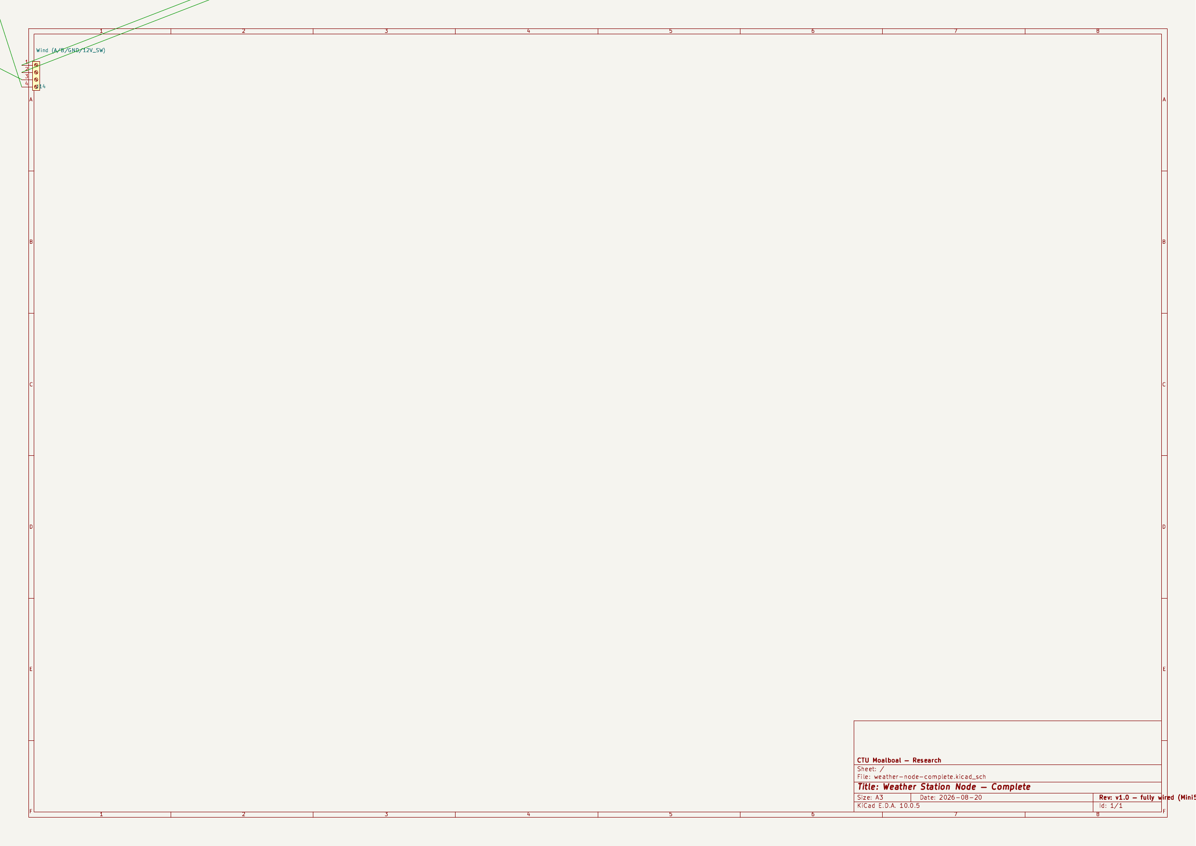
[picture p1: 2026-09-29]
hardware/node-pcb/weather-node-preview-1.png

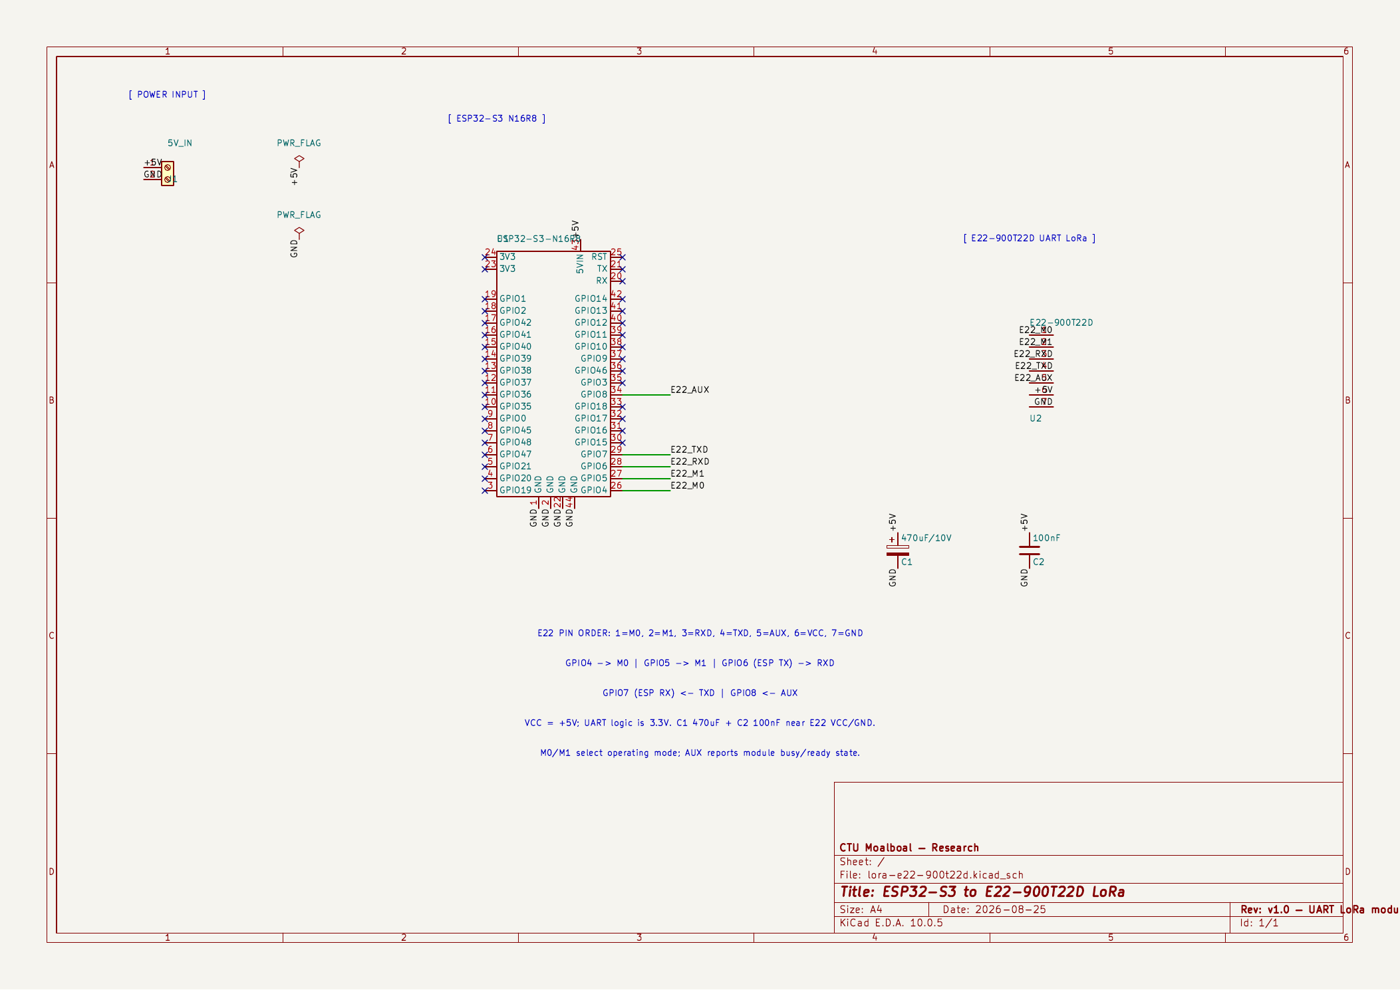
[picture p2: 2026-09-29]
hardware/lora-e22/lora-e22-preview.png

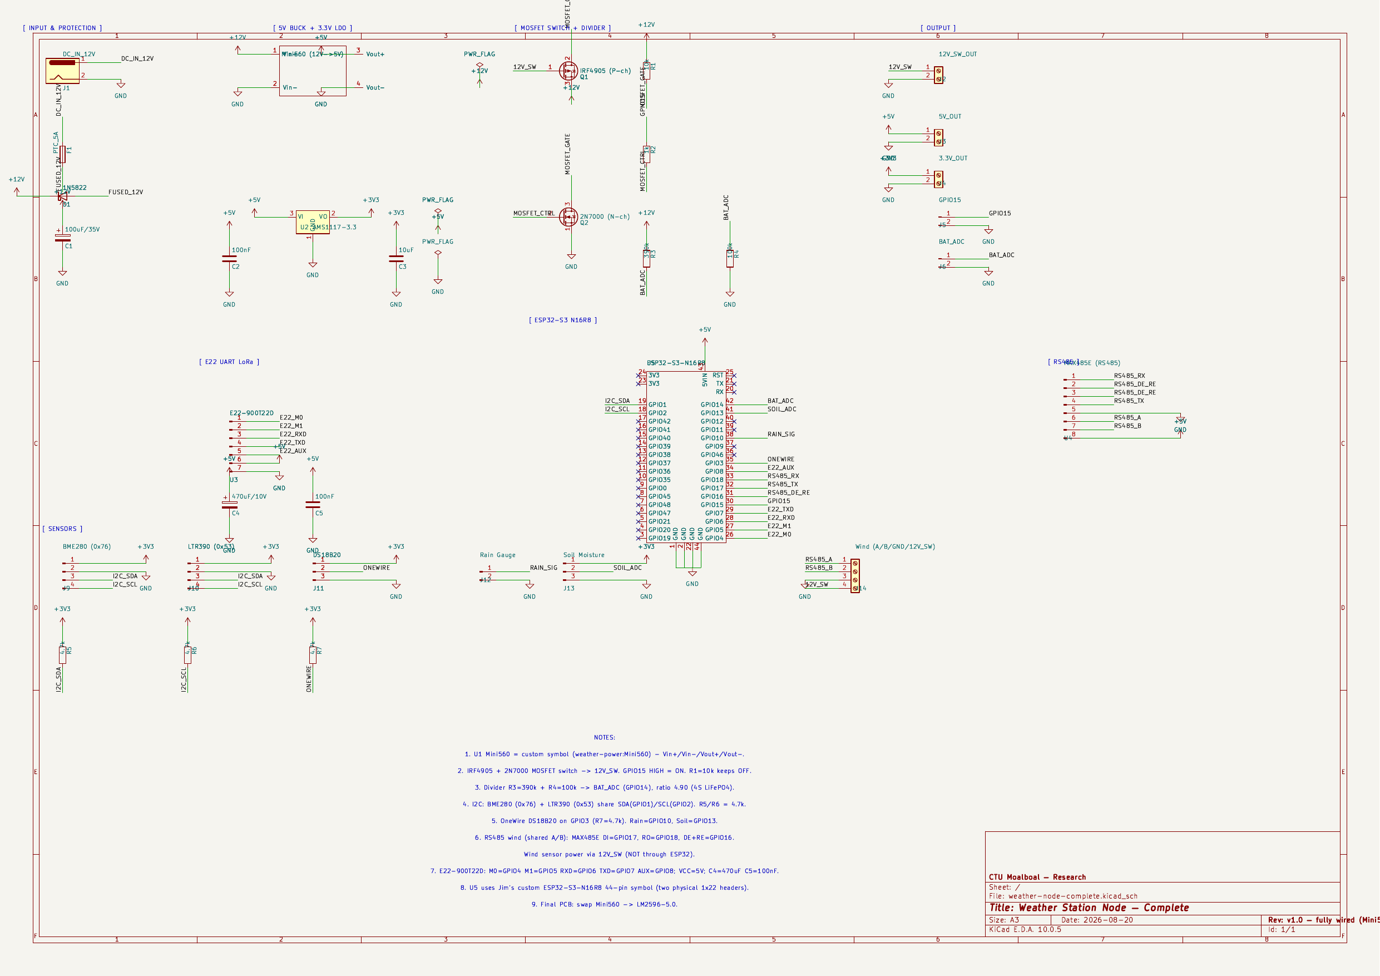
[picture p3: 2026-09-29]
hardware/node-pcb/weather-node-preview.png

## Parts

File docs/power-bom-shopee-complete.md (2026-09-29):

# Weather Station — Complete BOM with Shopee PH Links

**Date:** June 29, 2026  
**Architecture:** Solar 30W → PWM LiFePO4 Controller → 4S LiFePO4 12.8V 6Ah → Power PCB

---

## ☀️ SECTION 1: SOLAR + BATTERY (₱2,300–3,000)

| # | Item | Spec | Qty | Price (₱) | Shopee Search Term |
|---|---|---|-----|---|---|
| 1 | Solar Panel | 30W 18V monocrystalline | 1 | 800–1,200 | `30W solar panel 18V monocrystalline` |
| 2 | Solar Charge Controller | PWM 10A, LiFePO4 4S compatible | 1 | 300–500 | `PWM solar charge controller LiFePO4 12V` |
| 3 | LiFePO4 Cells | 32700 3.2V 6000mAh | 4 | 180–250 | `32700 LiFePO4 6000mAh` |
| 4 | 4S BMS | LiFePO4 12.8V 30A with balance wires | 1 | 120–180 | `4S LiFePO4 BMS 12.8V balance` |
| 5 | Battery Holder | 4S 32700 plastic holder or DIY nickel strip | 1 | 80–150 | `32700 battery holder 4S` |

**📝 Note:** Pwede sad **XY-L30A charge controller** (₱250–400) instead of PWM — adjustable cutoff voltage ra, dili solar-optimized pero mudagan ra.

---

## ⚡ SECTION 2: POWER PCB COMPONENTS (₱700–900)

| # | Ref | Value | Qty | Price (₱) | Shopee Search Term |
|---|-----|---|-----|---|---|
| 6 | U1 | **LM2596-5.0 fixed** TO-220-5 | 1 | 55–85 | `LM2596-5.0 fixed TO-220` |
| 7 | U2 | AMS1117-3.3 SOT-223 | 1 | 10–20 | `AMS1117-3.3 SOT-223` |
| 8 | Q1 | IRF9540N P-ch MOSFET TO-220 | 1 | 25–45 | `IRF9540N MOSFET TO-220` |
| 9 | Q2 | 2N7000 N-ch MOSFET TO-92 | 1 | 8–15 | `2N7000 MOSFET TO-92` |
| 10 | D1, D2 | SS34 Schottky 3A SMD DO-214AB | 2 | 5–8 | `SS34 SMD schottky diode` |
| 11 | L1 | 68µH 3A toroidal inductor | 1 | 25–50 | `68uH inductor 3A` |
| 12 | C1 | 100µF 35V electrolytic | 1 | 8–15 | `100uF 35V electrolytic` |
| 13 | C3 | 220µF 16V electrolytic | 1 | 8–15 | `220uF 16V electrolytic` |
| 14 | C2, C5 | 100nF ceramic (0.1µF) | 2 | 2–5 | `100nF ceramic capacitor` |
| 15 | C4, C6 | 10µF 16V electrolytic | 2 | 3–8 | `10uF 16V electrolytic` |
| 16 | **R3** | **390kΩ** 1/4W (LiFePO4 divider) | 1 | 2–5 | `390k ohm 1/4W resistor` |
| 17 | R4 | 100kΩ 1/4W | 1 | 2–5 | `100k ohm 1/4W resistor` |
| 18 | R1 | 10kΩ 1/4W | 1 | 2–5 | `10k ohm 1/4W resistor` |
| 19 | R2 | 1kΩ 1/4W | 1 | 2–5 | `1k ohm 1/4W resistor` |
| 20 | F1 | PTC resettable fuse 5A | 1 | 10–20 | `PTC resettable fuse 5A` |

---

## 🔌 SECTION 3: CONNECTORS (₱150–200)

| # | Ref | Value | Qty | Price (₱) | Shopee Search Term |
|---|-----|---|-----|---|---|
| 21 | J1 | DC Barrel Jack PCB mount 5.5×2.1mm | 1 | 10–20 | `DC barrel jack PCB 5.5x2.1mm` |
| 22 | J2–J4 | Screw terminal 2P 5.08mm pitch | 3 | 8–10 | `screw terminal 2 pin 5.08mm` |
| 23 | J5–J6 | Pin header male 2P 2.54mm | 2 | 3–5 | `pin header 2 pin 2.54mm` |
| 24 | Battery Conn. | XT60 male+female pair | 1 | 35–55 | `XT60 connector pair` |
| 25 | Dupont Wires | Male-to-female 20cm 10pcs | 1 set | 25–40 | `dupont wire male female 20cm` |

---

## 🔧 SECTION 4: WIRING + PROTECTION (₱220–340)

| # | Item | Spec | Qty | Price (₱) | Shopee Search Term |
|---|---|---|-----|---|---|
| 26 | Silicone Wire 14AWG | Red + Black, 1m each | 2m | 50–80 | `14AWG silicone wire red black` |
| 27 | Inline Fuse Holder | ATC/ATO waterproof | 1 | 35–55 | `ATC inline fuse holder waterproof` |
| 28 | ATC Fuse 10A | Blade fuse for solar panel side | 1 | 12–20 | `ATC blade fuse 10A` |
| 29 | Heat Shrink Tubing | Assorted (2mm–6mm) 100pcs | 1 set | 50–80 | `heat shrink tubing assorted` |
| 30 | Zip Ties | 100mm black UV-resistant 50pcs | 1 pack | 30–50 | `zip tie 100mm black` |
| 31 | Solder Wire | 60/40 0.8mm 50g | 1 | 50–60 | `solder wire 60/40 0.8mm` |

---

## 📦 SECTION 5: ENCLOSURE + MOUNTING (₱500–700)

| # | Item | Spec | Qty | Price (₱) | Shopee Search Term |
|---|---|---|-----|---|---|
| 32 | ABS Junction Box | Waterproof, 200×150×100mm | 1 | 200–300 | `ABS waterproof junction box 200x150x100` |
| 33 | Cable Gland PG9 | Waterproof, 4–8mm cable | 4 | 12–20 | `cable gland PG9 waterproof` |
| 34 | Nylon Standoff M3 | M3 hex + screw set 10pcs | 1 set | 35–50 | `M3 nylon standoff spacer` |
| 35 | M3 Screws + Nuts | Stainless, assorted 50pcs | 1 set | 50–80 | `M3 screw nut stainless set` |
| 36 | Perf Board | 7×9cm double-sided (if no PCB yet) | 1 | 25–40 | `perf board 7x9cm double side` |

---

## 💰 GRAND TOTAL

| Section | Items | Low | High |
|---|---|-----|---|
| ☀️ Solar + Battery | #1–5 | ₱1,480 | ₱2,280 |
| ⚡ Power PCB | #6–20 | ₱162 | ₱316 |
| 🔌 Connectors | #21–25 | ₱81 | ₱130 |
| 🔧 Wiring + Tools | #26–31 | ₱227 | ₱345 |
| 📦 Enclosure | #32–36 | ₱362 | ₱510 |
| **TOTAL** | **36 items** | **₱2,312** | **₱3,581** |

Note: PCB cost via JLCPCB (~₱400/5pcs) not included — order separately or use perf board.

---

## 🛒 ONE-CLICK SHOPEE SEARCH COPY

Paste these one by one sa Shopee search bar:

```
"S7" 30W solar panel 18V
PWM solar charge controller LiFePO4 12V 10A
32700 LiFePO4 6000mAh
4S LiFePO4 BMS 12.8V 30A balance
32700 battery holder 4S

LM2596-5.0 fixed TO-220
AMS1117-3.3 SOT-223
IRF9540N TO-220
2N7000 TO-92
SS34 SMD
68uH inductor
100uF 35V electrolytic
220uF 16V electrolytic
100nF ceramic
10uF 16V electrolytic
390k 1/4W resistor
100k 1/4W resistor

screw terminal 2P 5.08mm
pin header 2.54mm
XT60 connector
14AWG silicone wire
ATC fuse holder waterproof
heat shrink tubing
ABS waterproof junction box
cable gland PG9
```

---

## ⚠️ IMPORTANT NOTES

1. **R3 = 390kΩ** — check jud! Dili 330k (para Li-Ion na). 390k para LiFePO4 14.6V full charge
2. **LM2596-5.0 FIXED version** — ayaw palit ug adjustable (naay pot). Ang fixed version walay tuning needed
3. **4S BMS with BALANCE** — dapat naay balance wires (5 wires: B-, B1, B2, B3, B4+). Kung 3-wire ra, walay balance
4. **32700 cells** — ayaw i-solder directly ang terminals. Use holder or spot weld with nickel strips
5. **SS34 SMD** — kung di ka comfortable sa SMD, pwede 1N5822 through-hole (same 3A/40V Schottky)
6. **Fuse 10A** between solar panel and charge controller. **Fuse 5A** (PTC sa PCB) between battery and power board
7. **Gamay ra nga BMS** — 5-10A BMS igo na for this setup (300mA load ra). Ang 30A BMS parehas ra ug price so palita nalang daan

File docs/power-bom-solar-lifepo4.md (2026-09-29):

# Weather Station — Power Supply BOM (Solar + LiFePO4)

**Date:** June 29, 2026  
**Architecture:** Solar Panel → LiFePO4 Charge Controller → 4S LiFePO4 Battery → Power PCB (LM2596 + AMS1117)  
**Total System Voltage:** 12.8V nominal (4S LiFePO4), 14.6V full charge

---

## ⚡ Power Architecture

```
Solar Panel (30-50W, 18Vmp)
    │
    ▼
Charge Controller (CN3791, LiFePO4 profile)
    │
    ├──► 4S LiFePO4 Battery (12.8V / 6-12Ah)
    │       │
    │       ▼
    └──► Power PCB ──┬── LM2596-5.0 ──► +5V (MAX485)
                     │       └── AMS1117-3.3 ──► +3.3V (ESP32 + LoRa + sensors)
                     │
                     ├── MOSFET switch ──► 12V_SW (wind sensors)
                     │
                     └── 390k+100k divider ──► BAT_ADC (ESP32 monitoring)
```

---

## 📦 BOM: Solar + Battery Section

| # | Item | Spec | Qty | Est. Price (₱) | Shopee/Lazada Keywords |
|---|---|---|-----|---|---|
| 1 | **Solar Panel** | 30-50W, 18Vmp, monocrystalline | 1 | 800–1,500 | "30W 18V solar panel monocrystalline" |
| 2 | **Solar Charge Controller** | CN3791 module, 4S LiFePO4 configurable, 4A max | 1 | 150–300 | "CN3791 solar charger module 4S" |
| 3 | **LiFePO4 Battery Cells** | 32700 3.2V 6000mAh LiFePO4 | 4 | 200–350 each | "32700 LiFePO4 6000mAh" |
| 4 | **4S LiFePO4 BMS** | 4S 12.8V 30A with balance | 1 | 150–250 | "4S LiFePO4 BMS 12.8V 30A balance" |
| 5 | **Battery Holder** | 32700 4S holder / DIY spot-weld | 1 | 100–250 | "32700 battery holder 4S" |
| 6 | **DC Barrel Jack** | 5.5×2.1mm panel mount (for solar input) | 1 | 30–50 | "DC barrel jack panel mount 5.5 2.1" |
| 7 | **Inline Fuse Holder** | ATC/ATO fuse holder, 12AWG wire | 2 | 40–80 each | "ATC fuse holder inline 12AWG" |
| 8 | **ATC Fuse 10A** | Between solar panel and charge controller | 1 | 15–25 | "ATC fuse 10A blade" |
| 9 | **ATC Fuse 5A** | Between battery and power PCB | 1 | 15–25 | "ATC fuse 5A blade" |
| 10 | **Schottky Diode** | 1N5822 (3A/40V) — anti-backfeed from battery to panel at night | 1 | 15–25 | "1N5822 diode 3A 40V" |
| 11 | **XT60 Connector Pair** | Battery to PCB connection | 1 pair | 40–60 | "XT60 connector pair" |
| 12 | **Silicon Wire** | 14AWG red+black, 1m each | 2m | 80–120 | "14AWG silicone wire red black" |
| 13 | **Heat Shrink Tubing** | Assorted sizes | 1 set | 50–100 | "heat shrink tubing assorted" |
| | | | **Subtotal** | **₱2,000–3,800** | |

### ☀️ Solar Panel Sizing

| Panel | Power | Daily Energy (4.5 sun hrs) | Node Daily Consumption | Net Surplus |
|---|---|---|---|---|
| **30W** | 30W | 135 Wh/day | ~10.4 Wh/day (0.43W avg × 24h) | **+124.6 Wh** ✅ |
| 50W | 50W | 225 Wh/day | ~10.4 Wh/day | **+214.6 Wh** ✅ |

30W panel is already **13× more** than needed. 50W gives more cloudy-day buffer.
Node total consumption: ~300mA @ 12V avg × 24h = 86.4 Wh/day worst case, still net positive.

### 🔋 LiFePO4 Battery Sizing

| Capacity | Cells | Runtime (no sun) | Weight | Est. Cost |
|---|---|---|---|---|
| **6Ah** | 4× 32700 6000mAh | ~20 hours | ~580g | ₱800–1,400 |
| 12Ah | 4× 32700 6000mAh ×2 parallel | ~40 hours | ~1.2kg | ₱1,600–2,800 |

6Ah is enough — with 30W solar, battery recharges fully in <2 hours of sun.

### ⚙️ CN3791 Configuration for LiFePO4 (4S)

The CN3791 module needs resistor configuration for LiFePO4 voltage:

| Parameter | LiFePO4 Value | Resistor Formula |
|---|---|---|
| Float voltage | **14.6V** (3.65V/cell × 4) | R_fb = (V_bat / 2.416 - 1) × R_ref |
| MPPT voltage | **18V** (panel Vmp) | Set by input divider |
| Charge current | 2A max (safe for 32700) | R_sense = 0.12 / I_charge |
| Termination | C/10 (600mA for 6Ah) | Automatic |

**Important:** Some CN3791 modules come pre-set for Li-Ion (12.6V). Check/modify the feedback resistors. If hassle, use an **XY-L30A** or **XH-M604** charge controller instead — direct voltage setting via potentiometer, no resistor math.

### 🪫 LiFePO4 Voltage Divider for BAT_ADC

| Component | Old (Li-Ion 3S) | New (LiFePO4 4S) |
|---|---|---|
| R3 (top) | 330k | **390k** |
| R4 (bottom) | 100k | 100k |
| Ratio | 4.30 | **4.90** |
| ADC at 14.6V | — | 2.98V ✅ |
| ADC at 12.8V | — | 2.61V |
| ADC at 10.0V (empty) | — | 2.04V |

```cpp
// Updated for LiFePO4 4S
#define BAT_R1  390.0   // kΩ (top resistor — UPDATED from 330k)
#define BAT_R2  100.0   // kΩ (bottom resistor)
#define BAT_DIVIDER ((BAT_R1 + BAT_R2) / BAT_R2)  // = 4.90
```

---

## 📦 BOM: Power PCB Section (already designed)

| # | Ref | Value | Qty | Unit Price (₱) | Shopee/Lazada Keywords |
|---|-----|---|-----|---|---|
| 14 | J1 | DC Barrel Jack (PCB mount) | 1 | 15–25 | "DC barrel jack PCB 5.5 2.1" |
| 15 | F1 | PTC 5A resettable fuse | 1 | 15–30 | "PTC fuse 5A resettable" |
| 16 | D1, D2 | SS34 Schottky 3A/40V SMD | 2 | 5–10 each | "SS34 SMD diode" |
| 17 | C1 | 100µF/35V electrolytic | 1 | 10–20 | "100uF 35V electrolytic capacitor" |
| 18 | C2, C5 | 100nF ceramic | 2 | 3–5 each | "100nF ceramic capacitor" |
| 19 | **U1** | **LM2596-5.0 fixed** TO-220-5 | 1 | 60–100 | "LM2596-5.0 fixed TO-220" |
| 20 | C3 | 220µF/16V electrolytic | 1 | 10–20 | "220uF 16V electrolytic capacitor" |
| 21 | C4, C6 | 10µF ceramic/electrolytic | 2 | 5–10 each | "10uF 16V capacitor" |
| 22 | L1 | 68µH inductor (3A rated) | 1 | 30–60 | "68uH inductor 3A toroidal" |
| 23 | **U2** | **AMS1117-3.3** SOT-223 | 1 | 15–30 | "AMS1117-3.3 SOT-223" |
| 24 | Q1 | IRF9540N P-ch MOSFET TO-220 | 1 | 30–60 | "IRF9540N TO-220 MOSFET" |
| 25 | Q2 | 2N7000 N-ch MOSFET TO-92 | 1 | 10–20 | "2N7000 TO-92 MOSFET" |
| 26 | R1 | 10kΩ 1/4W resistor | 1 | 2–5 | "10k ohm resistor 1/4W" |
| 27 | R2 | 1kΩ 1/4W resistor | 1 | 2–5 | "1k ohm resistor 1/4W" |
| 28 | R3 | **390kΩ** 1/4W resistor (LiFePO4) | 1 | 2–5 | "390k ohm resistor 1/4W" |
| 29 | R4 | 100kΩ 1/4W resistor | 1 | 2–5 | "100k ohm resistor 1/4W" |
| 30 | J2–J4 | Screw terminal 2P 5.08mm | 3 | 10–15 each | "screw terminal 2P 5.08mm PCB" |
| 31 | J5–J6 | Pin header 2P 2.54mm male | 2 | 3–5 each | "pin header 2P 2.54mm male" |
| 32 | PCB | Custom PCB (JLCPCB 5pcs) | 5 | ~400 | "JLCPCB 2-layer 60×50mm" |
| | | | **Subtotal** | **~₱780–1,200** | |

---

## 📦 BOM: Enclosure & Misc

| # | Item | Spec | Qty | Est. Price (₱) | Keywords |
|---|---|---|-----|---|---|
| 33 | Waterproof Enclosure | ABS junction box, min 200×150×100mm | 1 | 250–500 | "ABS waterproof junction box outdoor" |
| 34 | Cable Glands | PG9 or PG11, 3-6mm cable | 4 | 15–25 each | "PG9 cable gland waterproof" |
| 35 | DIN Rail Mount | Optional, for clean install | 1 | 50–100 | "DIN rail mount bracket" |
| 36 | Nylon Standoffs | M3 hex, assorted heights | 1 set | 30–60 | "M3 nylon standoff kit" |
| 37 | M3 Screws + Nuts | Stainless, assorted | 1 set | 50–100 | "M3 screw nut stainless kit" |
| 38 | Zip Ties | 100mm, UV-resistant black | 1 pack | 30–50 | "UV zip tie 100mm black" |
| 39 | Silicone Sealant | Neutral cure (for cable glands) | 1 tube | 80–150 | "silicone sealant neutral cure" |
| | | | **Subtotal** | **₱600–1,200** | |

---

## 💰 Total Cost Summary

| Section | Low Est. | High Est. |
|---|---|---|
| Solar + Battery | ₱2,000 | ₱3,800 |
| Power PCB | ₱780 | ₱1,200 |
| Enclosure + Misc | ₱600 | ₱1,200 |
| **TOTAL** | **₱3,380** | **₱6,200** |

Kung naa na kay uban parts (wires, connectors, solder), mas cheaper pa.

---

## 🔄 Alternative: Ready-Made Solar Charge Controller

Kung hassle ang CN3791 configuration, pwede ni:

| Controller | Price (₱) | Notes |
|---|---|---|
| **XY-L30A** | 250–400 | Adjustable voltage relay controller, 30A, NOT solar-optimized |
| **XH-M604** | 200–350 | Battery charge control module, voltage set via pot |
| **PWM 10A LiFePO4** | 400–700 | Dedicated solar PWM, pre-set for LiFePO4 4S |
| **MPPT 10A** (EPEver clone) | 800–1,500 | True MPPT, better efficiency, LCD display |

Recommended: **PWM 10A LiFePO4 controller** — plug and play, no configuration, ₱400–700.

---

## ⚠️ Reminders

1. **Diode between solar panel and CN3791**: 1N5822 Schottky prevents battery from back-feeding into the panel at night (some CN3791 modules have this built-in — check)
2. **BMS is REQUIRED**: LiFePO4 cells MUST have a balance BMS — overcharge = fire risk, over-discharge = permanent cell damage
3. **32700 cells**: Spot-weld or use a 4S holder. Do NOT solder directly to cell terminals — heat damages LiFePO4 cells
4. **Fuse BEFORE and AFTER charge controller**: 10A panel-side, 5A battery-side
5. **Enclosure ventilation**: Charge controller and LM2596 generate heat. Add small vent holes or a breather vent
6. **Update R3 to 390k**: LiFePO4 14.6V full charge > Li-Ion 12.6V. Old 330k divider would saturate ESP32 ADC

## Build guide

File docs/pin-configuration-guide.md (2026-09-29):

# ESP32-S3 Weather Node — Pin Configuration Guide

**Board:** ESP32-S3 N16R8 (HW678 v0.0.0)
**Project:** Weather Station Research
**Date:** June 10, 2026
**Related:** `docs/power-configuration.md` (12V power supply, BOM, perf board layout)

---

## Pin Map Overview

```
                    ESP32-S3 HW678 (N16R8)
                  ┌─────────────────────────┐
                  │  USB-C (USB)  USB-C (COM)│  ← Use USB port for programming
                  │                         │
    I2C SDA ───── │ GPIO1              GPIO48│ ───── RGB LED (WS2812)
    I2C SCL ───── │ GPIO2              GPIO47│
  OneWire ─────── │ GPIO3              GPIO38│ (PSRAM reserved)
      E22 M0 ───── │ GPIO4              GPIO37│ (PSRAM reserved)
      E22 M1 ───── │ GPIO5              GPIO36│ (PSRAM reserved)
     E22 RXD ───── │ GPIO6              GPIO35│ (PSRAM reserved)
     E22 TXD ───── │ GPIO7              GPIO34│ (PSRAM reserved)
     E22 AUX ───── │ GPIO8              GPIO33│ (PSRAM reserved)
                   │ GPIO9              GPIO32│ (PSRAM reserved)
Rain Gauge ────── │ GPIO10             GPIO31│ (PSRAM reserved)
                  │ GPIO11             GPIO30│ (PSRAM reserved)
                  │ GPIO12             GPIO29│ (PSRAM reserved)
Soil Moisture ─── │ GPIO13             GPIO28│ (PSRAM reserved)
 Battery ADC ──── │ GPIO14             GPIO27│ (PSRAM reserved)
  Sensor PWR ──── │ GPIO15             GPIO26│ (PSRAM reserved)
 Unused     ──── │ GPIO16             GPIO21│
  RS485 TX ────── │ GPIO17             GPIO20│ (USB D+)
  RS485 RX ────── │ GPIO18             GPIO19│ (USB D-)
                  │    GND  3.3V  5V         │
                  └─────────────────────────┘
```

> **Note:** GPIO26–37 are reserved by the octal PSRAM (8MB). Do NOT use these pins.
> GPIO19–20 are the native USB D-/D+ pins. Do NOT use.

---

## Sensor Wiring

### 1. LoRa Radio (E22-900T22D UART)

| E22 Pin | ESP32-S3 Pin | Notes |
|---|---|---|
| M0 | GPIO4 | Operating-mode select 0 |
| M1 | GPIO5 | Operating-mode select 1 |
| RXD | GPIO6 | ESP32 TX → E22 RXD |
| TXD | GPIO7 | E22 TXD → ESP32 RX |
| AUX | GPIO8 | HIGH means module ready |
| VCC | +5V | Add 470µF + 100nF close to module |
| GND | GND | Common ground |
| ANT | SMA connector | 900/915 MHz antenna |

Firmware uses transparent UART mode at 9600 baud (M0=LOW, M1=LOW). Air channel,
air data rate and TX power are stored in the E22 module and must match the gateway.

---

### 2. BME280 (Temperature, Humidity, Pressure)

| BME280 Pin | ESP32-S3 Pin | Notes |
|---|---|---|
| VCC | 3.3V | |
| GND | GND | |
| SDA | GPIO1 | I2C data |
| SCL | GPIO2 | I2C clock |
| CSB | 3.3V | Pull high for I2C mode |
| SDO | GND | GND = addr 0x76, VCC = addr 0x77 |

```
BME280                   ESP32-S3
┌────────┐              ┌──────────┐
│ VCC ───────────────── 3.3V      │
│ GND ───────────────── GND       │
│ SDA ───────────────── GPIO1     │
│ SCL ───────────────── GPIO2     │
│ CSB ──── 3.3V (I2C)            │
│ SDO ──── GND (addr 0x76)       │
└────────┘              └──────────┘
```

**I2C Address:** 0x76

---

### 3. LTR390 UV Sensor

| LTR390 Pin | ESP32-S3 Pin | Notes |
|---|---|---|
| VCC | 3.3V | |
| GND | GND | |
| SDA | GPIO1 | Shared I2C bus with BME280 |
| SCL | GPIO2 | Shared I2C bus with BME280 |
| INT | — | Optional, not connected |

```
LTR390                   ESP32-S3
┌────────┐              ┌──────────┐
│ VCC ───────────────── 3.3V      │
│ GND ───────────────── GND       │
│ SDA ───────────────── GPIO1     │  ← Shared with BME280
│ SCL ───────────────── GPIO2     │  ← Shared with BME280
│ INT ──── (not connected)        │
└────────┘              └──────────┘
```

**I2C Address:** 0x53

---

### 4. Rain Gauge (Tipping Bucket)

| Rain Gauge Wire | ESP32-S3 Pin | Notes |
|---|---|---|
| Wire 1 | GND | |
| Wire 2 | GPIO10 | Interrupt input (internal pull-up) |

```
Rain Gauge               ESP32-S3
┌──────────┐            ┌──────────┐
│ Wire 1 ─────────────── GND       │
│ Wire 2 ─────────────── GPIO10    │  ← Internal pull-up enabled
└──────────┘            └──────────┘
```

**Calibration:** 0.2794 mm per tip

---

### 5. RS485 Wind Sensors (Anemometer + Wind Vane)

Both sensors share the same RS485 bus (Modbus RTU).

### DIYMORE isolated automatic-direction RS485 module

The selected module has TTL pins **VCC, TXD, RXD, GND** (top to bottom in the supplied image), and **A+, B−, earth** screw terminals. U4 uses logical terminal numbers, not a verified PCB footprint.

| Module terminal | Connection |
|---|---|
| VCC | 3.3V BUS from AMS1117-3.3 |
| TXD | GPIO18 / UART1 RX — provisional: assumes module output |
| RXD | GPIO17 / UART1 TX — provisional: assumes module input |
| GND | ESP32/common GND (TTL side) |
| A+ | Both wind sensors' A bus |
| B− | Both wind sensors' B bus |
| Earth | Reserved/unconnected in this design; separate from TTL GND |

**Verify UART directions before wiring:** the product image labels TXD/RXD but does not specify input/output. The schematic provisionally uses crossed UART wiring. If the board labels refer to the host UART instead, connect GPIO17 TX to module TXD input and GPIO18 RX to module RXD output. Confirm with the seller's pin-direction diagram or datasheet; do not infer direction solely from the names.

- Supply the TTL side at **3.3V**, consistent with the pictured 3.3V/5V marking. Confirm its output signal is 3.3V-compatible before connecting ESP32 RX.
- Automatic direction control: **no DE/RE wire; GPIO16 is unused**. R8/R9 from the old 5V receive divider are removed. C7 remains 100nF across TTL VCC/GND.
- R10 is **120Ω, DNP by default**. Fit only when this is a bus endpoint and the module does not already provide enabled termination; avoid duplicate parallel termination.
- Do not bridge the pictured earth/protection terminal to TTL GND. Its grounding arrangement needs the module documentation. Sensor supply return remains the existing common GND; this design does not claim complete system galvanic isolation.
- Wind sensors retain **12V_SW** power via GPIO15/MOSFET. Never feed their 12V into module VCC.

**Modbus Parameters:**
- Baud: 9600 (default, check sensor datasheet)
- Data bits: 8
- Stop bits: 1
- Parity: None

**Modbus Slave IDs:**
- Anemometer (wind speed): ID 1
- Wind Vane (direction): ID 2

---

### 6. Soil Moisture Sensor (Capacitive v1.2)

| Soil Sensor Pin | ESP32-S3 Pin | Notes |
|---|---|---|
| VCC | Sensor PWR (GPIO15) | Switched via MOSFET — only powered during reading |
| GND | GND | |
| AOUT | GPIO13 | Analog input (ADC2) |

```
Soil Moisture Sensor      ESP32-S3
┌────────────────┐       ┌──────────┐
│ VCC ────────────────── GPIO15    │  ← MOSFET-switched power
│ GND ────────────────── GND       │
│ AOUT ───────────────── GPIO13    │  ← Analog (0-3.3V)
└────────────────┘       └──────────┘
```

> **Important:** Power the sensor via a MOSFET controlled by GPIO15,
> NOT directly from 3.3V. This prevents electrolysis corrosion and
> saves battery power during deep sleep.

**MOSFET circuit:**
```
   GPIO15 ──[10k]──┬── G (IRLZ44N or similar)
                    │
   3.3V ─────────── D
                    │
                    S ──── Sensor VCC
                    │
                   GND
```

---

### 7. Battery Voltage Monitor (12V System)

| Voltage Divider | ESP32-S3 Pin | Notes |
|---|---|---|
| Battery (+) → 330k → ADC | GPIO14 | Top resistor (updated for 12V) |
| ADC → 100k → GND | | Bottom resistor |
| ADC read point | GPIO14 | V_adc = V_batt × (100/(100+330)) |

```
Battery (+) 12.6V max
    │
  [330kΩ]     ← R1 (top — was 100k for 3.7V system)
    │
    ├──── GPIO14 (ADC2)   ← Max = 12.6 × 100/430 = 2.93V (safe)
    │
  [100kΩ]     ← R2 (bottom — was 220k for 3.7V system)
    │
   GND
```

**Formula:** `V_battery = V_adc × (330 + 100) / 100 = V_adc × 4.30`

> ⚠️ Updated for 12V system. Old values (100k/220k) were for 3.7V Li-Ion and will give wrong readings on a 12V battery. See `docs/power-configuration.md` for details.

---

### 8. RGB Status LED (WS2812)

| WS2812 Pin | ESP32-S3 Pin | Notes |
|---|---|---|
| VCC | 5V or 3.3V | Onboard — no external wiring needed |
| GND | GND | Onboard |
| DIN | GPIO48 | Data in |

```
The RGB LED is onboard the HW678 board — no external wiring needed.
Connected to GPIO48. Uses Adafruit NeoPixel library (NEO_GRB + NEO_KHZ800).

Status Colors:
  Blue pulse    → Booting
  Dim blue      → TEST_MODE idle
  Yellow        → Reading sensors
  Green flash   → TX success
  Red blink     → Error
  Off           → Deep sleep
```

---

## Power Pin Summary

Power is supplied by a 12V rail. See `docs/power-configuration.md` for the complete power supply design.

| Pin | Function | Voltage |
|-----|---|---|
| GPIO15 | 12V sensor bus MOSFET gate — HIGH = wind sensors powered | 3.3V signal → switches 12V |
| 3.3V BUS | ESP32, LoRa, BME280, LTR390, DS18B20, Soil | 3.3V (from HT7333-A LDO) |
| 3.3V BUS | DIYMORE auto RS485 | 3.3V (AMS1117) |
| 12V_SW | Anemometer + Wind Vane | 12V (MOSFET-switched via GPIO15) |

> GPIO15 drives a two-transistor level shifter (2N7000 + IRF9540) that switches the 12V rail to the wind sensors. All low-voltage sensors are always-on and manage their own sleep states.

---

## I2C Bus Map

```
        3.3V
         │
    ┌────┴────┐
    │  BME280  │  Address: 0x76
    │  SDA SCL │
    └────┬────┘
         │
    ┌────┼────┐
    │  LTR390  │  Address: 0x53
    │  SDA SCL │
    └────┬────┘
         │
    GPIO1 ──── SDA
    GPIO2 ──── SCL
```

Both sensors share GPIO1 (SDA) and GPIO2 (SCL) with no address conflict.

---

## Quick Reference

| GPIO | Function | Type | Notes |
|---|---|---|---|
| 1 | I2C SDA | I2C | BME280 + LTR390 |
| 2 | I2C SCL | I2C | BME280 + LTR390 |
| 3 | OneWire | Digital | DS18B20 (4.7k pull-up to 3.3V) |
| 4 | LoRa NSS | SPI CS | SX1276 |
| 5 | LoRa SCK | SPI CLK | SX1276 |
| 6 | LoRa MOSI | SPI | SX1276 |
| 7 | LoRa MISO | SPI | SX1276 |
| 8 | LoRa RST | Digital OUT | SX1276 reset |
| 9 | LoRa DIO0 | Digital IN | SX1276 interrupt |
| 10 | Rain Gauge | Interrupt | Internal pull-up |
| 13 | Soil Moisture | ADC2 | Capacitive analog |
| 14 | Battery | ADC2 | Voltage divider 100k/220k |
| 15 | Sensor PWR | Digital OUT | MOSFET gate |
| 16 | Unused | — | Automatic RS485 direction |
| 17 | RS485 TX | UART1 TX | Wind sensors |
| 18 | RS485 RX | UART1 RX | Wind sensors |
| 48 | RGB LED | WS2812 | Onboard status LED |

---

## Firmware Commands

```bash
# Enter project directory
cd ~/dev/projects/weather-station/firmware/weather-node

# Build
sg dialout -c "pio run -e s3"

# Flash + monitor
sg dialout -c "pio run -e s3 -t upload"

# Read serial output
python3 -c "
import serial
s = serial.Serial('/dev/ttyACM0', 115200, timeout=10)
while True: print(s.readline().decode(errors='replace').rstrip())
"
```

## Switch to Production Mode

Edit `src/config.h`:

```c
#define TEST_MODE       false   // was true
#define SLEEP_INTERVAL_S  120   // was 5

#define HAS_BME280      true
#define HAS_LTR390      true
#define HAS_RAIN_GAUGE  true
#define HAS_ANEMOMETER  true
#define HAS_WIND_VANE   true
#define HAS_SOIL_MOIST  true
```

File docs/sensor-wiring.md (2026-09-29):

# Sensor Wiring Reference

> **Power-rail correction (2026-09-03):** GPIO assignments remain useful, but the final schematic uses Mini560 12V→5V plus AMS1117-3.3—not the dual-Mini560 architecture described in older sections below. Canonical source: `hardware/node-pcb/weather-node-complete.kicad_sch`.

**Board:** ESP32-S3 N16R8 (HW678 v0.0.0)  
**Project:** Weather Station Research  
**Date:** June 14, 2026  
**Revision:** v2.0 — Updated for 12V system, dual Mini560 power architecture  

> See `docs/power-configuration.md` for complete power supply design.  
> See `docs/pin-configuration-guide.md` for GPIO assignments.

---

## Power Rails Summary

```
12V Battery/Solar
    │
    ├── Mini560 #1 (12V→5V) ──► 5V BUS ──► E22-900T22D
    │
    ├── Mini560 #2 (12V→3.3V) ──► 3.3V BUS ──► ESP32-S3, BME280, LTR390, DS18B20, Soil
    │
    └── MOSFET Switch (GPIO15) ──► 12V_SW ──► RS485 Anemometer + Wind Vane
```

---

## Individual Sensor Wiring

### BME280 (Temperature, Humidity, Pressure)

```
BME280    → ESP32-S3
VIN       → 3.3V BUS
GND       → GND
SCL       → GPIO1 (I2C)
SDA       → GPIO2 (I2C)
```

- I2C address: 0x76 (SDO to GND) or 0x77 (SDO to VCC)
- Library: Adafruit BME280

### LTR390 (UV / Ambient Light)

```
LTR390    → ESP32-S3
VIN       → 3.3V BUS
GND       → GND
SCL       → GPIO1 (I2C, shared with BME280)
SDA       → GPIO2 (I2C, shared with BME280)
INT       → (optional, not used)
```

- I2C address: 0x53
- Library: Adafruit LTR390

### DS18B20 (Precision Temperature)

```
DS18B20   → ESP32-S3
VDD (red) → 3.3V BUS
DQ  (yellow) → GPIO3 (OneWire)
GND (black) → GND
4.7kΩ resistor between DQ and VDD
```

- Library: DallasTemperature + OneWire
- Multiple sensors can share one pin (each has unique 64-bit ROM ID)

### Rain Gauge (Tipping Bucket)

```
Rain Gauge → ESP32-S3
Wire 1     → GND
Wire 2     → GPIO10 (internal pull-up enabled)
```

- Reed switch: normally open, closes on tip
- Each tip = calibrated volume (typically 0.2-0.3mm)

### Soil Moisture (Capacitive / Resistive)

```
Sensor     → ESP32-S3
VCC        → 3.3V BUS (or GPIO13 for switched power)
GND        → GND
AOUT       → GPIO14 (ADC) — but GPIO14 used for battery ADC
```

> **Note:** Soil moisture ADC conflicts with battery monitoring on GPIO14. Use GPIO13 to switch sensor VCC and read via a different ADC pin, or remap battery ADC to another pin.

---

## RS485 Wind Sensors

### DIYMORE isolated automatic-direction RS485 module

The selected module has TTL pins **VCC, TXD, RXD, GND** (top to bottom in the supplied image), and **A+, B−, earth** screw terminals. U4 uses logical terminal numbers, not a verified PCB footprint.

| Module terminal | Connection |
|---|---|
| VCC | 3.3V BUS from AMS1117-3.3 |
| TXD | GPIO18 / UART1 RX — provisional: assumes module output |
| RXD | GPIO17 / UART1 TX — provisional: assumes module input |
| GND | ESP32/common GND (TTL side) |
| A+ | Both wind sensors' A bus |
| B− | Both wind sensors' B bus |
| Earth | Reserved/unconnected in this design; separate from TTL GND |

**Verify UART directions before wiring:** the product image labels TXD/RXD but does not specify input/output. The schematic provisionally uses crossed UART wiring. If the board labels refer to the host UART instead, connect GPIO17 TX to module TXD input and GPIO18 RX to module RXD output. Confirm with the seller's pin-direction diagram or datasheet; do not infer direction solely from the names.

- Supply the TTL side at **3.3V**, consistent with the pictured 3.3V/5V marking. Confirm its output signal is 3.3V-compatible before connecting ESP32 RX.
- Automatic direction control: **no DE/RE wire; GPIO16 is unused**. R8/R9 from the old 5V receive divider are removed. C7 remains 100nF across TTL VCC/GND.
- R10 is **120Ω, DNP by default**. Fit only when this is a bus endpoint and the module does not already provide enabled termination; avoid duplicate parallel termination.
- Do not bridge the pictured earth/protection terminal to TTL GND. Its grounding arrangement needs the module documentation. Sensor supply return remains the existing common GND; this design does not claim complete system galvanic isolation.
- Wind sensors retain **12V_SW** power via GPIO15/MOSFET. Never feed their 12V into module VCC.

### Anemometer + Wind Vane (field wiring)

```
12V_SW ──┬── Anemometer V+ (red/brown)
         └── Wind Vane V+ (red/brown)

GND ─────┬── Anemometer GND (black)
         └── Wind Vane GND (black)

RS485 A ─┬── Anemometer A (yellow or green)
         └── Wind Vane A (yellow or green)

RS485 B ─┬── Anemometer B (blue or white)
         └── Wind Vane B (blue or white)
```

- Both sensors share the same RS485 bus
- Each has a unique Modbus address — query individually
- Powered via 12V_SW (GPIO15 controls MOSFET) — only ON during reading

---

## Battery Voltage Divider (12V System)

```
Battery (+) 12.6V max
    │
  [330kΩ]     ← R1 (top resistor)
    │
    ├──── GPIO14 (ADC2)   ← V_adc = V_bat × 100/(330+100)
    │
  [100kΩ]     ← R2 (bottom resistor)
    │
   GND
```

| Parameter | Value |
|---|---|
| R1 (top) | 330kΩ |
| R2 (bottom) | 100kΩ |
| Divider ratio | 0.2326 |
| Max ADC voltage | 2.93V (at 12.6V) |
| Firmware formula | `V_battery = V_adc × 4.30` |

---

## Power System (Dual Mini560)

```
Solar Panel (30-50W, 18Vmp)
    │
    ▼
CN3791 Charge Controller
    │
    ▼
3S Li-Ion Battery (11.1V nominal, 9.0–12.6V range)
    │
    ▼
12V COMMON RAIL (reverse-polarity Schottky + 100µF bulk cap)
    │
    ├── Mini560 #1 (12V→5V fixed) ──► 5V BUS ──► E22-900T22D
    │
    ├── Mini560 #2 (12V→3.3V fixed) ──► 3.3V BUS ──► ESP32 + Sensors
    │
    └── MOSFET Switch (GPIO15 → IRF9540) ──► 12V_SW ──► Wind Sensors
```

| Rail | Source | Voltage | Load |
|---|---|---|---|
| 12V_SW | 12V via MOSFET | 12V | RS485 anemometer + wind vane |
| 5V BUS | Mini560 #1 | 5.0V fixed | E22-900T22D |
| 3.3V BUS | Mini560 #2 | 3.3V fixed | ESP32-S3, BME280, LTR390, DS18B20, Soil |

---

## Current Budget (per 2-minute read cycle)

| Phase | Duration | Current @ 12V | Energy |
|---|---|---|---|
| Wake + Init | 0.5s | 80 mA | 40 mAs |
| Sensor read (3.3V bus) | 0.3s | 40 mA | 12 mAs |
| Wind sensors (12V_SW) | 1.0s | 50 mA | 50 mAs |
| E22 LoRa TX (up to 22dBm) | 1.0s | Measure actual | TBD |
| **Total active (5-min cycle)** | **2.8s** | — | **222 mAs** |
| Deep sleep (296.2s) | 297.2s | 0.6 mA | 178 mAs |
| **Total per 5-min cycle** | **300s** | — | **~400 mAs** |

**Daily energy:** 288 cycles × 400 mAs = 115,200 mAs = **32 mAh @ 12V = 0.38 Wh**

**Battery life (3S 3500mAh, no solar):** ~109 days  
**With 30W solar (135 Wh/day in PH sun):** Indefinite / always full

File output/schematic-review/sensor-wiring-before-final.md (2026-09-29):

# Sensor Wiring Reference

**Board:** ESP32-S3 N16R8 (HW678 v0.0.0)  
**Project:** Weather Station Research  
**Date:** June 14, 2026  
**Revision:** v2.0 — Updated for 12V system, dual Mini560 power architecture  

> See `docs/power-configuration.md` for complete power supply design.  
> See `docs/pin-configuration-guide.md` for GPIO assignments.

---

## Power Rails Summary

```
12V Battery/Solar
    │
    ├── Mini560 #1 (12V→5V) ──► 5V BUS ──► MAX485 + E22-900T22D
    │
    ├── Mini560 #2 (12V→3.3V) ──► 3.3V BUS ──► ESP32-S3, BME280, LTR390, DS18B20, Soil
    │
    └── MOSFET Switch (GPIO15) ──► 12V_SW ──► RS485 Anemometer + Wind Vane
```

---

## Individual Sensor Wiring

### BME280 (Temperature, Humidity, Pressure)

```
BME280    → ESP32-S3
VIN       → 3.3V BUS
GND       → GND
SCL       → GPIO1 (I2C)
SDA       → GPIO2 (I2C)
```

- I2C address: 0x76 (SDO to GND) or 0x77 (SDO to VCC)
- Library: Adafruit BME280

### LTR390 (UV / Ambient Light)

```
LTR390    → ESP32-S3
VIN       → 3.3V BUS
GND       → GND
SCL       → GPIO1 (I2C, shared with BME280)
SDA       → GPIO2 (I2C, shared with BME280)
INT       → (optional, not used)
```

- I2C address: 0x53
- Library: Adafruit LTR390

### DS18B20 (Precision Temperature)

```
DS18B20   → ESP32-S3
VDD (red) → 3.3V BUS
DQ  (yellow) → GPIO3 (OneWire)
GND (black) → GND
4.7kΩ resistor between DQ and VDD
```

- Library: DallasTemperature + OneWire
- Multiple sensors can share one pin (each has unique 64-bit ROM ID)

### Rain Gauge (Tipping Bucket)

```
Rain Gauge → ESP32-S3
Wire 1     → GND
Wire 2     → GPIO10 (internal pull-up enabled)
```

- Reed switch: normally open, closes on tip
- Each tip = calibrated volume (typically 0.2-0.3mm)

### Soil Moisture (Capacitive / Resistive)

```
Sensor     → ESP32-S3
VCC        → 3.3V BUS (or GPIO13 for switched power)
GND        → GND
AOUT       → GPIO14 (ADC) — but GPIO14 used for battery ADC
```

> **Note:** Soil moisture ADC conflicts with battery monitoring on GPIO14. Use GPIO13 to switch sensor VCC and read via a different ADC pin, or remap battery ADC to another pin.

---

## RS485 Wind Sensors

### MAX485 Transceiver (on main board)

```
MAX485    → ESP32-S3
VCC       → 5V BUS
GND       → GND
RO (RX)   → GPIO18 (UART1 RX)
DI (TX)   → GPIO17 (UART1 TX)
RE + DE   → GPIO16 (tied together, HIGH=TX, LOW=RX)
A         → RS485 A line (to both sensors)
B         → RS485 B line (to both sensors)
```

### Anemometer + Wind Vane (field wiring)

```
12V_SW ──┬── Anemometer V+ (red/brown)
         └── Wind Vane V+ (red/brown)

GND ─────┬── Anemometer GND (black)
         └── Wind Vane GND (black)

RS485 A ─┬── Anemometer A (yellow or green)
         └── Wind Vane A (yellow or green)

RS485 B ─┬── Anemometer B (blue or white)
         └── Wind Vane B (blue or white)
```

- Both sensors share the same RS485 bus
- Each has a unique Modbus address — query individually
- Powered via 12V_SW (GPIO15 controls MOSFET) — only ON during reading

---

## Battery Voltage Divider (12V System)

```
Battery (+) 12.6V max
    │
  [330kΩ]     ← R1 (top resistor)
    │
    ├──── GPIO14 (ADC2)   ← V_adc = V_bat × 100/(330+100)
    │
  [100kΩ]     ← R2 (bottom resistor)
    │
   GND
```

| Parameter | Value |
|---|---|
| R1 (top) | 330kΩ |
| R2 (bottom) | 100kΩ |
| Divider ratio | 0.2326 |
| Max ADC voltage | 2.93V (at 12.6V) |
| Firmware formula | `V_battery = V_adc × 4.30` |

---

## Power System (Dual Mini560)

```
Solar Panel (30-50W, 18Vmp)
    │
    ▼
CN3791 Charge Controller
    │
    ▼
3S Li-Ion Battery (11.1V nominal, 9.0–12.6V range)
    │
    ▼
12V COMMON RAIL (reverse-polarity Schottky + 100µF bulk cap)
    │
    ├── Mini560 #1 (12V→5V fixed) ──► 5V BUS ──► MAX485 + E22-900T22D
    │
    ├── Mini560 #2 (12V→3.3V fixed) ──► 3.3V BUS ──► ESP32 + Sensors
    │
    └── MOSFET Switch (GPIO15 → IRF9540) ──► 12V_SW ──► Wind Sensors
```

| Rail | Source | Voltage | Load |
|---|---|---|---|
| 12V_SW | 12V via MOSFET | 12V | RS485 anemometer + wind vane |
| 5V BUS | Mini560 #1 | 5.0V fixed | MAX485 + E22-900T22D |
| 3.3V BUS | Mini560 #2 | 3.3V fixed | ESP32-S3, BME280, LTR390, DS18B20, Soil |

---

## Current Budget (per 2-minute read cycle)

| Phase | Duration | Current @ 12V | Energy |
|---|---|---|---|
| Wake + Init | 0.5s | 80 mA | 40 mAs |
| Sensor read (3.3V bus) | 0.3s | 40 mA | 12 mAs |
| Wind sensors (12V_SW) | 1.0s | 50 mA | 50 mAs |
| E22 LoRa TX (up to 22dBm) | 1.0s | Measure actual | TBD |
| **Total active (5-min cycle)** | **2.8s** | — | **222 mAs** |
| Deep sleep (296.2s) | 297.2s | 0.6 mA | 178 mAs |
| **Total per 5-min cycle** | **300s** | — | **~400 mAs** |

**Daily energy:** 288 cycles × 400 mAs = 115,200 mAs = **32 mAh @ 12V = 0.38 Wh**

**Battery life (3S 3500mAh, no solar):** ~109 days  
**With 30W solar (135 Wh/day in PH sun):** Indefinite / always full

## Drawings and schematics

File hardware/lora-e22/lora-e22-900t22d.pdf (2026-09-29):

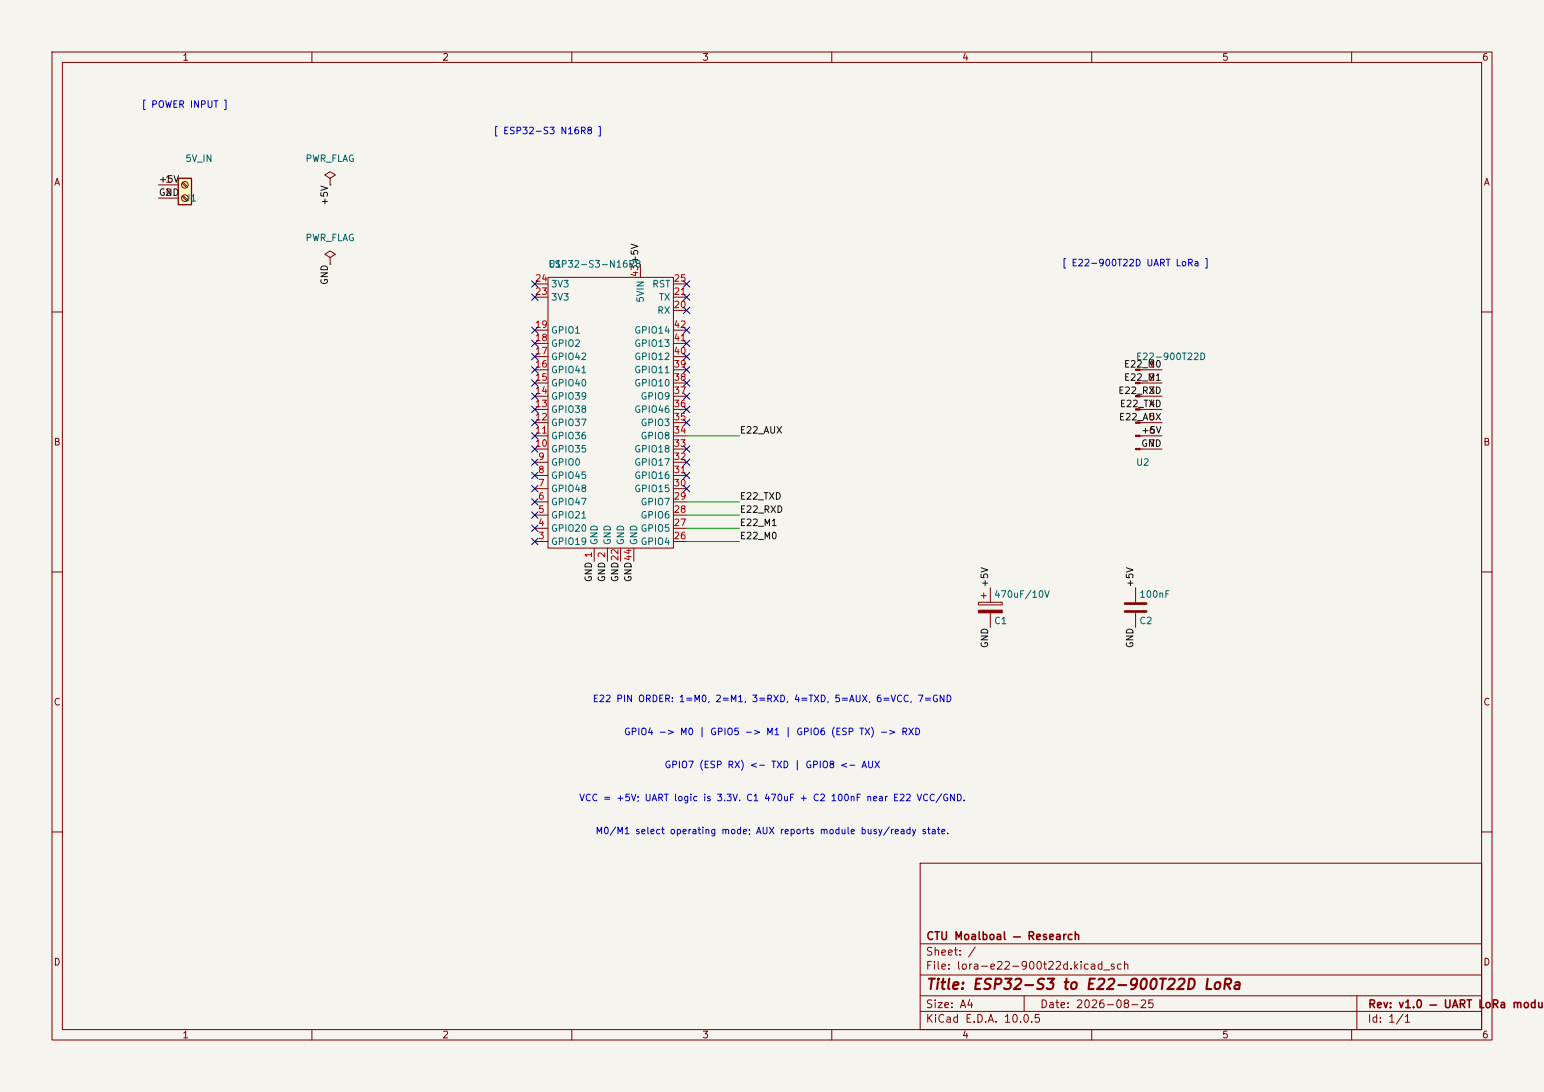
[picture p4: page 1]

[ ESP32-S3 N16R8 ]E22 PIN ORDER: 1=M0, 2=M1, 3=RXD, 4=TXD, 5=AUX, 6=VCC, 7=GND

GPIO7 (ESP RX) <- TXD | GPIO8 <- AUX

VCC = +5V; UART logic is 3.3V. C1 470uF + C2 100nF near E22 VCC/GND.

M0/M1 select operating mode; AUX reports module busy/ready state.

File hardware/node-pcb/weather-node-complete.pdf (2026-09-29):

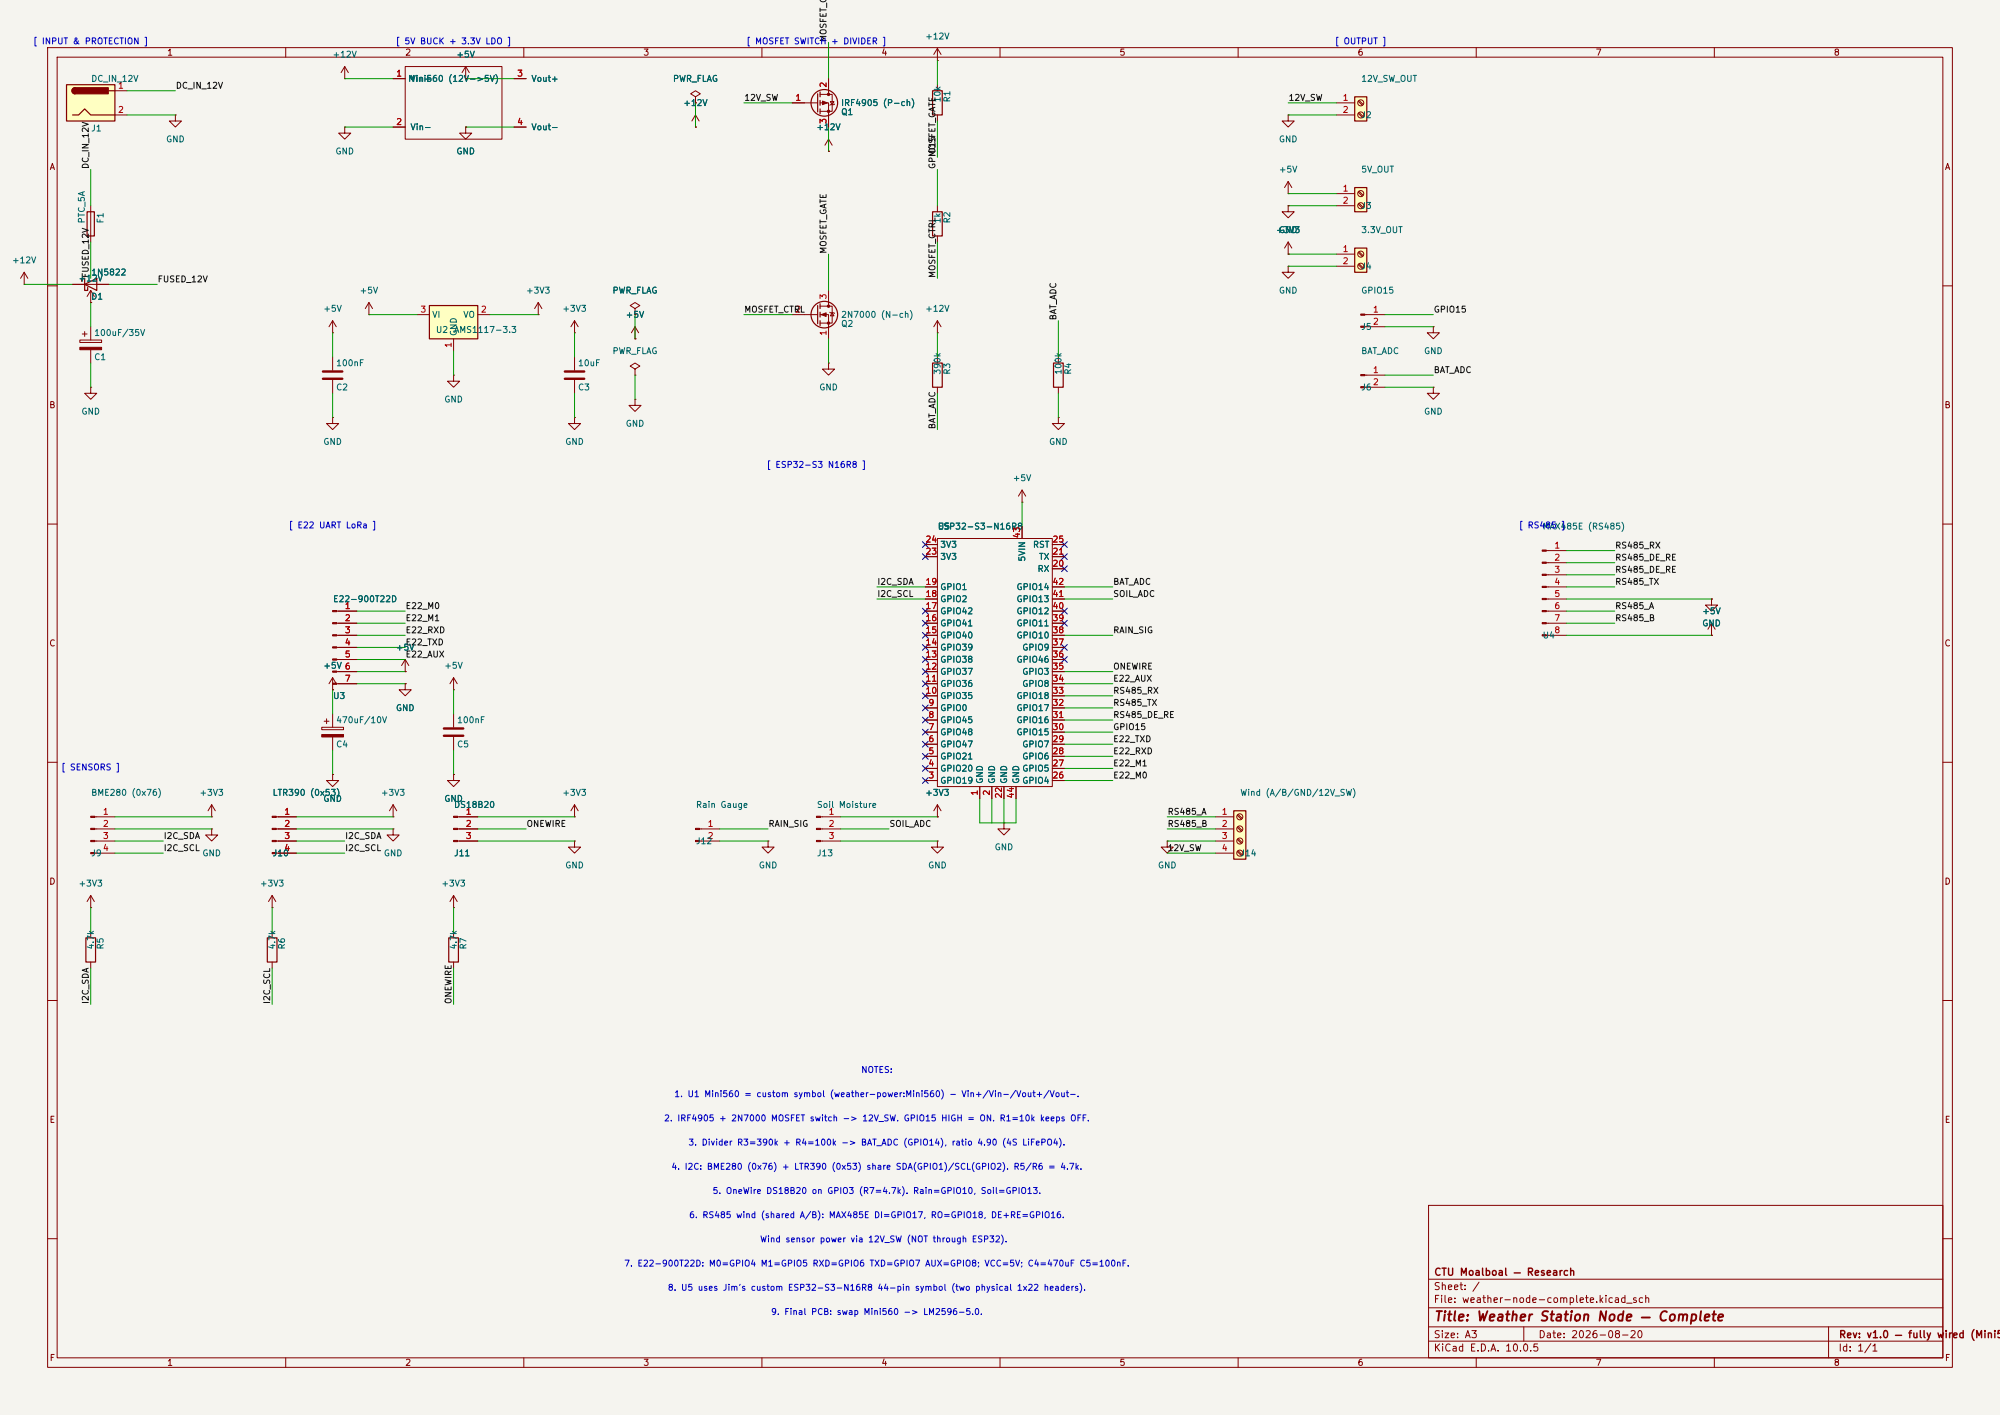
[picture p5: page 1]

2. IRF4905 + 2N7000 MOSFET switch -> 12V_SW. GPIO15 HIGH = ON. R1=10k keeps OFF.

4. I2C: BME280 (0x76) + LTR390 (0x53) share SDA(GPIO1)/SCL(GPIO2). R5/R6 = 4.7k. 5. OneWire DS18B20 on GPIO3 (R7=4.7k). Rain=GPIO10, Soil=GPIO13. 6. RS485 wind (shared A/B): MAX485E DI=GPIO17, RO=GPIO18, DE+RE=GPIO16. 7. E22-900T22D: M0=GPIO4 M1=GPIO5 RXD=GPIO6 TXD=GPIO7 AUX=GPIO8; VCC=5V; C4=470uF C5=100nF. 8. U5 uses Jim's custom ESP32-S3-N16R8 44-pin symbol (two physical 1x22 headers).

CTU Moalboal — Research
Sheet: /
File: weather-node-complete.kicad_sch
Title: Weather Station Node — Complete

F Date: 2026-08-20

KiCad E.D.A. 10.0.5 | Id: 1/1

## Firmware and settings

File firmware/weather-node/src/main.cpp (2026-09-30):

/**
 * main.cpp — Weather Station Node (ESP32-S3 N16R8 + E22-900T22D)
 *
 * Diagnostic Test Mode:
 *   - Live sensor telemetry output to Serial (115200 baud) every 2 seconds
 *   - Interactive Serial commands ('s'=scan I2C, 'r'=reset rain, 'm'=toggle MOSFET)
 *   - RGB LED (WS2812/GPIO48) green flash on each reading cycle
 */

#include <Arduino.h>
#include <Adafruit_NeoPixel.h>
#include "config.h"
#include "config_server.h"
#include "lora.h"
#include "sensors.h"
#include "packet.h"

// ── RGB LED (Native ESP32-S3 Hardware RMT) ────────────────────────
void ledSet(uint8_t r, uint8_t g, uint8_t b) {
  neopixelWrite(PIN_RGB_LED, r, g, b);
}

void ledOff() {
  neopixelWrite(PIN_RGB_LED, 0, 0, 0);
}

void ledBoot() {
  for (int i = 0; i < 30; i++) {
    ledSet(0, 0, i);
    delay(10);
  }
  ledOff();
}

void ledSensor() {
  ledSet(0, 10, 15); // Calm dim cyan
}

void ledTXOk() {
  ledSet(0, 20, 0); // Gentle green blip
  delay(60);
  ledOff();
}

void ledTXFail() {
  ledSet(25, 0, 0); // Gentle red
  delay(150);
  ledOff();
}

void ledError() {
  for (int i = 0; i < 3; i++) {
    ledSet(25, 0, 0);
    delay(100);
    ledOff();
    delay(100);
  }
}

// ── Production Cycle ───────────────────────────────────────────────
void runProductionCycle() {
  esp_sleep_wakeup_cause_t reason = esp_sleep_get_wakeup_cause();
  Serial.printf("Wake reason: %s\n",
    reason == ESP_SLEEP_WAKEUP_TIMER ? "timer" : "other");

  if (!loraInit()) {
    Serial.println("FATAL: LoRa init failed");
    ledError();
    loraSleep();
    esp_sleep_enable_timer_wakeup(rtConfig.sleep_interval_s * 1000000ULL);
    esp_deep_sleep_start();
  }

  ledSensor();
  sensorsInit();
  SensorData data = sensorsRead(rtConfig.node_id);

#if PACKET_JSON
  String payload = packetToJson(data);
  Serial.print("Payload: "); Serial.println(payload);
  loraSend(payload) ? (Serial.println("TX OK"), ledTXOk())
                    : (Serial.println("TX FAIL"), ledTXFail());
#else
  uint8_t buf[32];
  size_t len = packetToBinary(data, buf, sizeof(buf));
  loraSend(buf, len) ? (Serial.println("TX OK"), ledTXOk())
                     : (Serial.println("TX FAIL"), ledTXFail());
#endif

  ledOff();
  loraSleep();
  Serial.printf("Sleeping %d s...\n", rtConfig.sleep_interval_s);
  Serial.flush();
  esp_sleep_enable_timer_wakeup(rtConfig.sleep_interval_s * 1000000ULL);
  esp_deep_sleep_start();
}

// ── Setup ──────────────────────────────────────────────────────────
void setup() {
  ledOff();

  Serial.begin(115200);
  delay(1500);
  ledBoot();

  Serial.println();
  Serial.println("======================================================");
  Serial.printf("  Weather Node %d Diagnostic Firmware — v%s\n", NODE_ID, FIRMWARE_VERSION);
  Serial.printf("  Chip: %s | Mode: %s\n",
    ESP.getChipModel(), TEST_MODE ? "HARDWARE DIAGNOSTIC TEST" : "PRODUCTION");
  Serial.println("======================================================");

#if TEST_MODE
  Serial.println("\n[WEB] Starting LittleFS Web Server & Dual WiFi...");
  configPortalStart();
  Serial.println("\n[READY] Web Server ready. Accessible at:");
  Serial.println("  -> http://weather.local");
  Serial.println("  -> http://192.168.4.1 (Connect to WiFi 'WeatherNode-1')");

  Serial.println("\n[INIT] Initializing hardware peripherals and sensors...");
  sensorsInit();

  Serial.println("\nType commands in Serial Monitor:");
  Serial.println("  's' -> Re-scan I2C bus");
  Serial.println("  'r' -> Reset rain gauge tips count");
  Serial.println("  'm' -> Toggle MOSFET sensor power switch");
  Serial.println("------------------------------------------------------\n");
#else
  configLoad();
  runProductionCycle();
#endif
}

// ── Diagnostic Loop (Runs when TEST_MODE is true) ──────────────────
#if TEST_MODE
static unsigned long lastReadingTime = 0;
static bool mosfetState = true;

void handleSerialCommands() {
  if (Serial.available()) {
    char c = Serial.read();
    if (c == 's' || c == 'S') {
      Serial.println("\n--- MANUAL I2C RESCAN ---");
      sensorsScanI2C();
      Serial.println("-------------------------\n");
    } else if (c == 'r' || c == 'R') {
      getRainTips(); // Reset counter
      Serial.println("\n[Rain] Tips counter reset to 0.\n");
    } else if (c == 'm' || c == 'M') {
      mosfetState = !mosfetState;
      if (mosfetState) {
        sensorsPowerOn();
        Serial.println("\n[MOSFET] Power rail turned ON (HIGH).\n");
      } else {
        sensorsPowerOff();
        Serial.println("\n[MOSFET] Power rail turned OFF (LOW).\n");
      }
    }
  }
}
#endif

void loop() {
#if TEST_MODE
  configPortalLoop();
  handleSerialCommands();

  if (!isBmeWorking()) {
    static unsigned long lastI2cRetry = 0;
    if (millis() - lastI2cRetry >= 3000) {
      lastI2cRetry = millis();
      sensorsScanI2C();
    }
  }

  if (millis() - lastReadingTime >= 2000) {
    lastReadingTime = millis();

    ledSensor();
    SensorData d = sensorsRead(NODE_ID);

    // Read the averaged ADC sample FIRST, then derive both the pack voltage and
    // the raw-mV readout from that same cached sample — otherwise the two
    // numbers shown side by side come from different, noisy conversions.
    uint32_t batRawMv = readBatteryRawMilliVolts();
    float batV = readBatteryVoltage();
    uint32_t soilRawMv = analogReadMilliVolts(PIN_SOIL_MOIST);

    // Update thread-safe cache for Core 0 Web Server
    updateTelemetryCache(d, batV, batRawMv, soilRawMv);

    Serial.println("======================================================");
    Serial.printf(" [DIAGNOSTIC] Node %d Telemetry | Up: %lu s\n", NODE_ID, millis() / 1000);
    Serial.println("======================================================");
    Serial.printf(" Battery Voltage : %.2f V  (ADC raw: %u mV)\n", batV, batRawMv);
    Serial.printf(" MOSFET Switch   : %s (GPIO%d)\n", mosfetState ? "ON (12V_SW active)" : "OFF", PIN_SENSOR_PWR);
    Serial.printf(" BME280 Readings : %.1f °C  |  %.1f %%  |  %.1f hPa\n", d.temperature, d.humidity, d.pressure);
    Serial.printf(" Rain Gauge Tips : %u tips (%.2f mm)\n", d.rain_tips, d.rain_tips * RAIN_TIP_MM);

    if (d.wind_speed >= 0.0f) {
      Serial.printf(" RS485 Wind Speed: %.1f m/s (Slave ID %d OK)\n", d.wind_speed, MODBUS_ANEMOMETER);
    } else {
      Serial.printf(" RS485 Wind Speed: TIMEOUT / NO RESPONSE (Slave ID %d)\n", MODBUS_ANEMOMETER);
    }

    if (d.wind_dir <= 360) {
      Serial.printf(" RS485 Wind Dir  : %u ° (Slave ID %d OK)\n", d.wind_dir, MODBUS_WIND_VANE);
    } else {
      Serial.printf(" RS485 Wind Dir  : TIMEOUT / NO RESPONSE (Slave ID %d)\n", MODBUS_WIND_VANE);
    }

    Serial.printf(" Soil Moisture   : %u %%  (ADC raw: %u mV)\n", d.soil_moisture, soilRawMv);
    Serial.println("------------------------------------------------------");
    Serial.printf(" JSON Payload    : %s\n", packetToJson(d).c_str());
    Serial.println("======================================================\n");

    ledTXOk(); // Green flash to indicate successful cycle
  }
#endif
}

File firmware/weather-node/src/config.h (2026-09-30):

/**
 * config.h — Node-specific configuration (ESP32-S3 N16R8)
 *
 * Edit this per deployed node. Every node gets a unique NODE_ID.
 * GPIO pin assignments should match your physical wiring.
 *
 * ESP32-S3 N16R8 constraints:
 *   - Octal PSRAM uses GPIO26-37 (unavailable)
 *   - Native USB uses GPIO19 (D-) / GPIO20 (D+)
 *   - Safe GPIOs: 1-18, 21, 38-48
 *   - ADC1: GPIO1-10
 *   - ADC2: GPIO11-20
 */

#ifndef CONFIG_H
#define CONFIG_H

// ── Node Identity ──────────────────────────────────────────────────
#define NODE_ID          1         // UNIQUE per node (1–255)
#define NODE_NAME        "Node 1"
#define FIRMWARE_VERSION "1.1.0-e22"

// ── Sleep ──────────────────────────────────────────────────────────
#define SLEEP_INTERVAL_S 5        // Deep sleep duration (seconds) — TEST MODE
#define SLEEP_INTERVAL_US (SLEEP_INTERVAL_S * 1000000ULL)
#define TEST_MODE         true     // Skip deep sleep + LoRa for testing

// ── LoRa Radio (Ebyte E22-900T22D, UART transparent mode) ──────────
// Air frequency/channel, air data rate and TX power are stored inside the
// E22 module. Both ends must be configured identically before deployment.
#define E22_UART_BAUD       9600
#define E22_AUX_TIMEOUT_MS  3000
#define E22_MODE_SETTLE_MS  50

// ── GPIO Pin Assignments (ESP32-S3 safe pins) ──────────────────────
// E22-900T22D UART LoRa
#define PIN_E22_M0       4
#define PIN_E22_M1       5
#define PIN_E22_RXD      6   // ESP32 TX -> E22 RXD
#define PIN_E22_TXD      7   // E22 TXD -> ESP32 RX
#define PIN_E22_AUX      8   // HIGH = module ready

// I2C bus (shared: BME280 @ 0x76/0x77, LTR390 @ 0x53)
#define PIN_I2C_SDA      1
#define PIN_I2C_SCL      2

// OneWire (DS18B20)
#define PIN_ONEWIRE      3

// Rain gauge — tipping bucket (interrupt pulse counter)
#define PIN_RAIN         10

// RS485 bus (Anemometer + Wind Vane — Modbus RTU)
// DIYMORE auto-direction module: no DE/RE pin needed
#define PIN_RS485_RX     18       // ESP32-S3 UART1 RX (from RS485 module TXD)
#define PIN_RS485_TX     17       // ESP32-S3 UART1 TX (to RS485 module RXD)

// RS485 Modbus slave IDs
#define MODBUS_ANEMOMETER 1       // Wind speed sensor
#define MODBUS_WIND_VANE  2       // Wind direction sensor

// Soil moisture (capacitive, analog)
#define PIN_SOIL_MOIST   13

// Battery voltage divider — ADC2
#define PIN_BATTERY      14

// Sensor power MOSFET gate (switches 12V_SW and sensor power rails)
#define PIN_SENSOR_PWR   15

// Status RGB LED (WS2812/SK6812 — onboard)
#define PIN_RGB_LED      48       // Common on ESP32-S3-DevKitC
#define NUM_RGB_LEDS     1        // Single onboard LED

// ── Spare pins ─────────────────────────────────────────────────────
// GPIO11, GPIO12, GPIO16, GPIO21, GPIO38-47

// ── Battery Divider (12V System) ────────────────────────────────────
// Actual PCB: R1 = 47kΩ (top), R2 = 10kΩ (bottom)
// V_adc = V_batt × R2/(R1+R2) = V_batt × 10/(47+10) = V_batt × 0.1754
// Divider ratio = (47 + 10) / 10 = 5.70
//
// Sense tap: 12V rail AFTER the PTC fuse but BEFORE the 1N5822 Schottky.
// Tapping after the diode adds its ~0.33 V forward drop, which on LiFePO4's
// flat discharge curve is worth roughly 20 percentage points of state of charge.
#define BAT_R1           47.0     // kΩ (top resistor)
#define BAT_R2           10.0     // kΩ (bottom resistor)
#define BAT_DIVIDER      ((BAT_R1 + BAT_R2) / BAT_R2)

// The ESP32 ADC jitters by a few mV, and 12 mV at the pack is already 1% of
// state of charge on LiFePO4. Oversample and average to settle it.
#define BAT_ADC_SAMPLES  32       // reads averaged per measurement
#define BAT_ADC_CACHE_MS 500      // reuse one averaged sample within a read cycle

// Residual variation after averaging is real load sag (WiFi bursts through the
// PTC fuse), so smooth it across cycles too.
#define BAT_ADC_EMA_ALPHA  0.25f  // 0 = frozen, 1 = no smoothing
#define BAT_ADC_EMA_SNAP_V 0.5f   // step larger than this snaps instead of slewing

// ── Calibration ─────────────────────────────────────────────────────
#define RAIN_TIP_MM      0.2794   // mm per bucket tip

// ── Sensor Toggle ───────────────────────────────────────────────────
#define HAS_BME280       true     // I2C 0x76/0x77 — temp, humidity, pressure
#define HAS_DS18B20      true     // OneWire — accurate temp
#define HAS_LTR390       false    // I2C 0x53 — UV index, ambient light
#define HAS_RAIN_GAUGE   true     // Tipping bucket, interrupt counter
#define HAS_ANEMOMETER   true     // RS485 Modbus — wind speed (m/s)
#define HAS_WIND_VANE    true     // RS485 Modbus — wind direction (°)
#define HAS_SOIL_MOIST   true     // Capacitive analog

#endif // CONFIG_H

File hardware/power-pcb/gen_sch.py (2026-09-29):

#!/usr/bin/env python3
"""
Generate proper KiCad schematic (.kicad_sch) for weather station power supply.

Components: 19 (J1, D1, C1-C4, U1-U2, Q1-Q2, R1-R4, J2-J6)
Nets: 9 (12V_IN_RAW, 12V, GND, 5V, 3.3V, 12V_SW, GPIO_SIG, GATE, BAT_ADC)

Layout (left to right):
  INPUT SECTION:     J1 → D1 → C1
  BUCK SECTION:      U1 (MP1584) → C2
  LDO SECTION:       U2 (HT7333-A) + C3 + C4
  SWITCH SECTION:    Q1 (IRF9540) + Q2 (2N7000) + R1 + R2
  DIVIDER:           R3 + R4
  OUTPUTS:           J2 (12V_SW), J3 (5V), J4 (3.3V), J5 (GPIO15), J6 (BAT_ADC)
"""

import os, uuid

PROJECT_DIR = os.path.expanduser("~/dev/projects/weather-station/hardware/power-pcb")
PROJECT_NAME = "weather-power-pcb"

def U(): return str(uuid.uuid4())

# Symbol positions in schematic units (mils), 1 inch = 1000 mils
# Standard grid: 50 mils
G = 50  # grid spacing

def pos(x, y):
    """Convert grid units to mils for schematic placement."""
    return f"{x * G} {y * G}"

def at_xy(x, y, rot=0):
    """Return just the coordinate string for at."""
    return f"{pos(x,y)} {rot}"

def at_tag(x, y, rot=0):
    """Return full (at x y rot) tag."""
    return f"(at {pos(x,y)} {rot})"

# ── Build schematic ──────────────────────────────────────────────────
def generate():
    lines = []

    # Header
    lines.append(f'(kicad_sch (version 20231120) (generator "eeschema")')
    lines.append(f'  (uuid {U()})')
    lines.append(f'  (paper "A4")')

    # Title block
    lines.append(f'  (title_block')
    lines.append(f'    (title "Weather Station — Power Supply")')
    lines.append(f'    (date "2026-06-10")')
    lines.append(f'    (rev "v1.0")')
    lines.append(f'  )')

    # ── Custom library symbols ─────────────────────────────────────
    lines.append(f'  (lib_symbols')

    # MP1584 custom symbol (4-pin block: Vin+, Vin-, Vout+, Vout-)
    lines.append(f'    (symbol "weather-power:MP1584"')
    lines.append(f'      (in_bom yes) (on_board yes)')
    lines.append(f'      (property "Reference" "U" (at 0 -5.08 0))')
    lines.append(f'      (property "Value" "MP1584" (at 0 5.08 0))')
    lines.append(f'      (property "Footprint" "" (at 0 0 0))')
    lines.append(f'      (symbol "MP1584_0_1"')
    lines.append(f'        (rectangle (start -7.62 -7.62) (end 7.62 7.62))')
    for i, (name, x, y, rot) in enumerate([
        ("Vin+", -7.62, 3.81, 180), ("Vin-", -7.62, -3.81, 180),
        ("Vout+", 7.62, 3.81, 0), ("Vout-", 7.62, -3.81, 0),
    ]):
        lines.append(f'        (pin passive line (at {x} {y} {rot}) (length 2.54)')
        lines.append(f'          (name "{name}" (effects (font (size 1.27 1.27))))')
        lines.append(f'          (number "{i+1}" (effects (font (size 1.27 1.27)))))')
    lines.append(f'      )')
    lines.append(f'    )')

    # HT7333-A custom symbol (3-pin: Vout, GND, Vin)
    lines.append(f'    (symbol "weather-power:HT7333A"')
    lines.append(f'      (in_bom yes) (on_board yes)')
    lines.append(f'      (property "Reference" "U" (at 0 -5.08 0))')
    lines.append(f'      (property "Value" "HT7333-A" (at 0 5.08 0))')
    lines.append(f'      (property "Footprint" "" (at 0 0 0))')
    lines.append(f'      (symbol "HT7333A_0_1"')
    lines.append(f'        (rectangle (start -5.08 -5.08) (end 5.08 5.08))')
    for i, (name, x, y, rot) in enumerate([
        ("Vout", -5.08, 2.54, 180), ("GND", 0, -5.08, 270),
        ("Vin", 5.08, 2.54, 0),
    ]):
        lines.append(f'        (pin passive line (at {x} {y} {rot}) (length 2.54)')
        lines.append(f'          (name "{name}" (effects (font (size 1.27 1.27))))')
        lines.append(f'          (number "{i+1}" (effects (font (size 1.27 1.27)))))')
    lines.append(f'      )')
    lines.append(f'    )')

    lines.append(f'  )')

    # ── Placed symbols (direct children of kicad_sch, NOT inside symbol_instances!) ─
    # symbol_instances stays empty
    lines.append(f'  (symbol_instances)')

    # --- INPUT SECTION (left column, x=2-6) ---
    # J1 - Barrel Jack (x=2, y=18)
    _add_symbol(lines, "Connector:Barrel_Jack_Switch", "J1", 2, 18, 0)
    # D1 - Schottky diode (x=4, y=18)
    _add_symbol(lines, "Device:D_Schottky", "D1", 4, 18, 0)
    # C1 - 100uF/25V (x=6, y=18)
    _add_symbol(lines, "Device:C_Polarized", "C1", 6, 18, 0)

    # --- BUCK SECTION (center-left, x=8-12) ---
    # U1 - MP1584 (x=10, y=16)
    _add_symbol(lines, "weather-power:MP1584", "U1", 10, 16, 0)
    # C2 - 100uF/16V (x=12, y=16)
    _add_symbol(lines, "Device:C_Polarized", "C2", 12, 16, 0)

    # --- LDO SECTION (center, x=14-18) ---
    # U2 - HT7333-A (x=16, y=16)
    _add_symbol(lines, "weather-power:HT7333A", "U2", 16, 16, 0)
    # C3 - 10uF (x=14, y=12)
    _add_symbol(lines, "Device:C_Polarized", "C3", 14, 12, 0)
    # C4 - 10uF (x=18, y=12)
    _add_symbol(lines, "Device:C_Polarized", "C4", 18, 12, 0)

    # --- SWITCH SECTION (right, x=20-26) ---
    # Q1 - P-ch MOSFET (x=22, y=16)
    _add_symbol(lines, "Device:Q_PMOS_GSD", "Q1", 22, 18, 0)
    # Q2 - N-ch MOSFET (x=22, y=10)
    _add_symbol(lines, "Device:Q_NMOS_GSD", "Q2", 22, 10, 0)
    # R1 - 10k (x=24, y=18)
    _add_symbol(lines, "Device:R", "R1", 24, 18, 90)
    # R2 - 1k (x=24, y=10)
    _add_symbol(lines, "Device:R", "R2", 24, 10, 90)

    # --- DIVIDER (x=26-28, y=6) ---
    # R3 - 330k (x=26, y=6)
    _add_symbol(lines, "Device:R", "R3", 26, 6, 0)
    # R4 - 100k (x=28, y=6)
    _add_symbol(lines, "Device:R", "R4", 28, 6, 0)

    # --- OUTPUT TERMINALS (rightmost, x=28-30) ---
    # J2 - 12V_SW (x=30, y=18)
    _add_symbol(lines, "Connector:Screw_Terminal_01x02", "J2", 30, 18, 0)
    # J3 - 5V_OUT (x=30, y=14)
    _add_symbol(lines, "Connector:Screw_Terminal_01x02", "J3", 30, 14, 0)
    # J4 - 3.3V_OUT (x=30, y=10)
    _add_symbol(lines, "Connector:Screw_Terminal_01x02", "J4", 30, 10, 0)
    # J5 - GPIO15 (x=26, y=12)
    _add_symbol(lines, "Connector:Conn_01x02_Pin", "J5", 26, 12, 0)
    # J6 - BAT_ADC (x=30, y=6)
    _add_symbol(lines, "Connector:Conn_01x02_Pin", "J6", 30, 6, 0)

    # --- POWER PORTS ---
    _add_power_port(lines, "+12V", 2, 20, 0)     # 12V input rail label
    _add_power_port(lines, "+5V", 12, 20, 0)      # 5V rail label
    _add_power_port(lines, "+3.3V", 18, 20, 0)    # 3.3V rail label

    # --- GROUND SYMBOLS ---
    _add_ground(lines, 2, 16)
    _add_ground(lines, 6, 16)
    _add_ground(lines, 12, 14)
    _add_ground(lines, 14, 10)
    _add_ground(lines, 18, 10)
    _add_ground(lines, 22, 8)
    _add_ground(lines, 26, 4)
    _add_ground(lines, 28, 4)

    # Output terminal ground references
    _add_ground(lines, 30, 16)  # J2 GND
    _add_ground(lines, 30, 12)  # J3 GND
    _add_ground(lines, 30, 8)   # J4 GND

    # ── Wires (direct children) ────────────────────────────────────
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

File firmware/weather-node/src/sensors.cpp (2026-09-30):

/**
 * sensors.cpp — Sensor reading and hardware diagnostics implementation
 *
 * All sensors are powered via a MOSFET gate (PIN_SENSOR_PWR / GPIO15)
 * to eliminate quiescent current drain during deep sleep.
 */

#include "sensors.h"
#include <Wire.h>

// ── Sensor libraries ───────────────────────────────────────────────
#if HAS_BME280
#include <Adafruit_BME280.h>
#include <Adafruit_BMP280.h>
static Adafruit_BME280 bme;
static Adafruit_BMP280 bmp;
static bool hasBmeWorking = false;
static bool hasBmpWorking = false;
static uint8_t bmeAddress = 0;
#endif

#if HAS_DS18B20
#include <OneWire.h>
#include <DallasTemperature.h>
static OneWire oneWire(PIN_ONEWIRE);
static DallasTemperature ds18b20(&oneWire);
static int dsDeviceCount = 0;
#endif

// ── Rain gauge (pulse counter via interrupt) ───────────────────────
#if HAS_RAIN_GAUGE
static volatile uint16_t rainTips = 0;

void IRAM_ATTR rainISR() {
  rainTips++;
}
#endif

// ── RS485 Wind Sensors (Modbus RTU over UART1) ─────────────────────
#if HAS_ANEMOMETER || HAS_WIND_VANE
#include <ModbusMaster.h>
static HardwareSerial rs485Serial(1);
static ModbusMaster mbAnemo;
static ModbusMaster mbVane;
static bool rs485Initialized = false;
#endif

// ── Power Management ───────────────────────────────────────────────
static bool mosfetActive = false;

void sensorsPowerOn() {
  digitalWrite(PIN_SENSOR_PWR, HIGH);
  mosfetActive = true;
  delay(50); // 50ms stabilization for 12V_SW and 3.3V sensors
}

void sensorsPowerOff() {
  digitalWrite(PIN_SENSOR_PWR, LOW);
  mosfetActive = false;
}

bool getMosfetState() {
  return mosfetActive;
}

void setMosfetState(bool on) {
  if (on) sensorsPowerOn();
  else sensorsPowerOff();
}

// ── I2C Bus Scanner ────────────────────────────────────────────────
// The I2C pins are owned by the Wire peripheral. Never call pinMode() on them
// after Wire.begin(): that detaches them from the peripheral and the bus stops
// ACKing until reboot. Attach the bus once here, then only ever scan.
static bool i2cStarted = false;

void sensorsScanI2C() {
  Serial.println("[I2C] Scanning bus (SDA=GPIO1, SCL=GPIO2)...");

  if (!i2cStarted) {
    pinMode(PIN_I2C_SDA, INPUT_PULLUP);
    pinMode(PIN_I2C_SCL, INPUT_PULLUP);
    delay(10);
    if (digitalRead(PIN_I2C_SDA) == LOW || digitalRead(PIN_I2C_SCL) == LOW) {
      Serial.println("  -> WARNING: I2C bus is stuck LOW! (SDA or SCL grounded or 3.3V bus unpowered).");
      Serial.println("  -> Check 12V power supply to terminal and ensure SDA/SCL are not swapped.");
      return;
    }

    Wire.begin(PIN_I2C_SDA, PIN_I2C_SCL);
    Wire.setTimeOut(50);
    i2cStarted = true;
  }

  uint8_t count = 0;
  for (uint8_t addr = 1; addr < 127; addr++) {
    Wire.beginTransmission(addr);
    uint8_t err = Wire.endTransmission();
    if (err == 0) {
      Serial.printf("  -> Found I2C device at 0x%02X", addr);
      if (addr == 0x76 || addr == 0x77) {
        Serial.print(" (BME280 / BMP280)");
#if HAS_BME280
        if (!hasBmeWorking && !hasBmpWorking) {
          if (bme.begin(addr, &Wire)) {
            hasBmeWorking = true;
            bmeAddress = addr;
            Serial.print(" -> Initialized OK!");
          } else if (bmp.begin(addr)) {
            hasBmpWorking = true;
            bmeAddress = addr;
            Serial.print(" -> Initialized BMP280 OK!");
          }
        }
#endif
      } else if (addr == 0x53) {
        Serial.print(" (LTR390)");
      }
      Serial.println();
      count++;
    }
  }
  if (count == 0) {
    Serial.println("  -> No I2C devices found! Check wiring and 3.3V power.");
  }
}

// ── Battery ADC Calibration ────────────────────────────────────────
// Two stages of conditioning, because LiFePO4's discharge curve is so flat that
// a few mV of ADC jitter becomes several % of apparent state of charge:
//
//   1. Oversample BAT_ADC_SAMPLES times, drop the extreme samples, average.
//      Kills the ADC's own noise.
//   2. Smooth the result with an EMA across read cycles. What survives step 1
//      is mostly REAL variation — WiFi current bursts sagging the pack through
//      the PTC fuse — which only a slower filter can remove.
//
// A large step (battery reconnected, load removed) snaps the filter instead of
// being slewed, so the reading never lags behind a genuinely new value.
//
// The averaged sample is cached for BAT_ADC_CACHE_MS so every caller in one read
// cycle (sensorsRead, the telemetry cache, the raw-mV readout) reports the SAME
// sample instead of three unrelated ones.
static uint32_t      batteryMvCache     = 0;
static unsigned long batteryMvCacheAt   = 0;
static float         batteryVoltsFilter = 0.0f;   // EMA of pack volts
static bool          batteryFilterValid = false;

// Take one oversampled conversion and advance the EMA exactly once.
static void batterySampleAndFilter() {
  uint32_t sum = 0;
  uint32_t lo  = UINT32_MAX;
  uint32_t hi  = 0;

  for (int i = 0; i < BAT_ADC_SAMPLES; i++) {
    uint32_t mv = analogReadMilliVolts(PIN_BATTERY);
    sum += mv;
    if (mv < lo) lo = mv;
    if (mv > hi) hi = mv;
    delayMicroseconds(200);
  }

  sum -= lo;  // discard the single lowest and
  sum -= hi;  // single highest sample as outliers

  batteryMvCache   = sum / (BAT_ADC_SAMPLES - 2);
  batteryMvCacheAt = millis();

  const float volts = (batteryMvCache * BAT_DIVIDER) / 1000.0f;

  float delta = volts - batteryVoltsFilter;
  if (delta < 0.0f) delta = -delta;

  if (!batteryFilterValid || delta > BAT_ADC_EMA_SNAP_V) {
    batteryVoltsFilter = volts;   // first reading, or a genuine step change
    batteryFilterValid = true;
  } else {
    batteryVoltsFilter += BAT_ADC_EMA_ALPHA * (volts - batteryVoltsFilter);
  }
}

uint32_t readBatteryRawMilliVolts() {
  unsigned long now = millis();
  if (batteryMvCacheAt == 0 || (now - batteryMvCacheAt) >= BAT_ADC_CACHE_MS) {
    batterySampleAndFilter();
  }
  return batteryMvCache;   // always the raw (unsmoothed) averaged sample
}

float readBatteryVoltage() {
  // Uses the ESP32 calibrated millivolts (eFuse ADC curve), averaged then smoothed.
  readBatteryRawMilliVolts();   // ensures one fresh sample + EMA step this cycle
  return batteryVoltsFilter;
}

// ── Soil Moisture ──────────────────────────────────────────────────
uint8_t readSoilMoisture() {
#if HAS_SOIL_MOIST
  uint32_t mv = analogReadMilliVolts(PIN_SOIL_MOIST);
  // Typical capacitive v1.2: ~2600mV dry air -> ~1200mV submerged in water
  if (mv >= 2600) return 0;
  if (mv <= 1200) return 100;
  return (uint8_t)map(mv, 2600, 1200, 0, 100);
#else
  return 0;
#endif
}
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

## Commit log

2026-06-09 Initial commit: weather station monorepo
    - ESP32 firmware (PlatformIO/Arduino): sensor reading, LoRa TX, deep sleep
    - RPi gateway: single-channel LoRa-to-MQTT bridge (Python)
    - Server ingestor: MQTT-to-PostgreSQL (TypeScript/Node.js)
    - Database: migrations, seeds, daily aggregates
    - Docker Compose: PostgreSQL + Mosquitto + Grafana
    - VS Code workspace for SSH remote dev
    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
2026-06-09 feat: SvelteKit dashboard with sidebar layout + Drizzle ORM
    - Svelte 5 + Tailwind CSS v4 + Lucide icons
    - Sidebar/Topbar/AppShell layout matching conventions
    (breadcrumbs, search, notifications, add button, profile dropdown)
    - Drizzle ORM schema for sensor_nodes, sensor_readings, sensor_daily
    - API routes: /api/nodes, /api/nodes/[id], /api/readings
    - Pages: Overview (stats + latest readings), Nodes (grid + pagination),
    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
2026-09-29 Refactor code structure for improved readability and maintainability
    [lora-e22-900t22d.kicad_sch, power-supply.kicad_sch, weather-node-complete-before-final.kicad_sch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]
2026-09-30 feat: initialize weather-node web UI with Svelte and Tailwind CSS
    - Added app.css for Tailwind CSS integration.
    - Created app.html as the main HTML template.
    - Implemented +layout.svelte for layout structure and styling.
    - Configured +layout.ts for prerendering and SSR settings.
    - Developed +page.svelte for telemetry display and controls.
    - Set up svelte.config.js for static site generation.
    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
    [partitions_16mb.csv]
